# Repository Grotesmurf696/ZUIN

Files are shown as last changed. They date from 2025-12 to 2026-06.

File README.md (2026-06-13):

# ZUIN
*ZUIN helpt kinderen en ouders meer te weten te komen en bevorderd communicatie over energieverbruik in huis* 

🛠️ Built by ``Sam Verkimpe``  & ``Maxim Depever`` & ``Jitse Van Laer ``  
🔥 Supervised by ``prof. dr. Bas Baccarne``, ``Yannick Christiaens`` & ``Wouter Devriese``    
🌱 Grown at ``Ghent University`` 🏛️ ``Industrial Design Engineering`` ([project overview](https://github.com/basbaccarne/human-centered-design))       

*Latest update: 13/06/2026*   

## General overview
ZUÏN is een systeem van interactieve producten voor kinderen, interfaces voor de ouders en meetapperatuur voor jouw huis. 

Het bevordert de kennis over energieverbruik bij kinderen, terwijl ze op een speelse en interactieve manier zuinig leren vebruiken. Ook initieert het de interactie tussen ouder en kind om zo ook hun een steentje te laten bijdragen.

Kinderen weten vaak niet hoe energieverbruik echt in elkaar zit en welk apparaat nu het meeste verbruikt. Niet alleen de kinderen maar ook de ouders weten niet dat hun dagelijkse routines soms roet in het energieverbruik gooien. 

Aan het midden van ZUIN ligt het horloge. Dit horloge is gemaakt voor kinderen. Het horloge wordt gebruikt als normaal uurwerk doorheen de dag, maar wanneer de kinderen thuis komen krijgt dit horloge een extra functie. Een virtuele en speelse interface waardat op een overzichtelijke manier een beeld wordt geschept van het ogenblikkelijk energieverbruik in huis.
<p align="center">
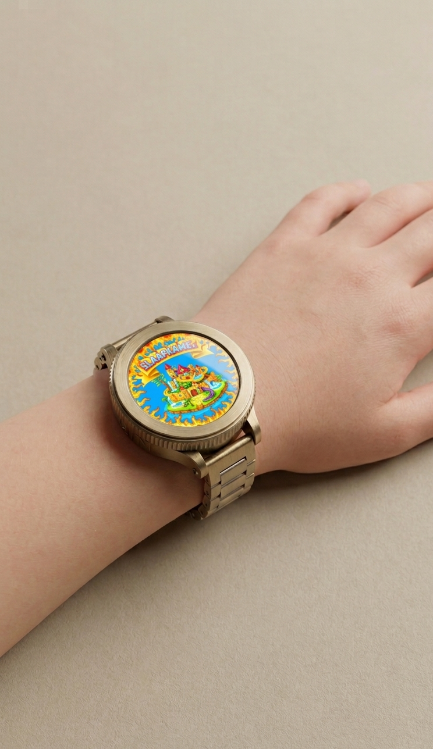
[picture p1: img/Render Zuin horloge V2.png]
  
  <br>
  <em>Figuur 1: Representatie van het ZUIN horloge.</em>
</p>

## Introductie
Energieverbruik in huishoudens vormt een belangrijk maatschappelijk en ecologisch vraagstuk. Hoewel technologische oplossingen zoals digitale meters en monitoring-applicaties steeds vaker worden ingezet, blijft het energieverbruik voor veel gebruikers abstract en moeilijk te interpreteren. In gezinscontexten wordt dit probleem nog complexer, omdat energieverbruik het resultaat is van gedeelde routines en gedragingen, waarbij ook kinderen een belangrijke maar vaak onbewuste rol spelen.

Kinderen groeien op in een wereld waarin energie vanzelfsprekend beschikbaar is, zonder een duidelijk begrip van herkomst, kost of impact. Op school wordt wel een basis van milieubewustzijn aangeleerd, maar vooral het voorbeeld en de druk van de ouders maakt effectief verschil (Aguirre-Bielschowsky et al., 2018) [^1] . Klassieke energiefeedback zoals apps, grafieken en cijfers sluiten nauwelijks aan bij de leefwereld van kinderen. Bovendien ervaren ook de ouders het energieverbruik vaak als een “black box”: ze krijgen wel cijfers te zien, maar missen concrete, begrijpbare aanknopingspunten om hun dagelijks gedrag bij te sturen. Energie wordt ervaren als iets onzichtbaars: het is er altijd, komt uit het stopcontact, en verdwijnt weer zonder duidelijke koppeling tussen gedrag en gevolg. Dit maakt het moeilijk om duurzame gewoontes aan te leren, zeker bij jonge gebruikers.

Vanuit deze problematiek werd **ZUIN** ontwikkeld: een **interactief** systeem dat energieverbruik op een **speelse** en **begrijpbare** manier zichtbaar maakt voor kinderen, en tegelijk de **dialoog tussen ouder en kind** stimuleert. Het project focust niet op het technisch optimaliseren van installaties, maar op **bewustmaking, educatie en langdurige gedragsverandering** via dagelijkse **interactie en betekenisvolle** feedback.

## Inhoudstafel

1. [Methodologie](./docs/methodologie.md)
2. [Discovery](./docs/discovery.md)
3. [Definition](./docs/definition.md)
4. [Develop I](./docs/Develop_I.md)
5. [Develop II](./docs/Develop_II.md)
6. [Develop III](./docs/Develop_III.md) 
7. [Design Requirements](./docs/design_requirements.md)
8. [Bill of materials](./docs/bom.md)
9. [Conclusie](./docs/Conclusie.md)

## Kritische reflectie
Tijdens dit project werd onderzocht hoe kinderen een rol kunnen spelen in het stimuleren van energiebewust gedrag binnen gezinnen. Door kinderen centraal te plaatsen, werd een vernieuwende invalshoek gekozen. Gedurende het project werden verschillende onderzoeksmethoden toegepast, zoals interviews, benchmarking, prototyping, usability testing en systeemanalyse. Deze combinatie van methodes leverde waardevolle inzichten op in zowel het probleem als mogelijke oplossingsrichtingen.

Een sterke kant van het project was het iteratieve ontwerpproces en het gebruik van snelle prototypes. In een vroege fase werden eenvoudige kartonnen modellen gebruikt om ideeën snel tastbaar te maken en reacties van gebruikers te observeren. In latere fases werden prototypes verder verfijnd met 3D-geprinte onderdelen en een fysieke knuffel voor één van de concepten. Hierdoor konden interacties realistischer getest worden en konden gebruikers concreter feedback geven op de verschillende interfaces.

Elke wave werden participanten voor gebruikerstesten op een andere manier gerekruteerd. Op die manier is er een insteek van een brede waaier aan verschillende meningen in ons project, en zijn we niet beperkt tot maar enkele mensen uit hetzelfde milieu.

In de definition-fase konden we een stand opzetten op dag van de Wetenschap in de UGent Campus Kortrijk. Hier kregen we inzichten van enkele gemotiveerde en geïnteresseerde kinderen, maar ook hun ouders hielpen ons proces verder. 

Daarna maakten we in wave 1 en 2 van de develop-fase gebruik van de faciliteiten van bibliotheek de Krook. We konden ons daar in de inkomhal zetten en zo konden mensen met interesse vrijwillig deelnemen. Dit waren compleet vreemden voor ons. Ze hadden dus ook geen vooroordeel. 

In wave 3 van deze fase, testten we de UX in een klas uit de lagere school. Ook deze kinderen hadden nog niet eerder over ZUÏN gehoord en leverde een nieuwe inkijk. Vanuit een andere hoek kregen we feedback over de CMF. Dit werd namelijk getest op de Scouts. 

Toch kent het project ook enkele beperkingen. Op bepaalde momenten tijdens de definition fase werd enigszins omgekeerd te werk gegaan in het ontwerpproces. Het product requirements document (PRD) werd namelijk deels beïnvloed door het reeds ontwikkelde concept, terwijl idealiter eerst de gebruikersvereisten duidelijk gedefinieerd worden voordat het product wordt vormgegeven. Hierdoor bestaat het risico dat sommige ontwerpkeuzes eerder voortkwamen uit het bestaande concept dan uit een grondige analyse van de behoeften.

Daarnaast had er tijdens de defenition fase meer aandacht besteed kunnen worden aan het marktpotentieel en de reële wenselijkheid van het product. Hier is later wel op teruggekeerd in de develop fase.

Een andere grote beperking in het ontwerp is de invloed op lange termijn. Deze wilden we testen met een ‘hub’ die de energiemeter nabootst en een ‘handheld’ die gelijkend is aan het horloge. De ‘hub’ zou op willekeurige momenten een signaal naar de ‘handheld’ sturen. Dit bootst een piekmoment van energie na. Het kind zou dan naar de ‘hub’ gaan en op de drukknop duwen. Op die manier zou het kind “de energie” uitzetten. Daarbij zou de ouder een korte vragenlijst krijgen om het gedrag van het kind op het moment van de trigger te analyseren. Deze test zou een meerdaagse test zijn, om te testen of het enthousiasme blijft. Echter zijn we daar niet geraakt. Door problemen bij het programmeren is de verbinding tussen de ‘hub’ en de ‘handheld’ pas veel later tot stand gekomen dan gewenst. Hierdoor was er niet meer voldoende tijd om de test nog effectief uit te voeren over meerdere dagen. Dit is zeker nog iets wat zou moeten gebeuren om de value promise van ZUÏN volledig te begrijpen. 

Deze test zou ook inkaart brengen welke triggers en beloningen motiveren. Het moeilijke bij triggers is dat deze moeten opvallen maar niet irriteren. Deze mogen het leven van het kind niet overnemen, maar wel duidelijk genoeg zijn dat het kind er niet overkijkt. Ook dit is iets wat pas zichtbaar is op lange termijn. Een trigger die eerst aantrekkelijk lijkt kan al snel gewoonte worden waardoor het kind er geen aandacht meer aan besteed. Andersom kan een leuke trigger ook snel irriteren. 

Beloningen is een groot onderdeel van ZUÏN. Dit is namelijk de drijfveer van de kinderen. Zeker bij kinderen is dit eveneens iets dat op langere termijn hard kan veranderen. Een kind van 8 tot 12 is veel aan het ontdekken en komt veel nieuwe dingen tegen. Hierdoor wisselen ze snel van interesses. Het is dus belangrijk om een beloningsysteem te gebruiken dat niet uit de mode gaat. We wilden dus eveneens testen bij de lange termijn test van de ‘hub’ en ‘wereable’ hoe motiverend en belangrijk het beloningsysteem daadwerkelijk is.  

## Noot inzake het gebruik van AI
AI werd in de verschillende fases ingezet om het ontwerpproces efficiënt te laten verlopen en te ondersteunen. 
Zo werd in elke fase gebruik gemaakt van een AI die spraak naar tekst convergeert. Zo konden we de opnamebestanden die we tijdens de interviews en testen maakten, om te zetten in een uitgeschreven tekst en dit samen te vatten. Dit gebruikten we ter ondersteuning van de notities die ook werden gemaakt, om zo geen enkele info te missen en al onze aandacht te besteden aan de gebruikers. Daarnaast werd AI gebruikt om de teksten waar nodig te corrigeren en presentabeler te maken.

* **Definition**
  
  Hier werd AI vooral ingeschakeld om efficiënt via Figma Make enkele interfaces te ontwerpen. Op deze manier konden we veel sneller starten met de gebruikerstesten en op     een efficiënte manier leren begrijpen wat de gebruiker nu echt wilt en wat absoluut niet.

* **Develop 1**

  Via ChatGPT werd een simpele brochure gemaakt die ZUÏN als extra aanbiedt bij een energieleverancier. Aangezien deze enkel werd gebruikt om de interviews iets realistischer te laten voelen, en de interviewee makkelijker te betrekken in het verhaal, moest deze niet van hoogste kwaliteit zijn maar eerder snel en praktisch. ChatGPT was hier dus een makkelijke tool om dit te realiseren. 

* **Develop 3**

  ChatGPT werd ingeschakeld om snel veel verschillende mascottes te ontwerpen die uniek zijn maar toch gebasseerd waren op bestaande figuren uit het leven van kinderen. Denk aan dieren die menselijk worden gemaakt, bekende figuren uit series waar hun eigen stijl verwerkt werd in een nieuw karakter of monstertjes waarvan hun persoonlijkheid weergegeven is. Op deze manier hadden we snel een grote hoeveelheid testmascottes om te testen welke visuele eigenschappen kinderen aanspreekt.
  Via Viscom werden de tekeningen van de kinderen omgezet in een werkelijke icoontje voor op de interface. Zo werd ZUÏN gemaakt door en voor kinderen.
  
## Bijlagen
### Discovery
* Literatuuronderzoek (N=6)
  * [Protocol](https://ugentbe-my.sharepoint.com/:w:/g/personal/sam_verkimpe_ugent_be/IQBxlSKGF6GJS7yjuUpZMrW6AZptKT-39_dlODdeOWtALXE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)
  * [Rapport](https://ugentbe-my.sharepoint.com/:w:/g/personal/sam_verkimpe_ugent_be/IQDwQceRXQxvRYp1WkRQ5hU9ATqJ7NlsP_gz0dTkeEDdwDY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)
* Interviews (N=3)
  * [Protocol](https://ugentbe-my.sharepoint.com/:w:/g/personal/sam_verkimpe_ugent_be/IQD2VJUlo9LuQ4IuZMF2TL-ZAamdP4Nqb100fHMXdAKGHLI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)
  * [Rapport](https://ugentbe-my.sharepoint.com/:w:/g/personal/sam_verkimpe_ugent_be/IQBQ63Hyc62xRqArzp_ORJG6AZmYlhGAdV6d9LZe_1P6jKk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)
* Benchmarkanalyse (N=10)
  * [Protocol](https://ugentbe-my.sharepoint.com/:w:/g/personal/sam_verkimpe_ugent_be/IQAMuHsYY4-KSaFa1XN27SYHATxGseCYW43dwTT9iTFHoIk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)
  * [Rapport](https://ugentbe-my.sharepoint.com/:w:/g/personal/sam_verkimpe_ugent_be/IQD2sjlyIDcPSKbX_eMs5qYrAX9bR0QHjSUwxY6TmReKtXE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)

### Definition
* User testing wave 1 (N=5)
  * [Protocol](https://ugentbe-my.sharepoint.com/:b:/g/personal/sam_verkimpe_ugent_be/IQDWMKsc2QKeSKaAeMUzAG5MAZcDLzCf8KAvd7KS3yiZGkY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)
  * [Rapport](https://ugentbe-my.sharepoint.com/:b:/g/personal/sam_verkimpe_ugent_be/IQBzZMysacB-S6drTZJ2RzhIAVSfR45oQEZheUL2pKdH228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)
* User testing wave 2 (N=5)
  * [Protocol](https://ugentbe-my.sharepoint.com/:b:/g/personal/sam_verkimpe_ugent_be/IQAnpSB6ntXoSrYw-srLekfjAZP3fpYSlYS78TLyiaTcl7U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)
  * [Rapport](https://ugentbe-my.sharepoint.com/:b:/g/personal/sam_verkimpe_ugent_be/IQADF7ljjY2cQKnFW2vlJumVAUnOLvhR5XoyOQKa8V-7RHU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)

### Develop I
* User testing (N=5)
  * [Protocol](https://ugentbe-my.sharepoint.com/:w:/g/personal/sam_verkimpe_ugent_be/IQB2XM7peNSuRbQRF3uczHEGATVunaRYGWqFntXtGxvA77w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)
  * [Rapport](https://ugentbe-my.sharepoint.com/:w:/g/personal/sam_verkimpe_ugent_be/IQDQ9hDgR9cTTZiRgUtarAb1AdrubkvxJy0Hyxt71XbfLM4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)
* Benchmarkanalyse (N=11)
  * [Protocol](https://ugentbe-my.sharepoint.com/:w:/g/personal/sam_verkimpe_ugent_be/IQBDr_LCedKySrZPzo6kyY3KATNcAo-kq3Sv-OK4WtQKtB8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)
  * [Rapport](https://ugentbe-my.sharepoint.com/:w:/g/personal/sam_verkimpe_ugent_be/IQA4UmP9nbFVTJZZt05vX_MHAeSgGLJWmo1RzYrxio9w0Pg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)

### Develop II
* User testing (N=5)
  * [Protocol](https://ugentbe-my.sharepoint.com/:b:/g/personal/sam_verkimpe_ugent_be/IQC0zx9CVL78SpjKY5UA-5loAbN_aFb7bocTbdqrQVW5oRU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)
  * [Rapport](https://ugentbe-my.sharepoint.com/:b:/g/personal/sam_verkimpe_ugent_be/IQBnZ75xSDf8TJpBHPW8dPKHAVxY7kzlbvRFUu8L-s8I4_s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)

### Develop III
* UX (N=5)
  * [Protocol](https://ugentbe-my.sharepoint.com/:w:/g/personal/sam_verkimpe_ugent_be/IQCE87OYLkPoSLeUEBKA8ZOGAW0-ACC2SsWIZ68aur9VZFU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)
  * [Rapport](https://ugentbe-my.sharepoint.com/:b:/g/personal/sam_verkimpe_ugent_be/IQD8igRDtaaSSI1ChPYGJ_cuAarO6yZDC9078CCVQc64zas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)
* CMF (N=3)
  * [Protocol](https://ugentbe-my.sharepoint.com/:w:/g/personal/sam_verkimpe_ugent_be/IQA1UCCAJ_TgQaXbTxmlKouZAayj0iKGaSXlccNmrM6srS8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)
  * [Rapport](https://ugentbe-my.sharepoint.com/:b:/g/personal/sam_verkimpe_ugent_be/IQCc59gRmQsRSLWiW1mBbghMAdhwbeE4el2uZ555LbgcBAo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)
## Licentie 

This repository contains both software and design materials created as part of an industrial design energineering project at Ghent University.

- **Software and code:** [MIT License](./LICENSE-MIT)  
- **Design, documentation, CAD, and media:** [CC BY 4.0 License](./LICENSE)
  
You are free to reuse and build upon this work, both commercially and non-commercially, as long as proper attribution is given to the original authors.

## Bronnen
 [^1]: Aguirre-Bielschowsky, I., Lawson, R., Stephenson, J., & Todd. S. (2018). _Kids and Kilowatts: Socialisation, energy efficiency, and electricity consumption in New Zealand_. Energy Research & Social Science, 44, 178-186. https://www.sciencedirect.com/science/article/pii/S2214629618303803

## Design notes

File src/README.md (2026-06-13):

# ZUIN — Software
  
## Introductie
 
ZUIN is een systeem van interactieve producten dat kinderen en ouders helpt bewuster om te gaan met energieverbruik thuis. Het systeem bestaat uit twee hardware-onderdelen: een **hub** en een **handheld**. De hub staat centraal in de woning en communiceert draadloos via Bluetooth Low Energy (BLE) met de handheld, die het kind draagt als een horloge.
 
Wanneer de hub detecteert dat een apparaat in huis energie verbruikt, stuurt hij een signaal naar de handheld. Het kind wordt hiervan op de hoogte gebracht via trillingen, een LED en een schermmelding. Door naar de hub te gaan en op de knop te drukken, leert het kind actief om apparaten uit te zetten.
  
De software van dit project is opgesplitst in twee delen:
 
- **Hub** — een Arduino-gebaseerd systeem dat BLE-signalen uitzendt en de interactie met de knop verwerkt.
- **Handheld** — in twee versies ontwikkeld. Versie 1 is een minimalistisch prototype met een LCD-scherm en haptic feedback. Versie 2 is een verbeterde versie met een rond kleurentouchscreen, een grafische LVGL-interface en een echte RTC-klok.

---

## Opstarten van de code
 
De code is opgesplitst in drie mappen: één voor de hub, één voor handheld v1 en één voor handheld v2.
 
### Hub
 
Om de hub op te starten, open je [`code_hub`](./codes/HUB/code_hub) in de Arduino IDE. Zorg dat de volgende libraries geïnstalleerd zijn:
 
- `ArduinoBLE`
- `rgb_lcd` (Grove LCD library)
- `Wire`
Upload de code naar het Arduino-bordje. Bij het opstarten toont het LCD-scherm "ZUIN HUB" en begint het bordje te adverteren als `ZuinHub` via BLE.
 
### Handheld v1
 
Open [`code_handheld_V1`](./codes/HANDHELD_V1/code_handheld_V1) in de Arduino IDE. Zorg dat de volgende libraries geïnstalleerd zijn:
 
- `ArduinoBLE`
- `rgb_lcd` (Grove LCD library)
- `Wire`
Upload de code naar het Arduino-bordje. De handheld scant automatisch naar de hub en verbindt zodra `ZuinHub` gevonden wordt.
 
### Handheld v2
 
Open [`code_handheld_v2`](./codes/HANDHELD_V2/code_handheld_v2) in de Arduino IDE. Dit project maakt gebruik van meerdere gegenereerde bestanden vanuit SquareLine Studio die zich bevinden in de map [`extra_bestanden_interface/`](./codes/HANDHELD_V2/extra_bestanden_interface). Zorg dat deze map samen met het hoofdbestand gebruikt wordt. De volgende libraries zijn vereist:
 
- `TFT_eSPI`
- `lvgl`
- `I2C_BM8563` (RTC)
- `BLEDevice`, `BLEUtils`, `BLEScan`, `BLEClient` (ESP32 BLE stack)
- `lv_xiao_round_screen`
- `Wire`
Upload de code naar de Seeed XIAO ESP32S3. Het scherm toont bij het opstarten de huidige tijd en de handheld begint automatisch te scannen naar `ZuinHub`.
 
---
 
## Functioneel schema
 
Onderstaand schema toont de volledige logica van het systeem: links de hub, rechts de handheld. De groene stippellijnen geven de BLE-communicatie weer tussen beide apparaten.
 
<p align="center">
  

---

## Validatie inputs

### Knop (Hub)

De hub bevat een drukknop die de gebruiker (het kind) in staat stelt om aan te geven dat een apparaat uitgeschakeld is. De knop is verbonden op pin 2 van het Arduino-bordje. Wanneer de knop ingedrukt wordt terwijl een signaal actief is, roept de hub de functie `turnOffDevice()` aan. Het LCD-scherm toont vervolgens welk apparaat uitgeschakeld werd.

<p align ="center">
  

De code maakt gebruik van de `digitalRead()` functie van de standaard Arduino library.

### Touchscreen (Handheld v2)

De handheld v2 maakt gebruik van een capacitief touchscreen dat geïntegreerd is op de Seeed XIAO round display. Aanrakingen worden uitgelezen via de `chsc6x_get_xy()` functie uit de `lv_xiao_round_screen` driver. De touchcoördinaten worden doorgegeven aan LVGL via een input device driver (`lv_indev_drv_t`).

Wanneer een kind op de knop van de hub duwt, wordt dit via een LVGL event callback (`LV_EVENT_CLICKED`) verwerkt en verdwijnt het vlammetje.

<p align = "center">
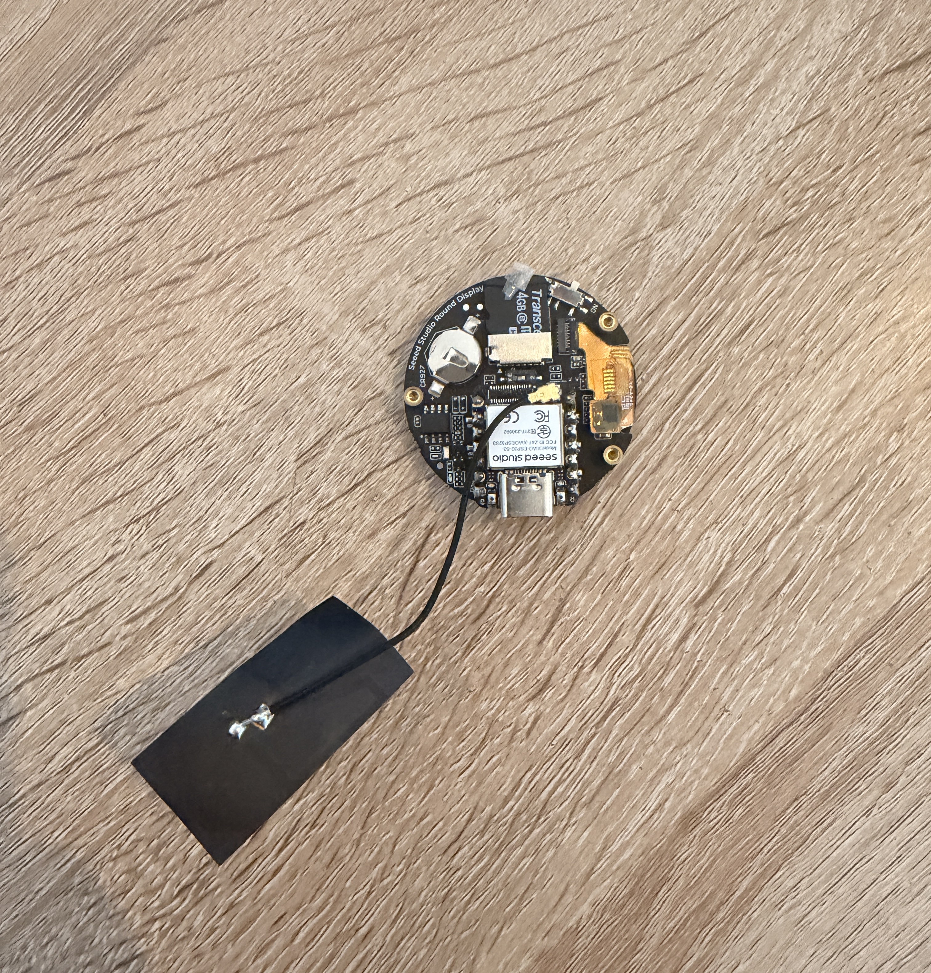
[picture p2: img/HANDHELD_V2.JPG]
  

---

## Validatie outputs

### LCD-scherm 16x2 (Hub & Handheld v1)

Zowel de hub als handheld v1 maken gebruik van een Grove RGB LCD-scherm met 16 kolommen en 2 rijen. Dit scherm toont de huidige toestand van het systeem in leesbare tekst.

**Hub:** toont bij opstart "ZUIN HUB", daarna "Wachten..." tijdens idle, "Apparaat aan! / Druk om uit" bij een actief signaal, en "Uitgezet: [apparaat]" na bevestiging.

**Handheld v1:** toont "ZUIN HANDHELD" tijdens idle, en "Apparaat aan! / Ga naar hub!" wanneer een signaal ontvangen wordt.

<p align = "center">
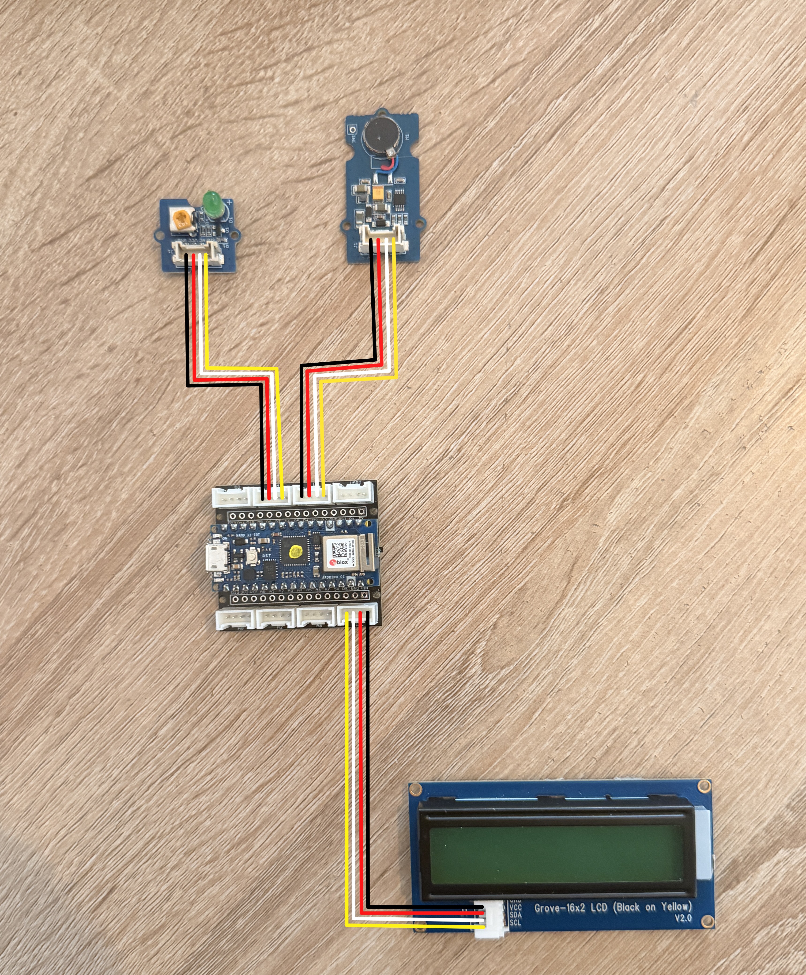
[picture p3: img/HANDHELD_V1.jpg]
  

De code maakt gebruik van de `rgb_lcd` library voor aansturing van het scherm via I2C.

### Rond TFT-kleurentouchscreen (Handheld v2)

De handheld v2 gebruikt een rond TFT-display van 240x240 pixels, aangestuurd via de `TFT_eSPI` library in combinatie met LVGL. De UI-schermen zijn ontworpen in SquareLine Studio en gegenereerd als C-bronbestanden (`ui_Screen1.c` t.e.m. `ui_Screen4.c`).

- **Screen 1** — hoofdscherm met lopende klok (via RTC)
- **Screen 2, 3, 4** — elk een ander vlammetje dat verschijnt bij een energiesignaal

<p align = "center">
  
  

De drie vlammetjes zijn opgeslagen als gecompileerde C-afbeeldingsbestanden (`ui_img_761137763.c`, `ui_img_1057345124.c`, `ui_img_1448235480.c`) en een achtergrond van een eiland (`ui_img_palm_trees_and_island_png_clipart_imag...c`).

### LED (Hub & Handheld v1)

**Hub:** twee LEDs geven de toestand van het systeem aan. De idle-LED (pin 6) brandt wanneer het systeem wacht. De action-LED (pin 4) brandt wanneer een signaal actief is.

**Handheld v1:** één LED op pin 4 licht op wanneer een signaal ontvangen wordt van de hub.

<p align = "center">
   
  

De LEDs worden aangestuurd via `digitalWrite()`.

### Haptic motor (Handheld v1)

De handheld v1 bevat een haptic motor op pin 6. Wanneer een signaal ontvangen wordt, trilt de motor drie keer kort (`300ms aan, 200ms uit`). Dit geeft het kind een tastbare melding zonder dat het naar het scherm hoeft te kijken.

<p align = "center">
  

### RTC-klok (Handheld v2)

De handheld v2 bevat een I2C BM8563 RTC-module die de huidige tijd bijhoudt. De tijd wordt elke seconde uitgelezen en weergegeven op het hoofdscherm via een LVGL label (`ui_ClockLabel`). De RTC is verbonden via SDA (pin 5) en SCL (pin 6).

<p align = "center">
  

De code maakt gebruik van de `I2C_BM8563` library.

---

## BLE communicatie

De hub en handheld communiceren draadloos via **Bluetooth Low Energy (BLE)**. Beide apparaten gebruiken dezelfde service- en characteristic-UUID's:

- **Service UUID:** `95ff7bf8-aa6f-4671-82d9-22a8931c5387`
- **Characteristic UUID:** `95ff7bf8-aa6f-4671-82d9-22a8931c5388`

De hub fungeert als **peripheral**: hij adverteert zich als `ZuinHub` en schrijft `"SIGNAL"` of `"IDLE"` naar de characteristic.

De handheld fungeert als **central**: hij scant naar `ZuinHub`, verbindt, en subscribet op de characteristic via notify. Bij disconnect herverbindt de handheld automatisch (elke 5 seconden opnieuw scannen).

| Waarde | Betekenis |
|---|---|
| `"SIGNAL"` | Een apparaat verbruikt energie — kind moet actie ondernemen |
| `"IDLE"` | Apparaat uitgeschakeld — systeem terug in rust |

---

## Handheld v1 vs v2

| Eigenschap | Handheld v1 | Handheld v2 |
|---|---|---|
| Microcontroller | Arduino (ArduinoBLE) | Seeed XIAO ESP32S3 |
| Scherm | 16x2 LCD tekst | Rond 240x240 TFT kleurentouchscreen |
| UI | Tekstueel | LVGL grafische interface (SquareLine Studio) |
| Klok | ❌ | ✅ RTC (BM8563) |
| Feedback | LED + haptic motor (3x trillen) | Visuele vlammetjes op scherm |
| Touch | ❌ | ✅ Capacitief touchscreen |
| BLE library | `ArduinoBLE` | `BLEDevice` (ESP32 stack) |

---

## Gebruikte libraries

### Hub & Handheld v1

| Library | Functie |
|---|---|
| `ArduinoBLE` | Bluetooth Low Energy communicatie |
| `rgb_lcd` | Aansturing Grove RGB LCD-scherm via I2C |
| `Wire` | I2C communicatie |

### Handheld v2

| Library | Functie |
|---|---|
| `TFT_eSPI` | Aansturing TFT-display via SPI |
| `lvgl` | Grafische UI-library voor embedded systemen |
| `lv_xiao_round_screen` | Display- en touchdriver voor Seeed XIAO round display |
| `I2C_BM8563` | RTC-module voor tijdsbeheer |
| `BLEDevice` / `BLEClient` | Bluetooth Low Energy (ESP32 stack) |
| `Wire` | I2C communicatie |

---

## Licentie

- **Software en code:** [MIT License](LICENSE)

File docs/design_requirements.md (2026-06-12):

### PRD-ZUIN

|**ID** | **Design requirement** | **Bron** | **Datum** | **Al geïntegreerd**|
| :--- | :--- | :--- | :--- | :--- |
| **Groep 1: Educatie en bewustwording** | | | | |
|1.1 | Het product moet kinderen inzicht geven in energieverbruik op een speelse manier | Userinterview Wave 1 | 23/11/2025 | Ja|
|1.2 | Het systeem moet ouders stimuleren om samen met kinderen energie te besparen | Userinterview Wave 1 | 23/11/2025 | Ja|
|1.3 | Het product moet educatieve waarde hebben en bijdragen aan gedragsverandering | Userinterview Wave 1 | 23/11/2025 | Ja|
|1.4 | Educatieve content, zoals quizzen of verhaaltjes, moet direct geïntegreerd worden in het spel| Interview Develop I |08/03/2026 | Ja|
|**Groep 2: Onboarding en Instructie**| | | | |
|2.1 | Er moet een duidelijke onboarding/uitleg zijn voor de iconen en functies | Usability Test Wave 2 | 06/12/2025 | Ja|
|2.2 | De interface moet intuïtieve navigatie (zoals swipes) ondersteunen die na herhaling duidelijk is | Usability Test Wave 2 | 06/12/2025 | Ja|
|2.3 | Onduidelijke dropdown-menu's moeten worden vermeden in de navigatiestructuur | Usability Test Wave 2 | 06/12/2025 | Ja|
|**Groep 3: Feedback en Interface** | | | | |
|3.1 | Feedback moet aantonen in welke kamer er veel verbruikt wordt | Userinterview Wave 1 | 23/11/2025 | Ja|
|3.2 | Het product moet duidelijke visuele feedback geven | Userinterview Wave 1 | 23/11/2025 | Ja|
|3.3 | Het product moet extra fysieke feedback/triggers geven | Userinterview Wave 1 | 23/11/2025 | Ja|
|3.4 | Feedback moet duidelijk maar niet opdringerig zijn | Userinterview Wave 1 | 23/11/2025 | Ja|
|3.5 | Tekstgrootte en iconen moeten geoptimaliseerd zijn voor leesbaarheid door kinderen | Usability Test Wave 2 | 06/12/2025 | Ja|
|3.6 | Notificaties moeten subtiel en rustig blijven, zonder constant trillen of overmatige visuele/auditieve prikkels te geven. |Interview Develop I |08/03/2026 | Ja|
|3.7 | Componenten in de gebruikersinterface op het aanraakscherm moeten minimaal 17,5 mm dik zijn om correcte invoer te verzekeren. | Antropometrie Develop II | 11/04/2026 | Ja |
|3.8 | Tekstgroottes moeten passend zijn voor de doelgroep, gebaseerd op afmetingen die gebruikelijk zijn in kinderboeken (8 tot 12 jaar). | Ergonomie Develop II | 11/04/2026 | Ja |
|**Groep 4: Gamification en motivatie** | | | | ||
|4.1 | Het product moet visuele spel-elementen en beloningen bevatten | Userinterview Wave 1 | 23/11/2025 | Ja|
|4.2 | Er moet positieve feedback worden gegeven bij goed gedrag | Userinterview Wave 1 | 23/11/2025 | Ja|
|4.3 | Het product moet kinderen motiveren door emotionele elementen | Userinterview Wave 1 | 23/11/2025 | Ja|
|4.4 | De interface moet een motiverende metafoor (zoals de "brand") bevatten | Usability Test Wave 2 | 06/12/2025 | Ja|
|4.5 | Personalisatie-opties moeten worden uitgebreid om engagement te verhogen | Usability Test Wave 2 | 06/12/2025 | Neen|
|4.6 | Het product moet een virtueel huisdier bevatten als speelse motivatie.|Interview Develop I |08/03/2026 | Ja|
|4.7 | Competitie-elementen moeten focussen op de gezinscontext (gezinscompetitie) in plaats van externe competitie. |Interview Develop I|08/03/2026 | Ja|
|4.8 | Het product moet regelmatig nieuwe challenges en duidelijke, meetbare doelen aanbieden, zoals een douche-timer. |Interview Develop I|08/03/2026 | Neen|
|4.9 |De gamification mag tegelijkertijd niet verslavend of overweldigend zijn. |Interview Develop I|08/03/2026 | Ja|
|4.10 | Het virtuele karakter moet ronde vormen, grote ogen en schattige proporties (zoals een grote kop en klein lichaam) bevatten om vertrouwen te wekken. | Rapport UX Develop III | 10/05/2026 | Ja |
|4.11 | Het visuele ontwerp van het karakter moet eenvoudig en puur blijven; scherpe hoeken en drukke, chaotische details moeten vermeden worden. | Rapport UX Develop III | 10/05/2026 | Ja |
|**Groep 5: Hardware en Duurzaamheid**| | | | |
|5.1 | Het product moet draagbaar, compact en eenvoudig zijn | Userinterview Wave 1 | 23/11/2025 | Ja|
|5.2 | Geen overbodige smart-technologie (focus op essentie) | Userinterview Wave 1 | 23/11/2025 | Ja|
|5.3 | Het product moet betaalbaar zijn voor de doelgroep | Userinterview Wave 1 | 23/11/2025 | /|
|5.4 | Het ontwerp moet simpel en intuïtief zijn en mag geen complexe of overdreven "flashy" features bevatten.|Interview Develop I|08/03/2026 | Ja|
|5.5 | Een roterende fysieke draaiknop mag maximaal een draaikracht van 2,7 kg vereisen voor vlotte bediening met duim en wijsvinger. | Antropometrie Develop II | 11/04/2026 | Ja |
|5.6 | De polsband moet ontworpen zijn voor fijne polsen met vergaande instelbaarheid (marges vanaf minimaal 2,70 cm tot 4,01 cm dikte). | Antropometrie Develop II | 11/04/2026 | Ja |
|5.7 | Het horloge moet een smalle "fitbit"-achtige form factor krijgen en mag niet log of te breed ontworpen zijn. | Usertest Develop II | 11/04/2026 | Neen |
|5.8 | Het product moet paradoxaal genoeg zwaarder aanvoelen (ca. 59 gram) om een "steviger" en functioneel "premium" gevoel te waarborgen. | Usertest Develop II | 11/04/2026 | Ja |
|5.9 | Het toestel moet primair te navigeren zijn met behulp van een fysieke draairing. | Usertest Develop II | 11/04/2026 | Ja |
|5.10 | Ter aanvulling op de navigatie moet er een visueel duidelijke fysieke linkerknop aanwezig zijn. | Usertest Develop II | 11/04/2026 | Neen |
|5.11 | Het horlogebandje moet bij voorkeur een stalen of metaal-look uitstralen om een 'premium' perceptie te creëren. | CMF Rapport Develop II | 10/05/2026 | Ja |
|5.12 | De behuizing moet een speelse, herkenbare afwerking krijgen (bijv. knoppen-detaillering) die aansluit bij de doelgroep. | CMF Rapport Develop II | 10/05/2026 | Ja |
|5.13 | De tactiele ring (draairing) moet een uitgesproken rib-profiel hebben met een gebalanceerde weerstand voor een aangename en intuïtieve haptische 'snap'. | CMF Rapport Develop II | 10/05/2026 | Ja |
|**Groep 6: Connectiviteit en App-integratie** | | | | ||
|6.1 | Het systeem moet een gekoppelde app-omgeving hebben (ook voor ouders) | Userinterview Wave 1 | 23/11/2025 | Neen|
|6.2 | De app moet inzicht geven in verbruik en educatieve tips aanbieden | Userinterview Wave 1 | 23/11/2025 | Ja|
|6.3 | De informatie-architectuur moet herzien worden; verhaaltjes moeten eenvoudig vindbaar zijn | Usability Test Wave 2 | 06/12/2025 | Ja|
|6.4 | Er moeten duidelijke rapporten en overzichten van het gedrag (zichtbare progressie) gegenereerd worden. | Interview Develop I|08/03/2026 | Neen|
|**Groep 7: Doelgroep, positionering en privacy** | | | | ||
|7.1 |Het product richt zich primair op de doelgroep van kinderen tussen 8 en 12 jaar oud. | Interview Develop I|08/03/2026 | Ja|
|7.2 | Het product moet dusdanig laagdrempelig zijn dat het geen extra tijdsdruk of mentale belasting vormt voor ouders.| Interview Develop I|08/03/2026 | Ja|
|7.3 | Het product moet transparant zijn over datagebruik en de privacy strikt respecteren. | Interview Develop I|08/03/2026 | Ja|
|7.4 | Bij eventuele distributie via een energieleverancier mag het product niet aanvoelen als een marketinginstrument.| Interview Develop I|08/03/2026 | Ja|

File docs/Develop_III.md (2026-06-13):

# Develop III

## Doelstellingen

In deze fase wordt het ontwerp verder verfijnd langs twee grote assen: de **UX & Service Design** en de **CMF (Colour, Material & Finish)**. Het doel is om het product emotioneel betekenisvol te maken voor de doelgroep en de materiaalkeuzes te onderbouwen vanuit gebruikersonderzoek.

Concreet wordt onderzocht:
- Welke emoties het product moet oproepen bij kinderen en ouders
- Hoe de mascotte, de interface-eilanden en de micro-interacties het beste worden vormgegeven
- Welke materialen, afwerkingen en tactiele eigenschappen kinderen verkiezen voor het horloge

## Materiaal & methoden

### UX & Service Design (N=5)

Om de UX te onderbouwen werd een combinatie van methodes ingezet:

- **Emotioneel ontwerp**: opstellen van een emotionele doelstellingenkaart voor ouders en kinderen als ontwerpkader
- **Deskresearch** (literatuur rond antropomorfisme, parasociale relaties bij kinderen, UI-design voor 8–12-jarigen)
- **Interview (N=5)**: kinderen uit het 4e leerjaar (Basisschool Klim-Op Grobbendonk, 30/04/2026) — personage-sorting, vriendenboek en quote-koppeling
- **Droomeiland-oefening**: twee klassen (4e en 5e leerjaar) ontwerpen hun droomeiland als input voor de eiland-thema's
- **Benchmarkanalyse** van kindvriendelijke apps, sites en tv-programma's (Ketnet, Subway Surfer, Animal Crossing, Roblox, Disney)
- **Customer journey** en **service blueprint** als service design instrumenten

### CMF (N=3)

Om de materiaalkeuzes te onderbouwen werden usability tests afgenomen met kinderen uit de Woudlopertak van de scouts (9–12 jaar) op zondag 10 mei 2026. De test was opgedeeld in 3 boards, elk met een ander CMF-aspect. De kinderen beoordeelden elk artefact op een 7-punts Likertschaal (1 = zeer slecht → 7 = zeer goed), stelden een persoonlijke voorkeursvolgorde op en gaven een korte motivering.

- **Board 1**: vier bandjes (stalen horloge, smartwatch, groot horloge, roze synthetisch leer) — aanvoelen rond de pols
- **Board 2**: vier horlogebehuizingen (2A–2D) — visuele en tactiele beoordeling van afwerking en knoppen
- **Board 3**: vier 3D-geprinte prototypes (3A–3D) met verschillende ribprofielen op de draaibare ring — haptische kwaliteit

## Resultaten

### UX & Service Design (N=5)

#### Emotioneel ontwerp

Het emotioneel ontwerp vertrekt vanuit de vraag: *"Welke emoties moet het product oproepen?"* Dit vormt het kader voor alle verdere ontwerpbeslissingen.

| Gebruiker | Gewenste emotie | Ontwerpimplicatie |
| --- | --- | --- |
| Ouders | Trots | Kind leert zelfstandig over verbruik |
| Ouders | Opluchting | Minder discussie ("doe het licht uit!") |
| Ouders | Samenwerking | Ouder en kind samen, niet tegenover elkaar |
| Kinderen | Autonomie | Kind beslist zelf om minder te verbruiken |
| Kinderen | Uitdaging | Beter doen dan gisteren |
| Kinderen | Verbondenheid | Met ouders én met de virtuele vriend |
| Kinderen | Trots | Iets goed doen zonder dat ouders erachter zitten |
| Kinderen | Begrip | Meer leren over verbruik |

> ⚠️ **Valkuil**: schuldgevoel ("Ik verbruik te veel") moet ten allen tijde vermeden worden. Dit stuurt de keuze voor positieve, motiverende feedback in de interface en bij de mascotte.

#### Deskresearch

Uit literatuur rond antropomorfisme en parasociale relaties bij kinderen (o.a. ACM CHI 2024) blijkt:
- Kinderen leren beter wanneer ze een band opbouwen met een personage
- Een combinatie van universele personages (monsters) én herkenbare figuren werkt het best
- Neutrale personages alleen zijn onvoldoende: kinderen moeten ook personages zien die op henzelf lijken

Voor de interface werd een benchmarkanalyse uitgevoerd van Ketnet, Subway Surfer, Cut the Rope, Animal Crossing, Roblox en Disney, aangevuld met de 12 Disney animatieprincipes voor UI-design.

Op basis van de deskresearch werden via AI (ChatGPT) verschillende reeksen personages gegenereerd die als testmateriaal dienden tijdens de interviews. De reeksen varieerden in stijl: van schattige dieren en objecten tot monsters en meer volwassen Gumball-geïnspireerde figuren.

<p align="center">
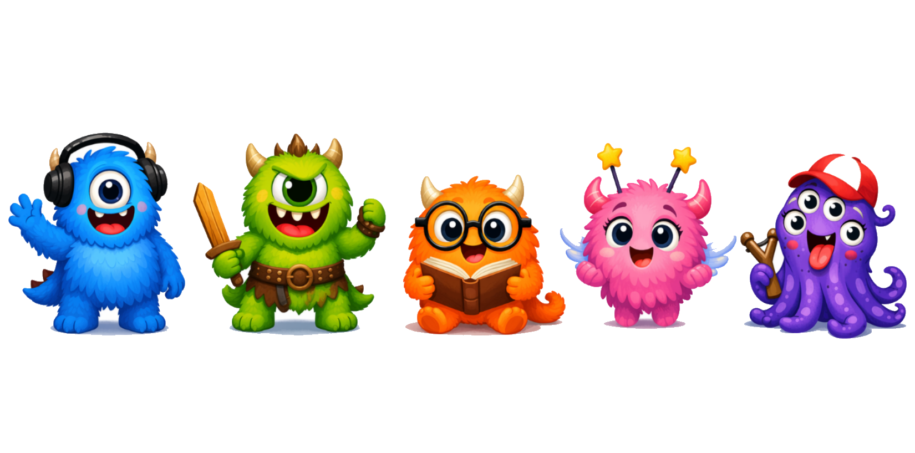
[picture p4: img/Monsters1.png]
  
  <br>
  <em>Figuur 5.1: Mascotte-ontwerp reeks 1: schattige dieren met ronde vormen.</em>
</p>

<p align="center">
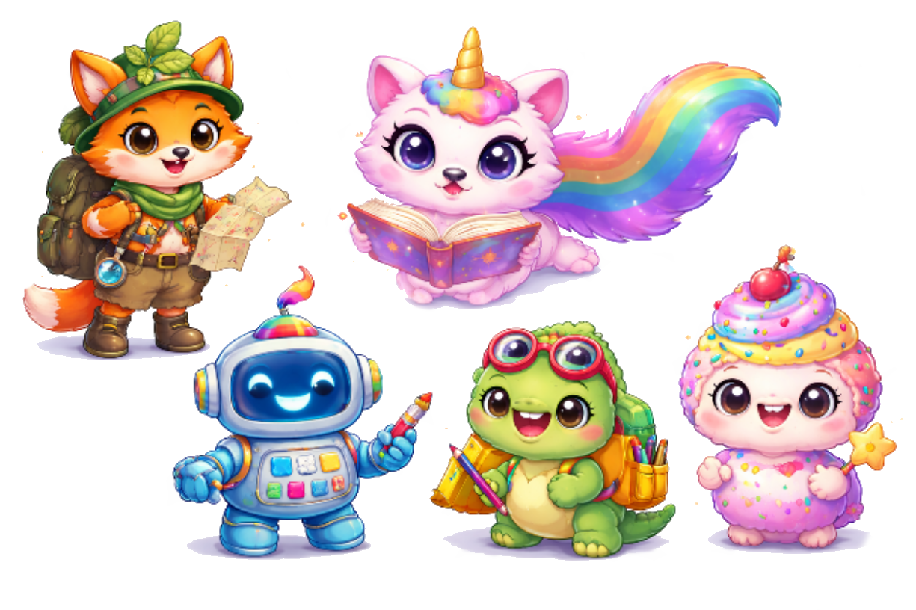
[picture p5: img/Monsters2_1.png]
  
  <br>
  <em>Figuur 5.2: Mascotte-ontwerp reeks 2: kleurrijke en expressieve monsters.</em>
</p>

<p align="center">
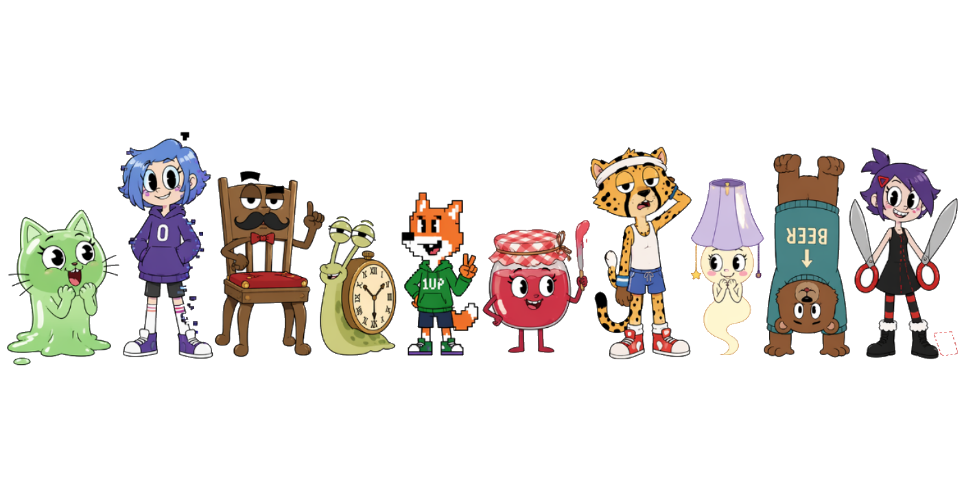
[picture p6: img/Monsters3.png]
  
  <br>
  <em>Figuur 5.3: Mascotte-ontwerp reeks 3: speelse, chaotische fantasiewezens.</em>
</p>

<p align="center">
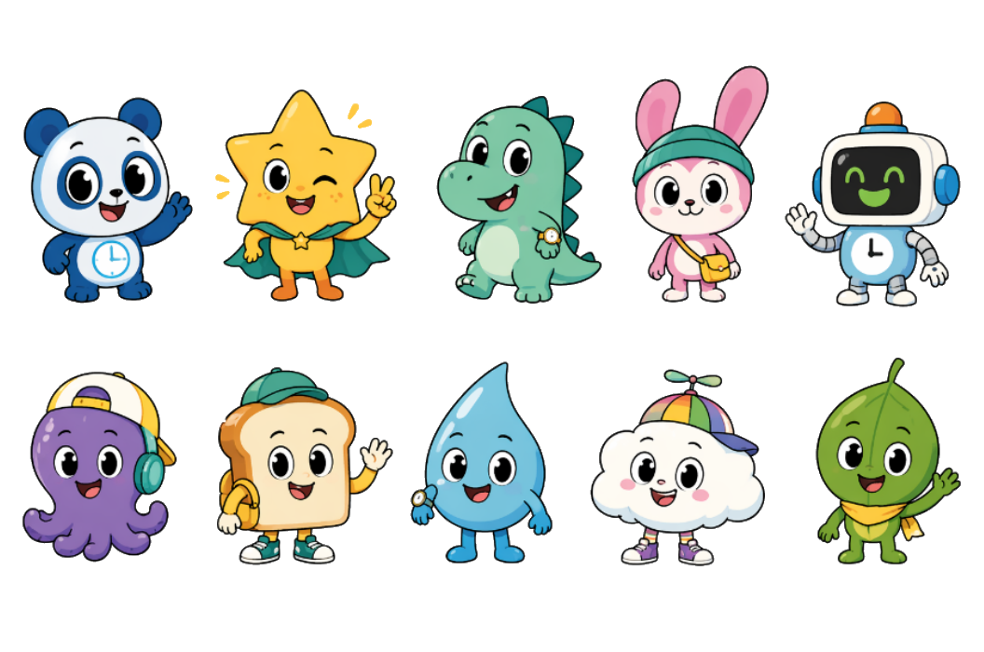
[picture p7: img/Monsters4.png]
  
  <br>
  <em>Figuur 5.4: Mascotte-ontwerp reeks 4: gestileerde, technologische robotfiguren.</em>
</p>

Uit deskresearch en benchmarkanalyse vloeiden volgende design requirements voort:

| # | Design requirement | Bron |
| --- | --- | --- |
| 01 | De mascotte combineert universele herkenbaarheid met voldoende variatie | Literatuur |
| 02 | Alles wat lijkt op een knop moet ook een functie uitvoeren | Benchmark |
| 03 | Knoppen minimaal 2×2 cm, voldoende ruimte ertussen | Deskresearch |
| 04 | Zo weinig mogelijk tekst; iconen en symbolen vanzelfsprekend | Benchmark |
| 05 | Directe feedback (visueel, auditief of haptisch) bij elke interactie | Benchmark |
| 06 | Maximaal 3–5 keuzes per scherm | Deskresearch |
| 07 | Lettergrootte > 14pt, eenvoudige taal, actieve zinnen | Deskresearch |
| 08 | Grote iconen (60×60 tot 80×80 pixels) | Deskresearch |
| 09 | Interface mag geen schuldgevoel opwekken, enkel motiveren | Emotioneel ontwerp |

#### Interview (N=5)

| Kind | Leerjaar | Datum | Plaats |
| --- | --- | --- | --- |
| Mila | 4 | 30/04/2026 | Basisschool Klim-Op Grobbendonk |
| Jana | 4 | 30/04/2026 | Basisschool Klim-Op Grobbendonk |
| Sterre | 4 | 30/04/2026 | Basisschool Klim-Op Grobbendonk |
| Jarne | 4 | 30/04/2026 | Basisschool Klim-Op Grobbendonk |
| Simon | 4 | 30/04/2026 | Basisschool Klim-Op Grobbendonk |

Uit het vriendenboek en de sorting-oefening kwamen 5 personagetypes naar voren:

| Type | Kenmerken | Voorbeeldpersonages |
| --- | --- | --- |
| Betrouwbaar / zacht | Vriendelijk, sociaal veilig, niet bedreigend | Blaadje, Grote Ster, Panda |
| Sociaal / speels | Actief, nieuwsgierig, extravert | Vosje, Konijntje, Avonturier |
| Chaotisch / impulsief | Grappig, speels chaotisch, comic relief | Monsters (Blauw monster, Octo) |
| Stoer / assertief | Zelfzeker, territoriaal | Draco, Draakje, Drilly |
| Neutraal / slim | Betrouwbaar maar minder emotioneel warm | Robotje, AI-kleurrobot |

Quotes die kinderen koppelden aan de meest vertrouwde personages illustreren welk type het beste past bij de rol van begeleider/coach in het horloge:

> *"Gaan we samen spelen?"* → Blaadje, Robotje, Draco

> *"Goed bezig!"* → Henk, Louise, Fristi

> *"Ik heb een geheim, maar je mag dit aan niemand vertellen."* → Blaadje, Grote Ster, Louise

Personages werden verworpen als vriend wanneer ze een object bij hadden: *"Die kan mijn geheim opschrijven in zijn boek"*, *"Die heeft een zwaard bij"*. Dit toont aan dat de context rond een personage even zwaar weegt als het uiterlijk zelf.

De visuele kenmerken die vertrouwen opwekken:

| Kenmerk | Vertrouwen | Wantrouwen |
| --- | --- | --- |
| Vorm | Rond, afgerond | Scherp, hoekig |
| Ogen | Groot, open | Klein, half dicht |
| Proporties | Groot hoofd, klein lichaam | Menselijke proporties |
| Details | Eenvoudig | Druk, veel details |
| Kleur | Blauw/groentinten | — |

**Design requirement (10):** de mascotte heeft ronde vormen, grote ogen, een groot hoofd ten opzichte van het lichaam en een eenvoudig kleurenpallet in blauw/groentinten.
<p align="center">
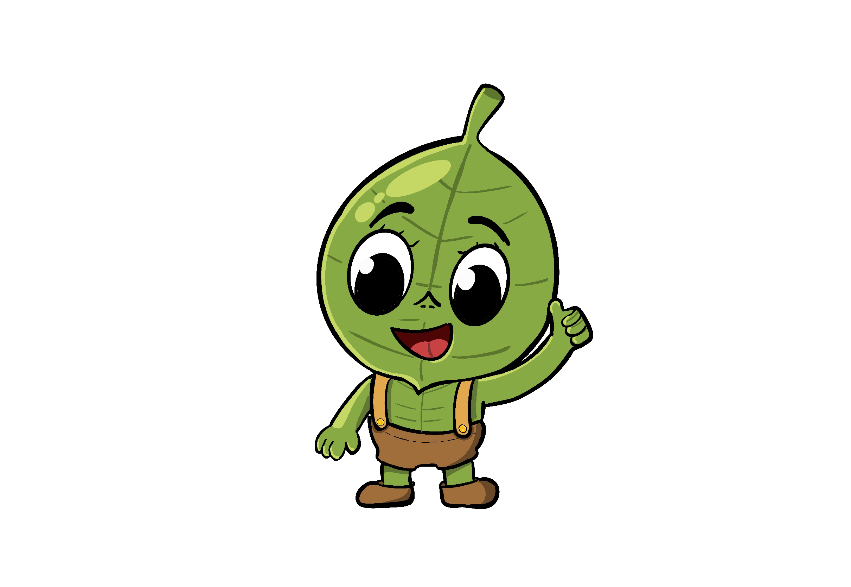
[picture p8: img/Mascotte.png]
  
  <br>
  <em>Figuur 5.5: Leaf de mascotte.</em>
</p>

Voor de eiland-thema's leverden twee klassen (4e en 5e leerjaar) input via een droomeiland-oefening. De kinderen kregen een leeg eiland-template en mochten dit naar eigen fantasie invullen. De meest voorkomende elementen waren glijbanen, hoge gebouwen en dieren. Deze worden verwerkt in de eilandthema's en via Vizcom visueel uitgewerkt.

<p align="center">
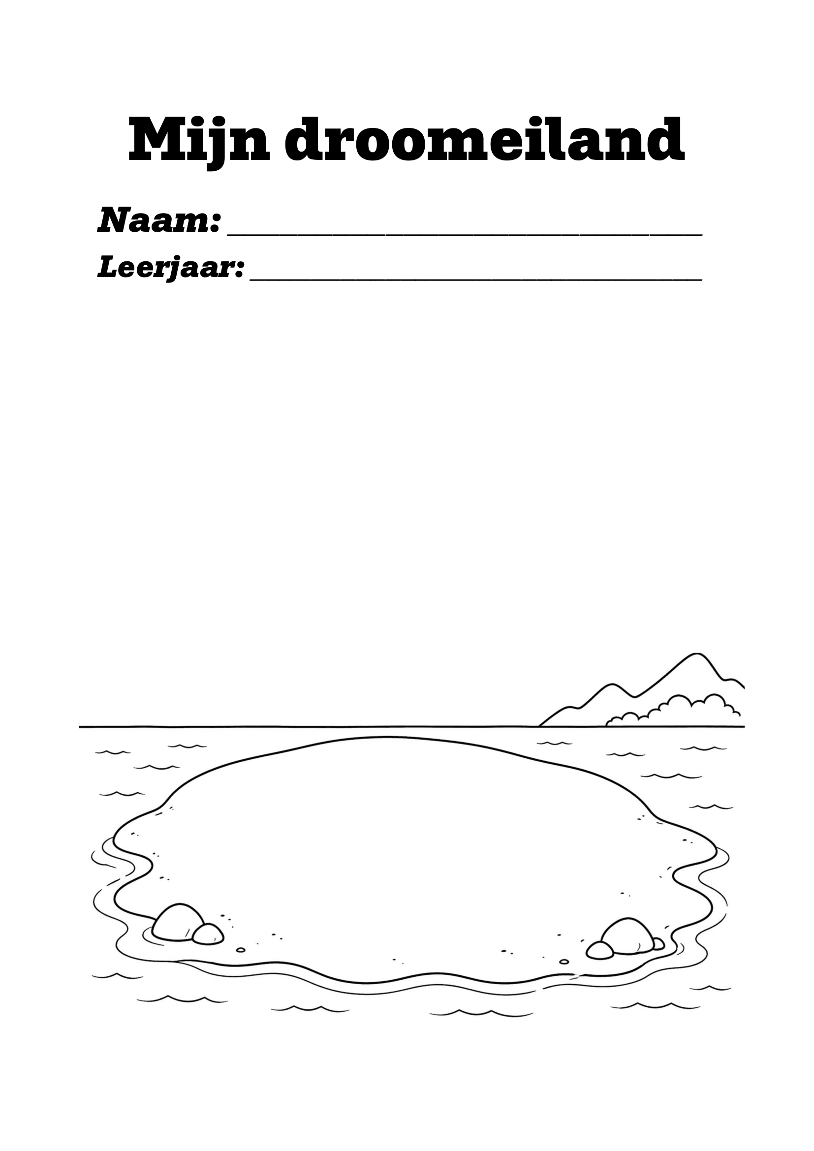
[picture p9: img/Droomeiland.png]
  
  <br>
  <em>Figuur 5.6: Droomeiland-oefening: input basisschoolkinderen voor interface-thema's.</em>
</p>

<p align="center">
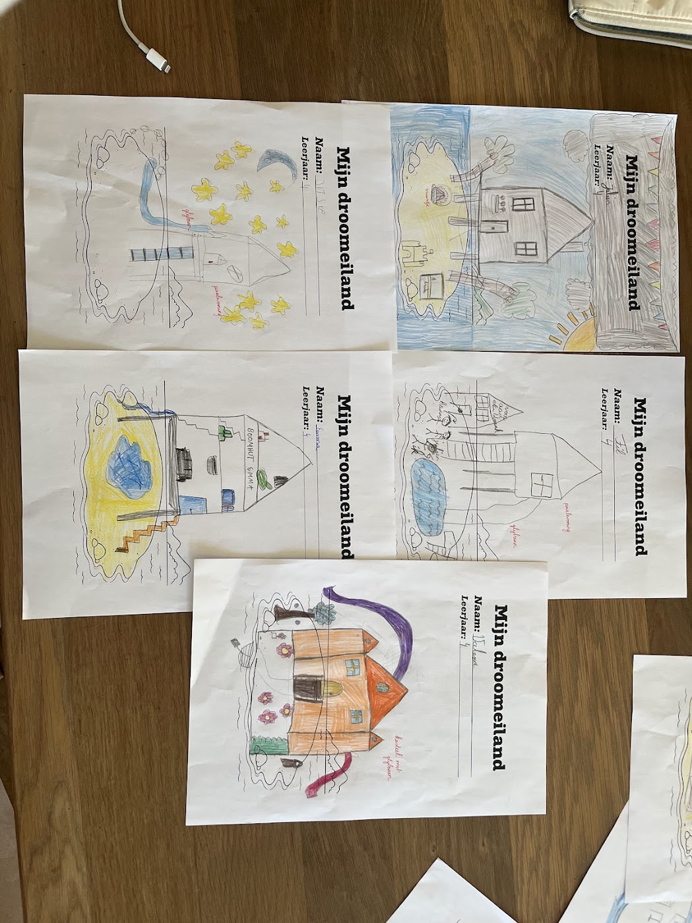
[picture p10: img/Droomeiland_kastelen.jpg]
  
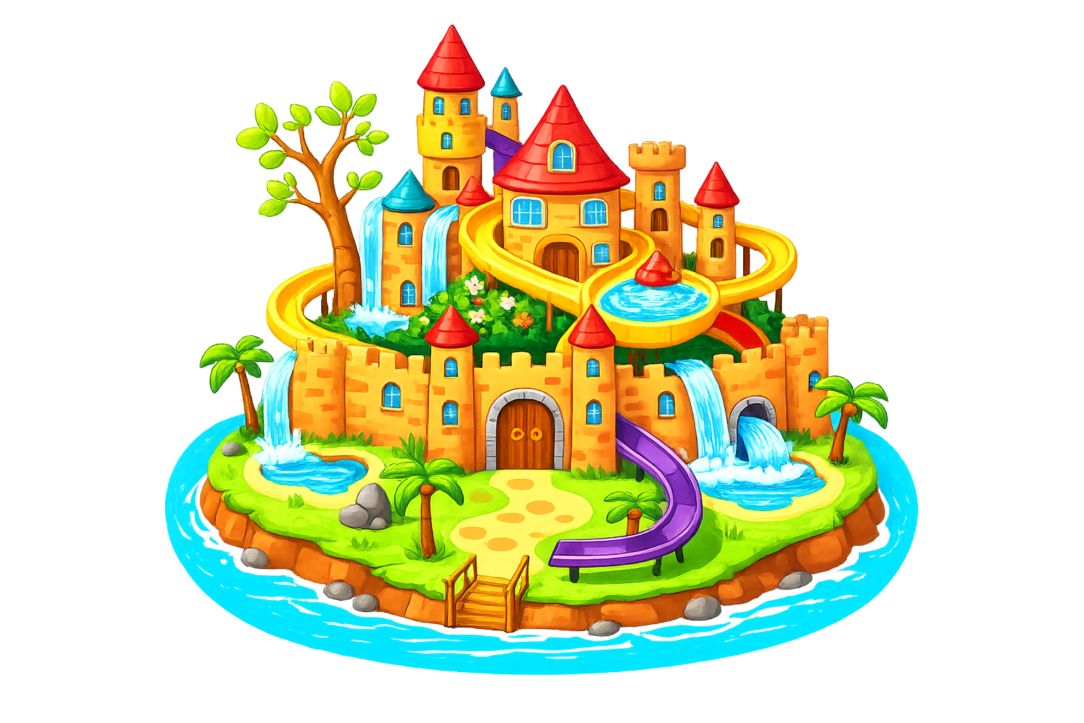
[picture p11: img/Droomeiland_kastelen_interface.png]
  
  <br>
  <em>Figuur 5.7: Droomeiland Kasteel.</em>
</p>

<p align="center">
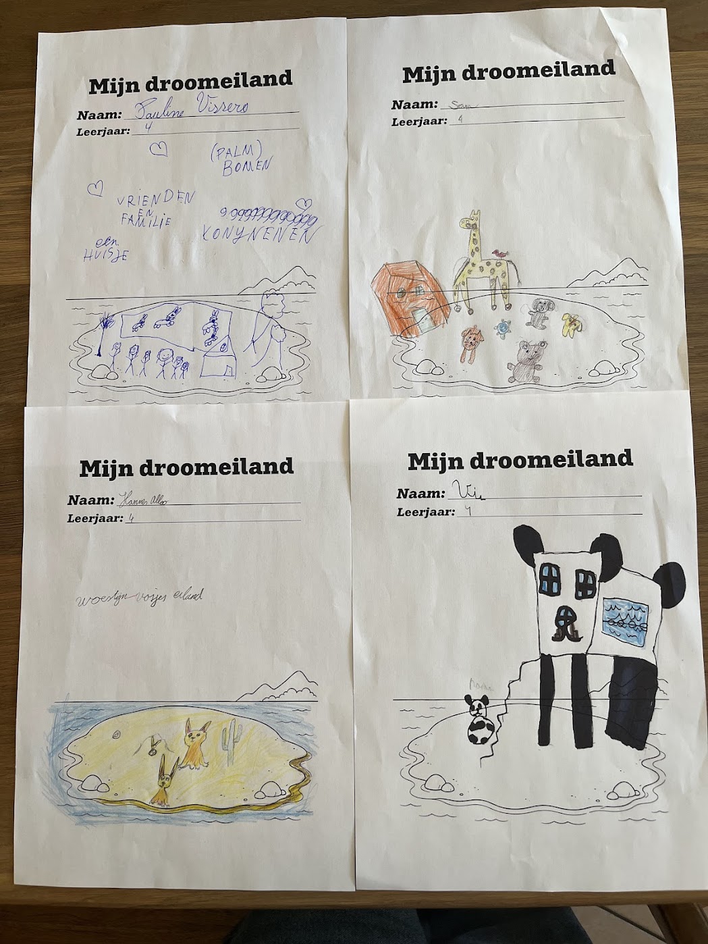
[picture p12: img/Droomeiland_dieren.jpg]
  
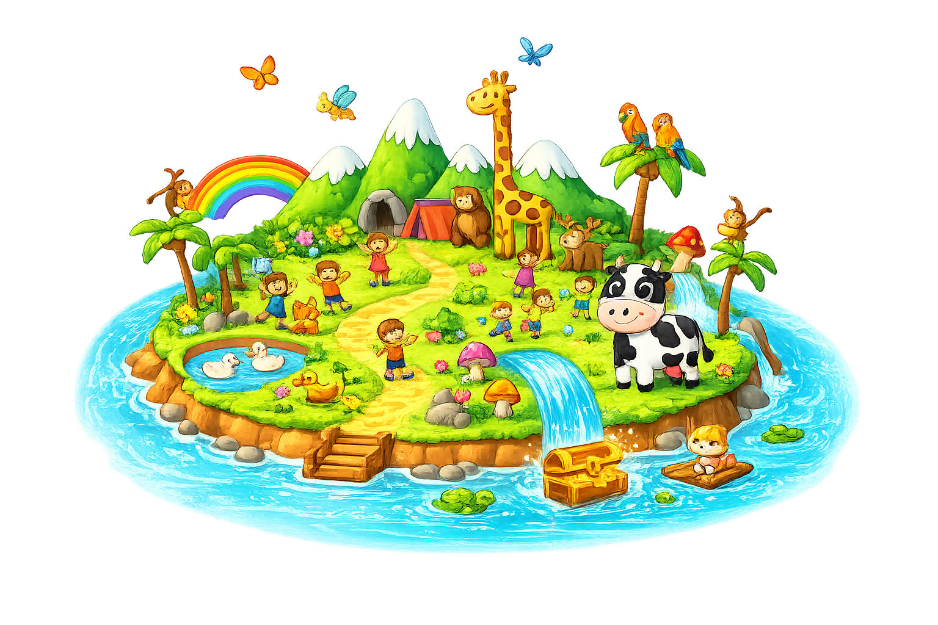
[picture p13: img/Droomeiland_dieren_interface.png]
  
  <br>
  <em>Figuur 5.8: Droomeiland Dieren.</em>
</p>

<p align="center">
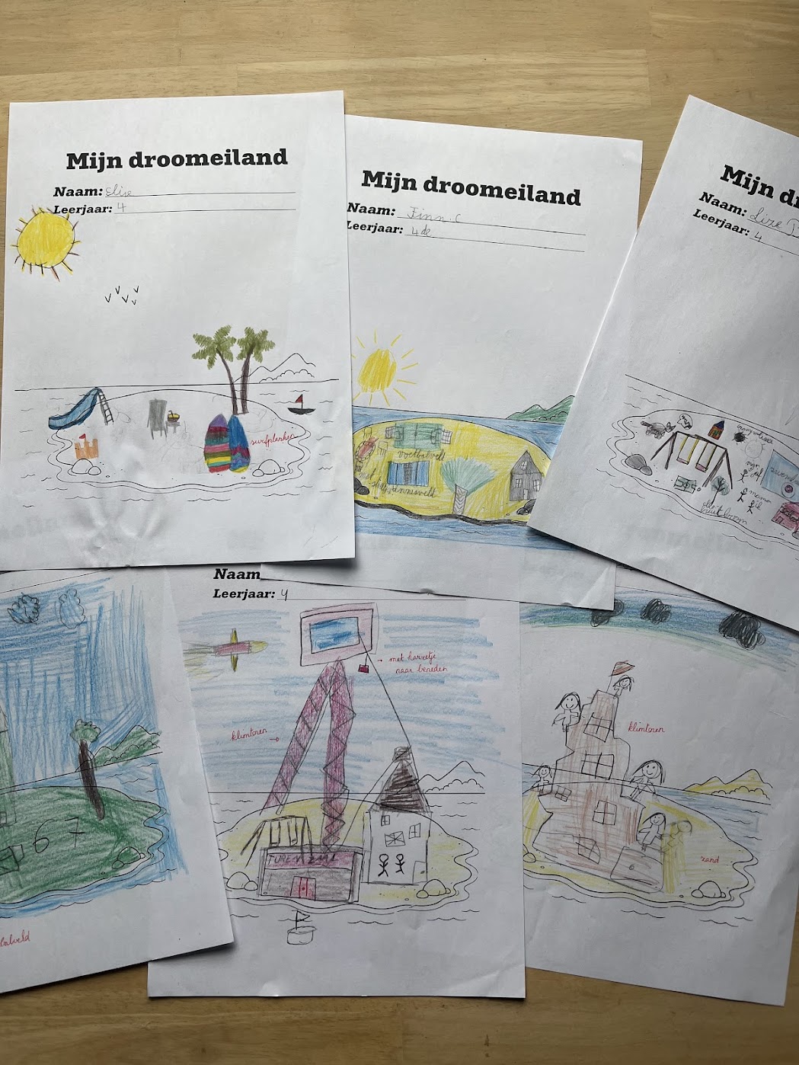
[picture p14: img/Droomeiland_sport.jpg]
  
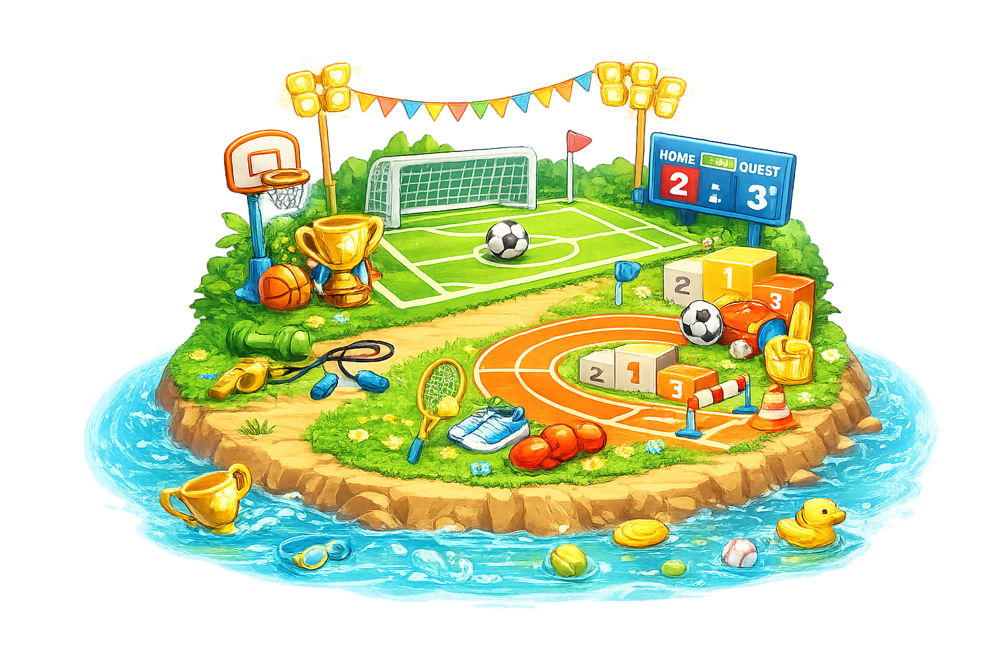
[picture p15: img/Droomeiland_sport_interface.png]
  
  <br>
  <em>Figuur 5.9: Droomeiland Sport.</em>
</p>

#### Service design

De customer journey uit Develop I werd aangevuld met duidelijkere grenzen voor wat er vóór, tijdens en na het gebruik plaatsvindt. De journey loopt van de eerste confrontatie met een hoge energiefactuur, over de aanschaf en introductie van het horloge, tot de dagelijkse interactie en langetermijngedragsverandering binnen het gezin.

Aan de hand van het storyboard werd een service blueprint opgesteld. Per frame worden de fysieke acties van de gebruiker en de achterliggende systemen in kaart gebracht, met aandacht voor de betrokkenheid van het kind, de ouder, het horloge, de stroomtrackers en de data-infrastructuur.

### CMF (N=3)

Om de kinderen te rekruteren werd een flyer uitgedeeld aan de Woudlopers na afloop van hun activiteit op 2 mei. De test zelf vond plaats op zondag 10 mei om 13u30 op de scouts.

<p align="center">
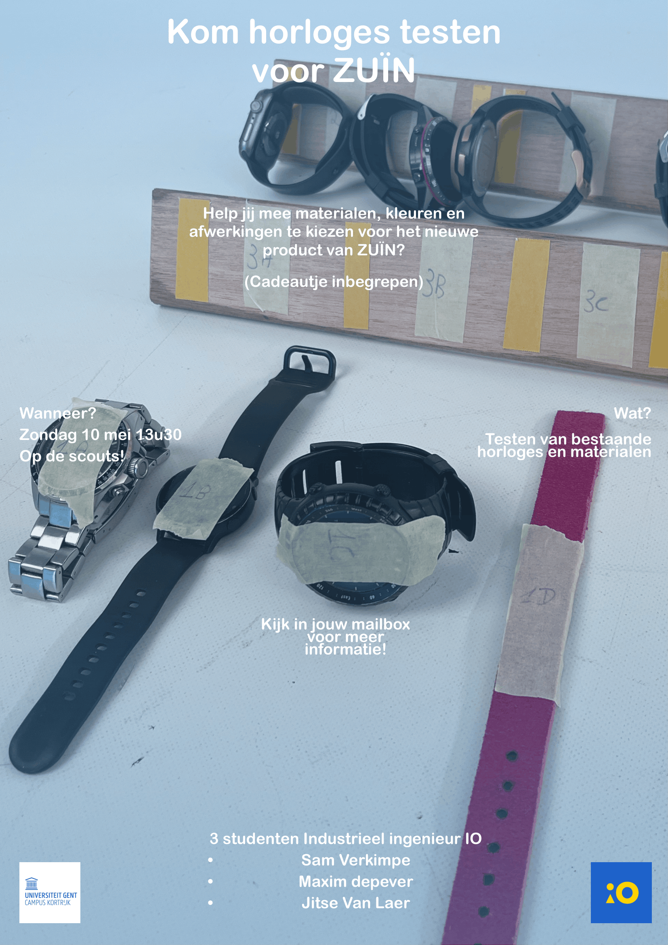
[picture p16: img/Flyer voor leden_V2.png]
  
  <br>
  <em>Figuur 5.10: Rekruteringsflyer: CMF-usability tests bij de Scouts Woudlopers.</em>
</p>

De testopstelling bestond uit drie boards naast elkaar op één tafel, elk met de bijhorende vragenlijst en de te evalueren artefacten.

<p align="center">
  
  <br>
  <em>Figuur 5.11: CMF-testopstelling: boards voor bandjes, behuizingen en tactiele ringen.</em>
</p>

| Deelnemer | Leeftijd | Datum | Locatie |
| --- | --- | --- | --- |
| Melvin | 9–12 | 10/05/2026 | Scouts – Woudlopers |
| Lisa | 9–12 | 10/05/2026 | Scouts – Woudlopers |
| Soni | 9–12 | 10/05/2026 | Scouts – Woudlopers |

<p align="center">
  
  <br>
  <em>Figuur 5.12: CMF-usability testing: tactiele beoordeling door Scouts-deelnemers.</em>
</p>

#### Board 1 – Bandmateriaal (N=3)

De vier bandartefacten zijn een klassiek stalen horloge-bandje, een zachte siliconenband van een smartwatch, het bandje van een groot digitaal horloge en een synthetisch lederen bandje (roze). De kinderen droegen elk bandje om de pols en beoordeelden het op aanvoelen.

| Deelnemer | Stalen horloge | Smartwatch | Groot horloge | Roze bandje | Voorkeur |
| --- | --- | --- | --- | --- | --- |
| Melvin | 7/7 | 1/7 | 2/7 | 1/7 | 1. Stalen horloge |
| Lisa | 6/7 | 6/7 | 7/7 | 5/7 | 1. Groot horloge |
| Soni | 6/7 | 6/7 | 2/7 | 7/7 | 1. Roze bandje |
| **Gemiddeld** | **6.3/7** | **4.3/7** | **3.7/7** | **4.3/7** | |

Het stalen horloge-bandje scoort het meest consistent (gemiddeld 6,3/7) en wordt door geen enkele deelnemer laag beoordeeld. Melvin omschrijft het als *"koud en zwaar"*, wat aansluit bij eerder onderzoek waarin een zeker gewicht als 'premium' wordt ervaren. Het roze synthetisch leren bandje toont de grootste spreiding (1–7/7) en is daarmee het meest polariserend.

**Conclusie board 1:** het stalen of metaal-look bandje verdient de voorkeur als standaardoptie; synthetisch leer kan als aanpasbare variant worden aangeboden.

#### Board 2 – Afwerking & finish behuizing (N=3)

Vier horloges met verschillende afwerkingen (glans, mat, geborsteld, knoppen-detail) werden naast elkaar geplaatst. De kinderen mochten de horloges vasthouden en bekijken maar niet omdoen. De focus lag op het visuele en tactiele oordeel over de behuizing en de knoppendetaillering.

| Deelnemer | Horloge 2A | Horloge 2B | Horloge 2C | Horloge 2D | Voorkeur |
| --- | --- | --- | --- | --- | --- |
| Melvin | 6/7 | 7/7 | 4/7 | 2/7 | 1. Horloge 2B |
| Lisa | 5/7 | 4/7 | 6/7 | 6/7 | 1. Horloge 2B |
| Soni | 5/7 | 2/7 | 7/7 | 5/7 | 1. Horloge 2C |
| **Gemiddeld** | **5.3/7** | **4.3/7** | **5.7/7** | **4.3/7** | |

Horloge 2C heeft het hoogste Likert-gemiddelde (5,7/7), maar horloge 2B wordt door 2 van de 3 deelnemers als eerste gekozen. Melvin en Lisa benadrukken het speelse knoppen-detail: *"Omdat er leuke puntjes in de knoppen zitten"*, *"leuke knoopjes, veel knopjes"*. Horloge 2D scoort zowel in Likert als ranking consequent het laagst.

**Conclusie board 2:** horloge 2B-stijl (knoppen-detaillering) is de aanbevolen primaire finish-richting; horloge 2C-stijl (cleane afwerking) is een geschikt alternatief. Horloge 2D wordt afgeraden.

#### Board 3 – Tactiele ring (N=3)

Vier 3D-geprinte prototypes (3A–3D) met elk een ander ribprofiel en een andere weerstand op de draaibare ring werden beoordeeld op haptische kwaliteit. De kinderen draaiden aan alle vier de ringen.

| Deelnemer | Ring 3A | Ring 3B | Ring 3C | Ring 3D | Voorkeur |
| --- | --- | --- | --- | --- | --- |
| Melvin | 1/7 | 3/7 | 7/7 | 4/7 | 1. Ring 3C |
| Lisa | 7/7 | 5/7 | 4/7 | 6/7 | 1. Ring 3A |
| Soni | 3/7 | 5/7 | 7/7 | 4/7 | 1. Ring 3C |
| **Gemiddeld** | **3.7/7** | **4.3/7** | **6.0/7** | **4.7/7** | |

Ring 3C springt er sterk uit: het hoogste gemiddelde (6,0/7) en de voorkeur van 2 van de 3 deelnemers. Melvin motiveert: *"Omdat je er goed aan moet draaien en het niet zo rap draait"* — een gedoseerde weerstand die bewuste bediening vereist. Lisa vormt een uitzondering en verkiest ring 3A: *"Het is niet te hard, maar anders vind ik het ook goed."*

**Conclusie board 3:** ring 3C wordt aanbevolen als uitgangspunt voor het definitieve ringprofiel. Ring 3A kan als lichtere variant worden overwogen.

#### Algemene aanbevelingen

| Onderdeel | Aanbeveling | Alternatief |
| --- | --- | --- |
| Bandje | Stalen / metaal-look | Synthetisch leer (aanpasbaar) |
| Behuizing-finish | Knoppen-detaillering (2B-stijl) | Cleane afwerking (2C-stijl) |
| Tactiele ring | Ringprofiel 3C (gedoseerde weerstand) | Ring 3A (lichtere weerstand) |

> **Beperking**: de steekproefgrootte (N=3) laat geen statistisch significante uitspraken toe. De resultaten zijn kwalitatief indicatief en dienen als input voor de volgende ontwerpiteratie. Een aanvullende kleurenronde is voorzien om de CMF-ervaring volledig te valideren.

## Software

Na de Develop III-fase werd er verder gewerkt aan het **coderen** en het **finaliseren van het horloge-ontwerp**. Het uiteindelijke ontwerp kan niet volledig voldoen aan alle eerder opgestelde design requirements: gezien de robuuste componenten waarmee gewerkt wordt, is dat in de praktijk vrijwel onmogelijk.

Alle informatie omtrent de code en software is terug te vinden in de map [`src`](../src).

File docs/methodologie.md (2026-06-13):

## Methodologie
In dit onterwerpproces werd het **Tripel Diamond model gevolgd**. Hierin stelt de eerste diamond de **discovery-fase** voor, de tweede diamond staat voor de **definition-fase** en de derde diamond wordt in het tweede semester uitgewerkt als een **develop- en deliver-fase**.

<p align="center">
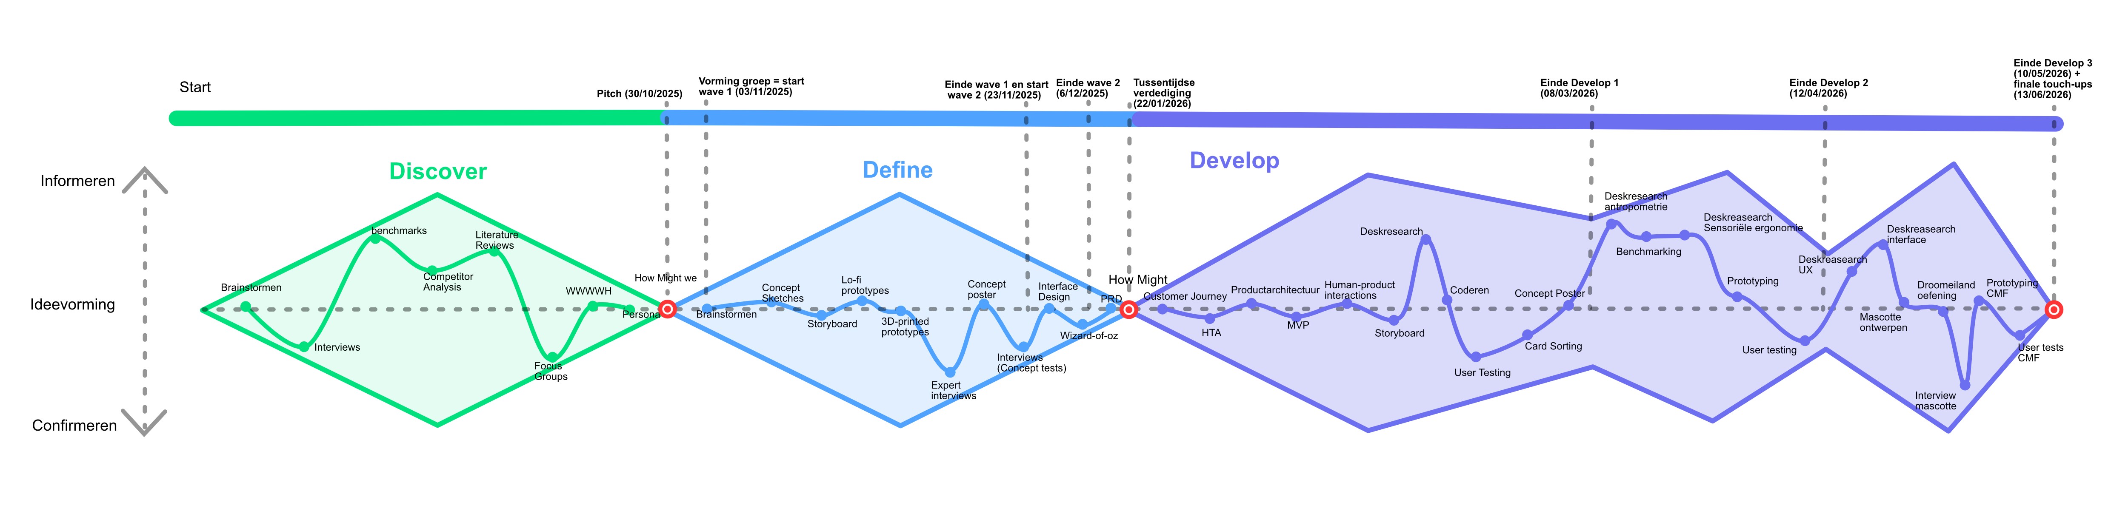
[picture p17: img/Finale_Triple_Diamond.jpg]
  
  <br>
  <em>Figuur 1: Triple Diamond-ontwerpproces: Discover, Definition en Develop & Deliver.</em>
</p>

<ins>**Discover**</ins>  
De discoveryfase richtte zich op het begrijpen van hoe mensen binnen het huishouden omgaan met energieverbruik en welke impact dit heeft op hun dagelijks leven. De focus lag op bewustzijn, gedrag en de rol van kinderen als onbewuste energieverbruikers.

Via **interviews (N=3)** werd nagegaan hoe bewust gezinnen omgaan met hun energieverbruik en welke triggers hen motiveren om te besparen. Dit werd aangevuld met een **benchmarkanalyse (N=10)** van bestaande slimme energieoplossingen en **deskresearch (N=6)** naar de grootste energieverbruikers in het huishouden. Hieruit bleek dat energieverbruik voor de meeste mensen onzichtbaar en verwarrend is, bestaande oplossingen te complex en te datagericht zijn, en dat kinderen onvoldoende betrokken worden bij energiebesparing. Er werd geconcludeerd dat er nood is aan een eenvoudige, visuele en kindvriendelijke manier om energieverbruik zichtbaar te maken en duurzaam gedrag te stimuleren.

<ins>**Definition**</ins>  
De definitionfase werd opgesplitst in twee waves.

**Wave 1** onderzocht welk productconcept kinderen het meest aanspreekt. Na het opstellen van een storyboard werden drie quick-and-dirty prototypes (knuffelbeer, horloge en tamagotchi-console) getest via **user feedback sessions (N=5)** en **dot-voting** op de Dag van de Wetenschap. Voorafgaand werd afgetoetst met een expert van Comon, die bevestigde dat kinderen vanaf 5 jaar al gehoord hebben van energieverbruik en dat gamification slechts 2–4 weken werkt zonder betekenisvolle interactie. Het horloge kwam als duidelijke favoriet naar voren: draagbaar, altijd bij het kind, en geschikt voor directe visuele feedback. Ouders stonden positief tegenover het educatieve doel, maar uitten bezorgdheden rond afval, prijs en onnodige hardware.

**Wave 2** richtte zich op de interface en informatie-architectuur. Drie interface-varianten werden getest via **Wizard-of-Oz-testing (N=5)** met het **Think Aloud Protocol** in De Krook. Kinderen voerden per interface drie taken uit: een kamer met hoog verbruik identificeren, het fantasie-eiland vinden en een verhaaltje opzoeken. Herhaling had een sterke positieve invloed op begrip en zelfstandigheid, maar de informatie-architectuur bleek structureel onduidelijk en de tekstgrootte te klein. Visuele eenvoud, grotere tekst en een duidelijkere navigatie werden daarom belangrijke ontwerpprincipes.

<ins>**Develop**</ins>  
De developfase werd opgesplitst in drie waves.

**Wave 1** richtte zich op het aanscherpen van de kernfunctionaliteit en het opbouwen van een systeemanalyse. Via een **customer journey**, **HTA**, **productarchitectuur** en **MVP-analyse** werd het ZUIN-concept technisch en functioneel uitgewerkt. Een **benchmarkanalyse** van smartwatches voor volwassenen (N=4), kinderen (N=3) en habit apps (N=4) leverde ontwerprichtlijnen op voor kindvriendelijke interactie: fysieke knoppen en een draairing, ondiepe informatiehiërarchie, gamification en visuele progressie. Via **semi-gestructureerde interviews met ouders (N=5)**, aangevuld met **card sorting**, werd de koopbereidheid en gewenste functionaliteit onderzocht. Ouders bleken energiebesparing belangrijk te vinden maar er zelden actief mee bezig te zijn; kinderen worden weinig betrokken, maar ouders zien daar wel potentieel in.

**Wave 2** verschoof de focus naar de ergonomische en antropometrische onderbouwing van het horloge. De drie touchpoints — draaiknop, aanraakscherm en polsband — werden onderbouwd via **literatuurstudie** naar laterale knijpkracht, wijsvingerbreedte en polsdikte bij kinderen van 8–12 jaar. Een **deskresearch (N=6)** vergeleek het gewicht van bestaande kinder- en volwassen smartwatches. Tijdens een **usertest (N=5)** in bibliotheek De Krook testten kinderen drie 3D-geprinte prototypes en een referentiehorloge (Samsung Gear S3). De meest opvallende bevinding was de paradox tussen theorie en praktijk: bij losse gewichtjes kozen kinderen het lichtste, maar bij een werkend horloge verkozen ze het zwaardere model (~59 g) omdat het als premium en steviger werd ervaren. Een slanke vormfactor met een klein scherm, een kleine band en een relatief zwaarder gewicht werd als optimaal ervaren.

**Wave 3** verfijnde het ontwerp langs twee assen: **UX & Service Design** en **CMF (Colour, Material & Finish)**. Voor de UX werd een emotioneel ontwerpkader opgesteld, aangevuld met **deskresearch** rond antropomorfisme en parasociale relaties bij kinderen. Via **interviews met kinderen (N=5)** in Basisschool Klim-Op Grobbendonk werd de mascotte gevalideerd door middel van personage-sorting, een vriendenboek en een quote-koppelingsoefening. Twee klassen leverden input via een **droomeiland-oefening** voor de interface-eilanden. Een **customer journey** en **service blueprint** brachten het volledige gebruikstraject in kaart. Voor de CMF werden **usability tests (N=3)** afgenomen bij Scouts-Woudlopers (9–12 jaar), waarbij drie boards — bandmateriaal, behuizingsafwerking en tactiele ring — werden beoordeeld via Likertschalen en voorkeurrangschikking. Hieruit bleek een voorkeur voor een metaal-look bandje, knoppen-detaillering op de behuizing en een ringprofiel met gedoseerde weerstand.

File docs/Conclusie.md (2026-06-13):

## Conclusie

Met **ZUÏN** werd onderzocht hoe kinderen tussen 8 en 12 jaar een actieve rol kunnen spelen in het energiebewust maken van een heel gezin. Het uitgangspunt was een herkenbaar probleem: energieverbruik is voor de meeste mensen een 'black box'. Het komt uit het stopcontact, verdwijnt weer, en de koppeling tussen gedrag en gevolg blijft onzichtbaar. Voor kinderen is die afstand nog groter, terwijl net zij via hun dagelijkse routines mee bepalen hoeveel een huishouden verbruikt.

Het antwoord werd niet gezocht in een app met grafieken en cijfers, maar in een systeem dat verbruik speels, zichtbaar en betekenisvol maakt. Centraal staat een kinderhorloge dat overdag gewoon de tijd toont, maar thuis verandert in een interactieve interface die het energieverbruik in huis vertaalt naar een wereld die kinderen begrijpen. 

Doorheen de **Tripel Diamond** (Discovery, Definition en drie Develop-waves) groeide ZUÏN van een ruw idee naar een onderbouwd concept. Een aantal kernkeuzes kwam daarbij telkens uit het gebruikersonderzoek zelf voort:

- **Een betrouwbare vriend in plaats van een corrigerende app.** Uit de UX-tests bleek dat een betrouwbare vriend enorm stimuleert voor kinderen om hun gedrag aan te passen. Dat inzicht leidde rechtstreeks tot **Leaf**, de mascotte die als coach en vriend door de interface gidst.
- **Motiveren, nooit beschuldigen.** ZUÏN geeft de piekmomenten weer met een **vuur-ring**. Door deze speelse weergave krijgen kinderen eerder het gevoel dat ze iets 'redden' dan dat ze iets fout doen. 
- **Vrijwillig in plaats van bevel.** Door kinderen autonomie te geven over het gebruik van het horloge, weerspiegelt hun gedrag zich rechtstreeks op henzelf. Ze ervaren de resultaten van hun keuzes en krijgen zo het gevoel dat ze écht iets goeds doen, een gevoel van eigenaarschap dat van binnenuit motiveert in plaats van opgelegd te worden.
- **Ouder en kind naast elkaar, niet tegenover elkaar.** Het horloge stimuleert het gesprek tussen ouder en kind. Vanuit de aanvankelijke onwetendheid van het kind ontstaat nieuwsgierigheid en uitleg, en groeit er een gedeelde betrokkenheid. Zo verschuift de dynamiek van "doe het licht uit!" naar samen iets bereiken.
- **Een tastbaar, kindgericht product.** De CMF- en antropometrie-tests vertaalden vage voorkeuren naar concrete keuzes: een draairing met een aangename haptische "snap", een instelbaar bandje voor fijne polsen, en een afwerking die premium oogt maar speels blijft.

<p align="center">
  
  <br>
  <em>Figuur 1: Interface ZUÏN.</em>
</p>

ZUÏN bestaat uit een eenvoudige interface die tot leven komt zodra het kind thuiskomt. Buitenshuis gedraagt ZUÏN zich gewoon als een normaal horloge.

De interface is opgebouwd uit verschillende eilanden, die elk een deel van het huis voorstellen.

Wanneer het verbruik in een bepaalde kamer piekt, verschijnt er een vuurring. Die geeft aan waar hulp nodig is: het kind moet het eiland redden door het piekmoment terug te dringen.

Doorheen de dag komt Leaf af en toe langs om het kind aan te moedigen en samen te onderzoeken hoe ze minder energie kunnen verbruiken. Zo wordt Leaf een echte vriend.

#### Beperkingen en wat nog ontbreekt

Een eerlijke conclusie erkent ook wat het project (nog) niet heeft kunnen aantonen. De belangrijkste open vraag betreft het **langetermijneffect**. De geplande meerdaagse test met de 'hub' en 'handheld', die piekmomenten van verbruik nabootst, kon door technische problemen met de verbinding niet meer tijdig worden uitgevoerd. Net die test moest twee cruciale dingen meten:
- of de triggers blijven opvallen zonder te gaan irriteren of tot gewoonte te verworden.
- of het beloningssysteem motiverend blijft voor een doelgroep die op deze leeftijd snel van interesse wisselt.

Zolang die meting ontbreekt, blijft de value promise van ZUÏN: duurzame gedragsverandering in plaats van een kortstondige nieuwigheid, deels een hypothese. Daarnaast verdienen het marktpotentieel en de reële wenselijkheid, net als enkele nog niet geïntegreerde requirements (zoals de gekoppelde ouder-app en uitgebreidere personalisatie), verdere uitwerking.

_________

**ZUÏN** laat zien dat energiebewustzijn niet hoeft te starten bij cijfers, maar kan beginnen bij een verhaal, een personage en een gedeelde routine tussen ouder en kind. Door kinderen niet als toeschouwer maar als hoofdrolspeler te behandelen, opent het project een vernieuwende invalshoek op een hardnekkig maatschappelijk probleem. Het concept staat stevig op gebruikersonderzoek; de volgende stap is om het over een langere periode in een echte gezinscontext te valideren. Pas dan wordt duidelijk of ZUÏN doet wat het belooft: kinderen én ouders blijvend en met plezier zuiniger laten leven.

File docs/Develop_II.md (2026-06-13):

# Develop II

## Doelstellingen

In deze fase verschuift de focus van technische functionaliteit naar de **ergonomische en antropometrische onderbouwing** van het horloge. De fysieke vormfactor en de drie belangrijkste touchpoints (draaiknop, scherm en polsband) worden geëvalueerd op basis van bestaande antropometrische data en aangevuld met een usertest waarin kinderen verschillende prototypes vergelijken.

Concreet wordt onderzocht:
- Welke afmetingen en krachten relevant zijn voor de doelgroep (8–12 jaar)
- Hoe de **range of motion** en het ervaren comfort zich verhouden tot vormfactor en gewicht
- Welke ergonomische principes (zien, horen, voelen) toegepast moeten worden in het ontwerp

## Materiaal & methoden

### Antropometrische analyse

De drie touchpoints van het horloge (ronde draaiknop, aanraakscherm en polsband) worden onderbouwd via een literatuurstudie. Voor elke touchpoint wordt een ontwerpprincipe gekozen (*design for the small*, *design for the tall* of *design for adjustability*) op basis van de specifieke gebruikssituatie.

### Deskresearch gewicht horloges (N=6)

Om een referentiekader te krijgen voor het gewicht van smartwatches werden zes bestaande modellen vergeleken: drie kinderhorloges (VTech Kidizoom, Garmin Vivofit Jr. 3 Marvel, Xplora X6 Play) en drie volwassen smartwatches (Samsung Galaxy Watch 6, Apple Watch Series 9, Garmin Fenix 8). Deze selectie sluit aan bij de benchmarkanalyse uit Develop I.

### Usertest antropometrie (N=5)

De test vond plaats in bibliotheek **De Krook**. Voorbijgaande gezinnen werden aangesproken en uitgenodigd om deel te nemen. De kinderen kregen drie 3D-geprinte prototypes (S, M en L) en één referentiehorloge (Samsung Gear S3, 59 g) om uit te testen. Voor de gewichtsperceptie werden bovendien losse gewichtjes gebruikt.

**Procedure:**
- Bij aanvang: vragen over leeftijd, links/rechtshandigheid en eerdere horloge-ervaring
- Vier proeven om realistisch gebruik na te bootsen: springtouwen, scherm aflezen, interageren met het horloge en wandelen
- Na afloop: korte vragen over voorkeur, ervaren gewicht en optimale maat

<p align="center">
  
  <br>
  <em>Figuur 4.1: Ergonomische prototypes: smartwatch-ontwerpen getest in De Krook.</em>
</p>

### Sensoriële ergonomie

Voor de tekstgrootte op het scherm werd inspiratie gehaald uit kinderboeken voor 8–12-jarigen (o.a. *Geronimo Stilton – Alice in Wonderland* en *Roald Dahl – De Heksen*).

## Resultaten

### Antropometrie

#### Touchpoint 1 — Ronde draaiknop

Voor de draaibare ring werd de **laterale knijpkracht** (lateral pinch strength) gebruikt als bepalende maat. Dit is de kracht waarmee een object tussen wijsvinger en duim wordt geklemd.

| Leeftijd | Jongens – L (lbs) | Jongens – R (lbs) | Meisjes – L (lbs) | Meisjes – R (lbs) |
| --- | --- | --- | --- | --- |
| 8.0–8.4 | 7.9 ± 1.9 | 7.9 ± 1.9 | 7.4 ± 1.4 | 7.4 ± 2.2 |
| 8.5–8.9 | 8.0 ± 1.8 | 8.6 ± 1.9 | 7.8 ± 2.2 | 7.8 ± 1.9 |
| 9.0–9.4 | 9.1 ± 1.4 | 9.5 ± 2.1 | 7.8 ± 1.7 | 8.1 ± 1.7 |
| 9.5–9.9 | 8.8 ± 1.6 | 9.9 ± 2.1 | 8.0 ± 1.6 | 8.8 ± 2.3 |
| 10.0–10.4 | 9.2 ± 1.8 | 9.8 ± 2.1 | 8.4 ± 2.1 | 8.6 ± 2.2 |
| 10.5–10.9 | 9.7 ± 2.2 | 10.3 ± 1.9 | 8.9 ± 2.3 | 9.4 ± 2.1 |
| 11.0–11.4 | 10.2 ± 2.7 | 10.4 ± 2.1 | 10.3 ± 2.1 | 10.6 ± 2.2 |
| 11.5–11.9 | 11.3 ± 2.0 | 12.3 ± 3.0 | 11.1 ± 2.3 | 10.8 ± 2.5 |

*Bron: Wen J, Wang J, Xu Q, et al. (2020). Hand anthropometry and its relation to grip/pinch strength in children aged 5 to 13 years. Journal of International Medical Research, 48(12).*

<p align="center">
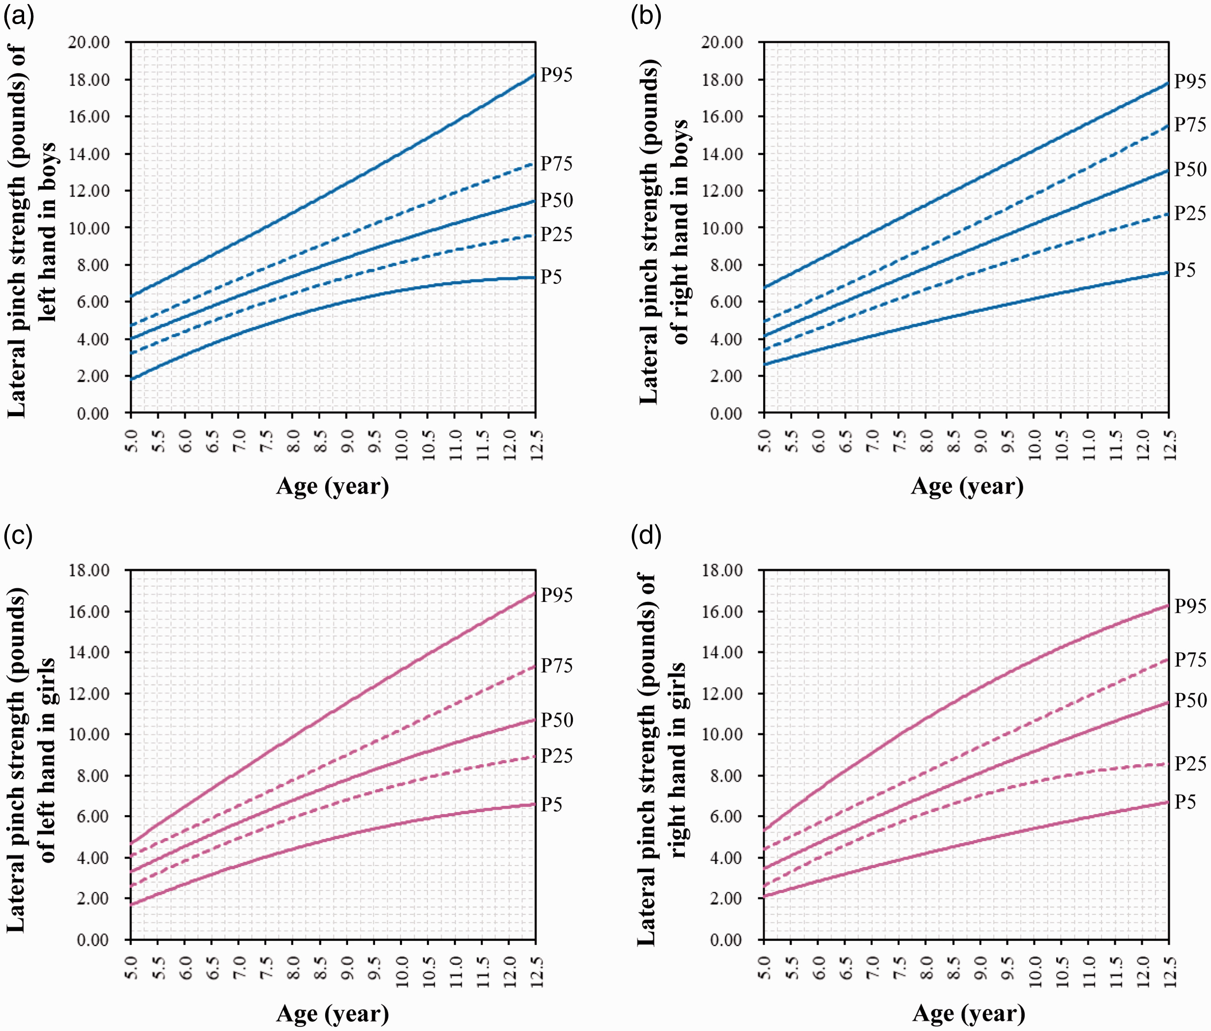
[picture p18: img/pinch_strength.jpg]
  
  <br>
  <em>Figuur 4.2: Lateral pinch strength.</em>
</p>

Aangezien **elk** kind binnen de doelgroep de ring vlot moet kunnen bedienen, wordt **design for the small** toegepast: het minst krachtige kind (meisje 8.0–8.4 jaar, linkerhand) bepaalt de maximumkracht.

**Berekening:** 7.4 – 1.4 lbs = 6.0 lbs ≈ **2.7 kg**

- **Ontwerpprincipe:** design for the small
- **Maximale knijpkracht:** 2,7 kg

#### Touchpoint 2 — Aanraakscherm

Voor het aanraakscherm werd de **wijsvingerbreedte** (index finger breadth, distal) gebruikt. Bij touch-interfaces wordt **design for the tall** toegepast: de touchpoints moeten groot genoeg zijn zodat ook kinderen met de breedste vingers comfortabel kunnen tikken.

| Leeftijd | Jongens (mm) | Meisjes (mm) |
| --- | --- | --- |
| 7–10 jaar (P95) | 16.3 | 15.7 |
| 11–12 jaar (P95) | 17.5 | 17.0 |

*Bron: Ran, L., Zhang, X., Chao, C., Liu, T., Dong, T. (2009). Anthropometric Measurement of the Hands of Chinese Children. ICDHM 2009.*

> ⚠️ **Beperking van de bron:** de dataset is gebaseerd op Chinese kinderen. Westerse kinderen kunnen iets bredere vingers hebben, dus voor de zekerheid wordt een ruimere marge aangehouden.

- **Ontwerpprincipe:** design for the tall
- **Minimale touchpoint-grootte:** 17,5 mm (+ marge)

#### Touchpoint 3 — Polsband

Voor de polsband werd de **polsdikte** (wrist thickness) opgemeten. Aangezien de band moet meegroeien met het kind én vlot aan en uit moet kunnen, wordt **design for adjustability** toegepast.

| Leeftijd | Jongens (cm) | Meisjes (cm) |
| --- | --- | --- |
| 8.0–8.4 | 3.25 ± 0.42 | 3.01 ± 0.31 |
| 8.5–8.9 | 3.33 ± 0.54 | 3.13 ± 0.35 |
| 9.0–9.4 | 3.34 ± 0.38 | 3.05 ± 0.32 |
| 9.5–9.9 | 3.24 ± 0.33 | 3.18 ± 0.42 |
| 10.0–10.4 | 3.30 ± 0.38 | 3.11 ± 0.39 |
| 10.5–10.9 | 3.36 ± 0.35 | 3.20 ± 0.31 |
| 11.0–11.4 | 3.54 ± 0.47 | 3.34 ± 0.31 |
| 11.5–11.9 | 3.58 ± 0.43 | 3.48 ± 0.41 |

*Bron: Wen J, Wang J, Xu Q, et al. (2020). Hand anthropometry and its relation to grip/pinch strength in children aged 5 to 13 years.*

<p align="center">
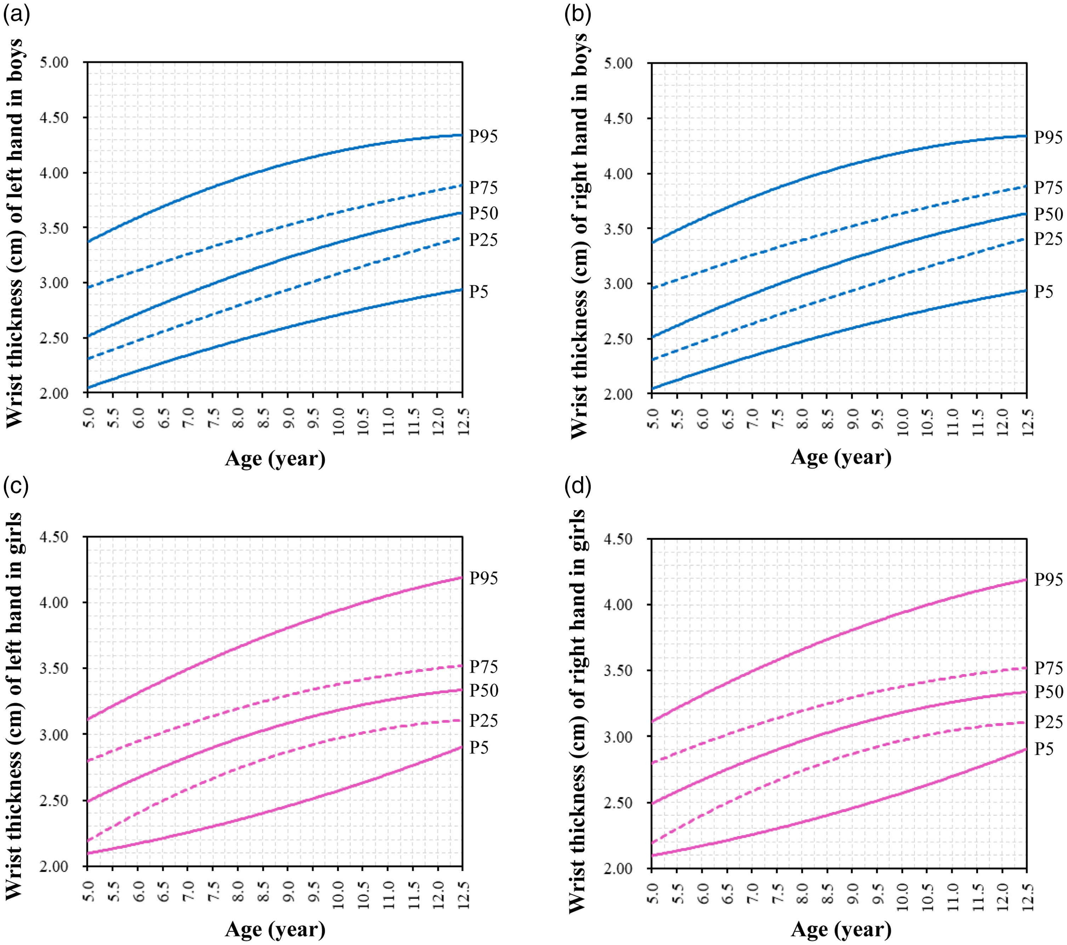
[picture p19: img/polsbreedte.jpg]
  
  <br>
  <em>Figuur 4.3: Polsdiktes.</em>
</p>

Met inbegrip van standaardafwijkingen loopt de polsdikte van ~2,70 cm (kleinste meisje) tot ~4,01 cm (grootste jongen). De band moet dus minstens dit volledige bereik dekken, met extra marge.

- **Ontwerpprincipe:** design for adjustability
- **Bereik:** minimaal 2,70 cm – maximaal 4,01 cm

### Range of motion

#### Deskresearch gewicht (N=6)

| Horloge | Kinderproduct | Gewicht |
| --- | --- | --- |
| Samsung Galaxy Watch 6 | Nee | 59 g |
| Apple Watch Series 9 | Nee | 31,9 g |
| Garmin Fenix 8 | Nee | 80 g |
| VTech Kidizoom | Ja | 50 g |
| Garmin Vivofit Jr. 3 Marvel | Ja | 25 g |
| Xplora X6 Play | Ja | 58 g |

<p align="center">
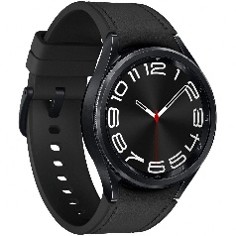
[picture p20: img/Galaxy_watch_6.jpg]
  
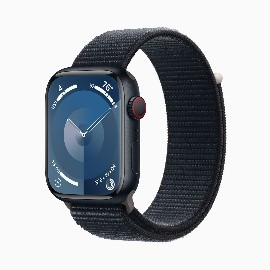
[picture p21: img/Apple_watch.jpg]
  
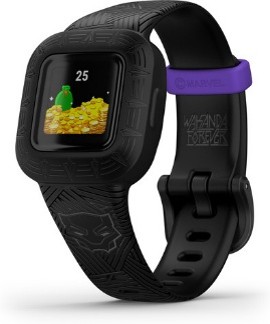
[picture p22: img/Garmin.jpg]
  
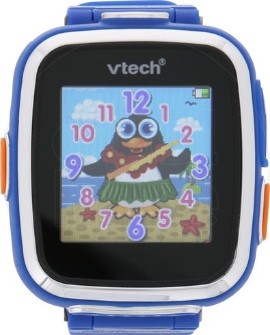
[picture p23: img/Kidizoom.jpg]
  
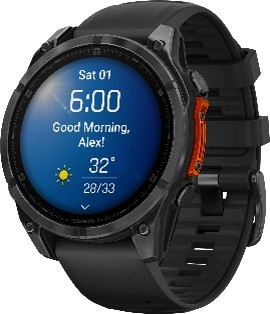
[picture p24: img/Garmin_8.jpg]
  
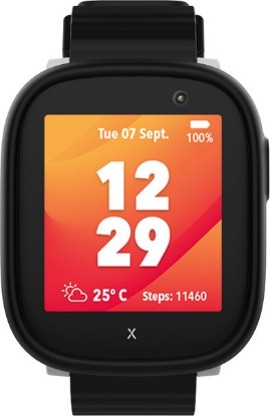
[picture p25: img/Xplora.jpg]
  
  <br>
  <em>Figuur 4.4: Horloges Deskresearch.</em>
</p>

Het gewicht van smartwatches varieert sterk: van 25 g tot 80 g. Specifiek voor kinderhorloges ligt het bereik tussen **25 g en 60 g**.

#### Usertest (N=5)

De test werd uitgevoerd in bibliotheek De Krook met kinderen tussen 9 en 10 jaar. Uit de praktijktest kwamen vier consistente patronen naar voren.

**1. Interactie en bediening**

De **draairing** (rotating bezel) van de Samsung Gear S3 kreeg een unanieme voorkeur boven een standaard touchscreen. Daarnaast werd er specifiek gevraagd naar fysieke knoppen, met voorkeur voor een grotere knop aan de linkerkant.

**2. Schermgrootte en vormfactor**

Een **slanke, Fitbit-achtige vormfactor** wordt door meerdere kinderen als aantrekkelijk en comfortabel ervaren. Grote prototypes worden snel als *"lomp en oncomfortabel"* ervaren rond een dunne kinderpols. Eén deelnemer week af en gaf de voorkeur aan een groter scherm; voor één andere maakte het niet uit.

**3. Polsbandjes**

De polsomtrek van de doelgroep vereist **zeer kleine bandjes**: alle respondenten moesten de Gear S3 dragen op de kleinste, op één na kleinste of op twee na kleinste stand. Het comfort van het bandje blijkt cruciaal voor de acceptatie van het totale gewicht.

**4. Gewicht — de paradox tussen theorie en praktijk**

Dit is de meest opvallende bevinding uit de test:

| Setting | Voorkeur | Reden |
| --- | --- | --- |
| Losse gewichtjes (theoretisch) | Lichtste gewicht | Bewegingsvrijheid, *"voelt alsof je niets aanhebt"* |
| Werkend horloge (praktijk) | Zwaarder (Gear S3, 59 g) | *"Beter"*, *"premium"*, *"steviger"* |

De extra respondent (Lars) bevestigde: *"een iets zwaarder horloge voelt meer premium en steviger aan."* Emma vormde de uitzondering, voor haar was de Gear S3 te zwaar voor continu gebruik.

> **Conclusie:** een klein scherm en een kleine band, maar met een relatief zwaarder gewicht (richting ~59 g) wordt als optimaal ervaren.

### Sensoriële ergonomie — zien

De referentielettergrootte voor leesbare tekst bij kinderen van 8–12 jaar werd afgeleid uit kinderboeken voor deze leeftijdscategorie. Geanalyseerde boeken: *Geronimo Stilton — Alice in Wonderland* en *Roald Dahl — De Heksen*.

<p align="center">
  
  
  
  
  <br>
  <em>Figuur 4.5: refererentieboeken</em>
</p>

- **Lettergrootte:** 14–16 pt voor 8–12 jaar
- *Bron: [boekenmakers.nl](https://www.boekenmakers.nl/artikel/hoe-kies-je-de-juiste-lettergrootte-voor-boeken/)*

## Kritische reflectie

Het originele opzet van deze Develop II was om een eerste prototype van het **volledige ZUÏN-systeem** te testen. Vijf gezinnen zouden gedurende twee dagen met een hub en wearable interageren, om zowel het herhaaldelijk gebruik als een eventuele eerste gedragsverandering te observeren.

Dit idee werd verworpen omwille van twee redenen:
- Er waren problemen met de conectiveit tussen de twee toestellen. Achteraf bleek dat er iets mis was met de microcontrollers. Dit werd zeer laat in het project ontdekt waardoor de tests zijn weggevallen.
- Er zou geen tijd meer zijn om genoeg data te verzamelen (vijf gezinnen twee dagen lang laten testen) om tot een reële conclusie te komen. Kinderen gaan in de week naar school en ouders werken, waardoor alleen in de weekenden of vakanties getest zou kunnen worden. Enerzijds om genoeg data te kunnen verkrijgen, anderzijds omdat het voor ouders ook doorgaans beter past in de weekenden. 

Een beperking van de huidige fase is dat de usertest met N=5 kwalitatief van aard blijft en dat de antropometrische bronnen deels gebaseerd zijn op een niet-Westerse populatie (Chinese kinderen voor de vingerbreedte). Voor het verdere ontwerp werd hier marge op toegelaten.

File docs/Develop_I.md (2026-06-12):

# Develop I

## Doelstellingen

In deze fase wordt de ontvangen tussentijdse feedback verwerkt en toegepast. Daarnaast wordt de kernfunctionaliteit en gebruikersinteracties aangescherpt. Hierdoor wordt er gehoopt de onderzoeksdoelstelling te verduidelijken, zodat er helderheid ontstaat omtrent wat er precies onderzocht moeten worden in verband met gedrags - of energiegerelateerde problemen.

## Materiaal & methoden

### Systeemanalyse

Om het project te verfijnen is er gestart met een functionele systeemanalyse. Hierbij wordt het product vanuit verschillende perspectieven bekeken. Hiervoor zijn 4 methodes toegepast. Deze methoden waren:

  * Customer journey: analyse van het volledig proces van de eerste confrontatie met het probleem tot    de interactie van het horloge met het kind.
  * HTA (Hierachial Task Analysis): het opsplitsen van het gebruik in taken en subtaken.
  * Productarchitectuur: Identificeren van verschillende componenten en datastromen en welke functie dit component heeft.
  * MVP (Minimum Viable Product): Bepaling van de minimale set functies die het toestel moet kunnen toepassen.
    
### Human-Product Interactions

De Human-Product Interactions werden gebruikt om inzichten te creëren omtrent de interacties tussen de gebruiker, het apparaat, het intern systeem van de horloge en de connectiviteit met uitwendige stroomtrackers. Hiervoor werd een funtioneel interactieschema opgesteld. Dit schema visualiseerd verschillende componenten, signalen en datastromen. De verschillende categorieën werden gegroepeerd:

  * Componenten
  * Feedback
  * User input
  * Data en verwerking

Deze interacties tonen de belangrijkste input-, verwerkings- en feedbackmechanismen. Wat later van belang is voor de productarchitectuur en interactielogica.

### Storyboard

Voor het visualiseren van een mogelijks gebruiksscenario is er een nieuwe storyboard gemaakt. Hierin worden de interacties tussen het product en de user gevisualiseerd. Dit is ondertussen al het tweede storyboard. Bij het eerste storyboard werd er nog in duister getast. Er was nog geen concreet concept of plan. In deze verdere fase is er al een concreet idee van het concept en dit is dan verwerkt in de storyboard.

### Deskresearch

Voor de ontwikkeling van het horloge werd een benchmarkanalyse uitgevoerd om de interacties zo gebruiksvriendelijk te maken. In een eerdere fase werd er ook een benchmarkanalyse uitgevoerd met als doel kennis te verwerven omtrent energiebesparende toestellen op de markt. In deze fase verschuift de focus naar slimme horloges, applicaties en digitale interfaces. Het doel is de meest intuïtieve en gebruiksvriendelijkeinteractie voor een slimme horloge voor kinderen te identificeren.

De analyse werd in 2 categoriên verdeeld:

 * Smartwatches voor volwassenen (N=4)
 * Smartwatches voor kinderen (N=3)
 * Habit apps (N=4)
   
Op basis van deze inzichten kan achteraf een kindvriendelijke horloge gemaakt worden.

### User testing 

Om inzichten te krijgen omtrent koopbereidheid, gewenste functionaliteit en gebruikersverwachtingen werden interviews uitgevoerd met de ouders van kinderen in de lagere school (N=5). Aangezien ouders de uiteindelijke beslissing nemen om het product aan te schaffen, werd er gekozen om hen centraal te zetten in deze fase en hen te interviewen.

<p align="center">
  
  <br>
  <em>Figuur 3.1: Concept poster: ondersteunend materiaal ouderinterviews (Develop I).</em>
</p>
Thema's die aan bod kwamen waren:

 * Koopbereidheid
 * Functionaliteiten
 * Ervaringen met habit-changing producten

De gewenste functionaliteiten werden bevraagd aan de hand van **Card Sorting**.
De interviews werden zowel online als fysiek uitgevoerd.

## Resultaten

### Systeemanalyse

#### Customer Journey

<p align="center">
  
  <br>
  <em>Figuur 3.2: Customer Journey: route van ouderlijke trigger tot kindgedragsverandering.</em>
</p> 
  
 * De analyse toont aan dat ouders de initiële trigger vormen. Dit is in de vorm van een hoge energiefactuur.
 * Na de trigger verschuift de interactie naar het kind. Het is aan hem/haar om bewuster te worden omtrent verbruik met behulp van het ZUIN horloge.
 * De feedback zorgt ervoor dat het kind verbruik leert te herkennen en zo zijn/haar gedrag aan te passen.
 * De eilandjes en het monstertje motiveren het kind om apparaten die niet in gebruik zijn uit te schakelen.

#### HTA

Bij de HTA is de hoofdtaak van het systeem: bijleren over energieverbruik om zo dan gedragsverandering te vertonen. Deze hoofdtaak wordt later opgesplitst in subtaken die dan wederom worden opgsplitst.

<p align="center">
  
  <br>
  <em>Figuur 3.3: Hierarchical Task Analysis (HTA): opsplitsing in taken en subtaken.</em>
</p>

* Informatie over energieverbruik ophalen
  * Dat wordt verkregen via digitale stroommeters
    * Deze data wordt doorgestuurd naar het horloge
  
* Horloge activeren
  * De gebruiker zet het horloge aan doormidden van een aan-uitknop
   
* Gewenste kamer bereiken
  *  Er kan tussen de eilandjes (kamers) genavigeerd worden doormiddel van swipen
   
* Verbruik waarnemen
  *  Het kind interpreteert de informatie die wordt weergegeven op het display
  
* Gedrag aanpassen
  * Concrete actie wordt ondernomen
    * Lichten of apparaten die niet in gebruik zijn worden uitgeschakeld

#### Productarchitectuur

De productarchitectuur beschrijft welke functies bij welke componenten horen. Het toont ook hoe de energiegegevens uiteindelijk worden vertaald naar informatie voor de kinderen.

<p align="center">
  
  <br>
  <em>Figuur 3.4: Productarchitectuur: componenten, datastromen en feedbacksysteem smartwatch.</em>
</p> 
De volgende systemen worden geïdentificeerd:

 * Behuizing
 * Input
 * proccesing
 * feedbacksysteem
 * connectiviteit
 * energievoorziening
 * scherm

#### MVP

<table>
<tr>
<td width="60%">

De MVP-analyse identificeert de Minimum Viable product. Zo identificeert het de noodzakelijke functies voor het ZUIN project waar het zeker aan moet voldoen. Uit de analyse kwamen 4 MVP's naar boven:

- **Draagbaar product**  
  - Het systeem moet in de vorm van een horloge zodat kinderen het altijd bij zich hebben.

- **Bewustwording van verbruik**  
  - Het toestel moet informatie omtrent energieverbruik begrijpelijk maken voor kinderen.

- **Stimuleren tot actie**  
  - Het systeem moet kinderen aanzetten tot verandering in hun gedrag.

- **Interface met duidelijke interpretatie**  
  - Het moet zeer duidelijk in 1 oogopslag tonen wat er verbruikt wordt.

</td>

<td width="40%">


<br>
<small><em>Figuur 3.5: Minimum Viable Product (MVP): minimale set functies voor de ZUIN-wearable.</em></small>

</td>
</tr>
</table>

 ### Human-Product Interactions
 
De HPI-analyse toont hoe de gebruikersinput, de gegevens en de feedback samenhangen en een geheel vormen. De interacties werden opgesplitst per systeemonderdeel.

<p align="center">
  
  <br>
  <em>Figuur 3.6: Human-Product Interactions (HPI): samenhang input, verwerking en feedback.</em>
</p>

* Aan/Uit
  * Push input via knoppen
  * Presence sensor. De horloge krijgt de functie van het energie besparen enkel te huis. (constraints)

* Metingen verbruik
  * Stroomtrackers bij elk apparaaat
  * Data wordt via connectiviteit met horloge verzonden
  * Gegevens worden verwerkt en opgeslagen in database
  * Arduino verwerkt data
  * Energieverbruik wordt weergegeven als eilandjes (metafoor voor verschillende kamers)

 * Scherm en interface
   * Touchscreen voor eenvoudig navigeren
   * Swipen om te navigeren tussen verschillende kamers
   * Display toont aan de hand van LED-ring of er veel of weinig verbruikt wordt
     
 * Feedback
   * Visuele feedback: display, LED-ring, monstertje
   * Speelse feedback: eilandjes, monstertje, verhaaltje
   * Haptische feedback: vibrerende motor
     
 * Antropometrie
   * Horlogeband
     * Moet rond de pols gedragen worden
       * Moet een kinderpols passen
   * Horloge-omhulsel
     * beschermen van elektronica
 
### Storyboard

Het storyboard visualiseert het gebruiksscenario van het ZUIN horloge. Het toont het gebruik ervan in het dagelijks leven. De eerste versie van het storyboard was een snelle schets tijdens de eerste gezamelijke les dat een aan algemeen beeld toont van het idee van het project. Ondertussen is het project al verfijnd en staat de ZUIN-horloge centraal. Dit storyboard toont dan ook een concreter verhaal met het horloge in geïntegreerd.

<p align="center">
  
  <br>
  <em>Figuur 3.7: Storyboard 2: alledaags gebruiksscenario met geïntegreerd ZUIN-horloge.</em>
</p>
Belangrijke stappen in het scenario:

 * Probleemdetectie
   * Ouders worden geconfronteerd met hoge energierekeningen
 * Introductie van het product
   * Het ZUIN-horloge wordt aan de kinderen gepresenteerd en overhandigt
 * Interactief leren
   * Het horloge vertelt de kinderen wanneer er veel verbruikt wordt en wat er aan gedaan moet worden
 * Gedragsverandering
   * Kind schakelt niet gebruikte lichten en apparatuur uit
 * Resultaten
   * Na verloop van tijd ontvangen ouders lagere energiefacturen
   
### Deskresearch

#### Smartwatches voor volwassenen (N=4)

Uit de analyse blijkt dat er verschillende interactieparadigma’s gebruikt worden om om te gaan met het kleine scherm van een horloge. De gekozen interactie hangt samen met de primaire gebruikssituatie van het apparaat.

<p align="center">
  
  <br>
  <em>Figuur 3.8: Benchmark: interactie- en interface-analyse van volwassen smartwatches.</em>
</p>
 Belangrijke inzichten:
 
 * Fysieke interacties blijven belangrijk
   * Touchscreens en zijn klein en worden snel bedekt met vingerafdrukken
   * Fysieke knoppen en draairingen verbeteren interactie
    
 * Samsung Galaxy Watch 6
   * De draairing wordt sterk gewaardeerd
     
 * Apple Watch series 9
   * Vloeiende animaties
   * Responsive interface
   * Veel functies = complex
     
 * Garmin Fenix 8
   * Goed voor sporters
   * Voor gewone gebruikers complex
     
 * Casio G-Shock
   * Robuust
   * Beperkte interactie
   * Eenvoudig

#### Smartwatches voor kinderen (N=3)

Kinderhorloges houden meer rekening met motorische en cognitieve beperkingen van kinderen. Om die reden zijn interfaces vaak eenvoudiger en visueel duidelijker.

<p align="center">
  
  <br>
  <em>Figuur 3.9: Benchmark: kindersmartwatches, cognitieve drempels en gamification.</em>
</p>
Belangrijkste inzichten:

 * Robuuste ontwerpen en grotere knoppen voor eenvoudigere interacties
 * Ondiepe informatiehiërachie
 * Complexiteit schuilt niet in horloge zelf maar vaak in een ouder-app

Per product:

 * Garmin Vivofit Jr. 3
   * gamification met beloningen
   * lange baterijduur
   * klein en donker scherm
 * Xplora X6 Play
   * GPS en communicatie
     * Bieden geruststelling aan ouders
   * Batterijduur is beperkt
 * Vtech Kidizoom smartwatch DX2
   * Speelt in op entertainment
   * Visuele stimulatie
   * Populair bij kinderen

#### Habit Apps (N=4)

De analyse werd uitgevoerd om te begrijpen welke mechanimen leiden tot gedragsverandering.

| App | Aanpassing doelgroep | Interactiemogelijkheden | Gebruikerservaring | Visuele stijl | Informatie hiërarchie |
|---|---|---|---|---|---|
| **Habitica** | Voor gebruikers met motivatieproblemen; taken worden RPG-quests | Taken afvinken, items kopen, sociale interactie | Motiverend door gamification maar soms te streng | Retro pixel-art, felle kleuren | Lijsten met tabs en diepere menu's |
| **Streaks** | Minimalistische aanpak met max. 24 gewoontes | Long-press interactie met haptische feedback | Zeer gebruiksvriendelijk maar streng bij gemiste dagen | Minimalistisch met iconen | Platte gridstructuur |
| **Fabulous** | Coaching-app gebaseerd op gedragswetenschap | Swipen door journeys, audiocoaching, routines | Inspirerend maar soms te rigide | Illustraties en vloeiende animaties | Lineaire tijdlijnstructuur |
| **Habitify** | Gericht op datagedreven gebruikers | Swipen, tikken en interactie met grafieken | Betrouwbaar maar minder speels | Zakelijke dashboardstijl | Navigatiebalk met dashboardstructuur |

Belangrijkste inzichten:

 * Gamification verhoogt motivatie
 * Visuele feedback en progressie zijn cruciaal voor gedragsverandering
 * Eenvoudige interacties zoals tikken of swipen
   * Betere gebruiksgemak
 * Apps verschillen sterk: informatiehiërachie = plat => diep

### User testing (N=5)

Om de functies en koopbereidheid van het ZUIN-concept te evalueren werden semi-gestructureerde interviews met ouders (N = 5) uitgevoerd. De respondenten hadden kinderen in de lagere schoolleeftijd. Tijdens de interviews werd de houding tegenover energieverbruik, koopbereidheid en perceptie van functies onderzocht. Daarnaast werd een card sorting oefening uitgevoerd waarbij ouders verschillende functies moesten categoriseren. De resultaten hiervan zijn weergegeven in de bovenstaande figuren.

#### Houding tegenover energieverbruik

Uit de interviews blijkt dat energieverbruik weinig actief wordt opgevolgd, hoewel ouders het wel belangrijk vinden.

 * Energiebesparing gebeurt via basisgewoontes
 * Facturen en energieapps worden zelden geanalyseerd
 * Kinderen worden beperkt betrokken bij besparen
   * Ouders vinden dat kinderen hier wel bewuster om moeten worden

#### Koopbereidheid

De koopbereidheid voor het product hangt sterk af van context.

 * Belangrijke factoren: prijs, leeftijd van kind (8-12 jaar) en meerwaarde
 * De meningen om het product via een energieleverancier of ander abonnement te verkrijgen zijn verschillend
   * ouders zouden het product eerder zelfstandig kopen om zelf informatie te kunnen opzoeken
   * anderen geven aan dat een bundel via een energieleverancier de instapdrempel kan verlagen

#### Card sorting

Tijdens de interviews werden mogelijke functies gecategoriseerd via card sorting.

<p align="center">
  
  <br>
  <em>Figuur 3.10: Card sorting deel 1: fysieke interviews.</em>
</p>

<p align="center">
  
  <br>
  <em>Figuur 3.11: Card sorting deel 2: online interview 1.</em>
</p>

<p align="center">
  
  <br>
  <em>Figuur 3.12: Card sorting deel 3: online interview 2.</em>
</p>

##### Sterk gewaardeerde functies

 * Virtueel huisdier (speelse motivatie)
 * Challenges
 * Gezinscompetitie
 * Zichtbare progressie of resultaten
 * Beloningen of badges
 * Rapporten of overzichten van gedrag
 * Educatieve elementen zoals quizzen of verhaaltjes
 * Praktische functies zoals een douche-timer

##### Minder gewenste functies

 * Constant trillen of notificaties
 * Overmatige visuele of auditieve prikkels
 * Te complexe of flashy features
 * Te veel fysieke signalen

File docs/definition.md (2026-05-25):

## Definition

### Doelstellingen
In deze fase is het belangrijk om het juiste te ontwerpen (‘designing the right thing’). Het product moet kinderen motiveren om het te gebruiken en zo bewuster te worden over verbruik en duurzaamheid. 

  * Met welk speelgoed spelen kinderen graag?
  * Wat motiveert kinderen?

### Materiaal en methoden

De definition-fase werd gestart met een sprintday, waarop dieper werd ingegaan op de feedback van de discovery-fase. Er werd een storyboard opgesteld, om een duidelijker zicht te krijgen op het doel van het product. Het product maakt kinderen op een speelse manier bewust over het alledaagse verbruik in huis, en motiveert ze om een steentje bij te dragen aan het verminderen ervan. 

<p align="center">
  
  <br>
  <em>Figuur 2.1: Storyboard: beoogde gebruiksscenario ZUIN in het huishouden.</em>
</p>
Vervolgens werd dit idee fysiek uitgewerkt door drie quick and dirty prototypes. In wave 1 werden deze prototypes gevalideerd door een user feedback session.  
  * **Beer** : Deze knuffelbeer heeft een scherm geïntegreerd in de buik, waar de interface op kan verschijnen.
  * **Horloge** : Deze slimme horloge werkt buitenshuis als een normale horloge waar enkel de tijd op gezien kan worden. Vanaf de horloge thuis komt, zal er een ledje branden om aan te geven of er veel wordt verbruikt. Op                     het scherm zelf zal een interface komen.
  * **Tamagotchi** : Dit apparaatje is een compacte console waarop de interface te zien is.

<p align="center">
  
  
  <br>
  <em>Figuur 2.2: Prototypes Wave 1: Beer (knuffel met buikscherm) en console-concept.</em>
</p>
<p align="center">
  
  
  <br>
  <em>Figuur 2.3: Prototypes Wave 1: Standalone console en ouderdisplay.</em>
</p>
Om wave 1 vlot te kunnen starten, werd er gebeld met een expert vanuit Comon. Hier werd afgetoetst wat de goede leeftijdscategorie is voor onze doelgroep. Hij vertelde dat kinderen vanaf 5 jaar al gehoord hebben van het begrip energieverbruik. De doelgroep werd dus gedefineerd op kinderen van de lagere school (5 - 12 jaar). 
Verder vertelde hij dat gemification slechts werkt voor 2-4 weken. Hij raadde aan om een betekenisvolle interactie (zoals feedback) te creëren. 
Kinderen houden van dingen die veranderen, verrassen en verhalend zijn. 

> #### Wave 1 : user feedback sessions (N=5)
> In de eerste wave van de definition-fase werd onderzocht welk speelgoed kinderen aanspreekt. Op dag van de wetenschap werd een standje opgezet met de drie prototypes. Gezinnen konden hier vrijwillig deelnemen aan een kort interview. Er werden zowel jongens als meisjes geïnterviewd uit de lagere school.
> 
> <p align="center">
>   
>   <br>
>   <em>Figuur 2.4: User feedback Wave 1: Interviewstand Dag van de Wetenschap.</em>
> </p>

Vervolgens werd de interface van het product bepaald. Dit werd op verschillende manieren in Figma uitgewerkt. 

> #### Wave 2 : usability testing met wizard-of-oz-benadering (N=5)
> De 2e wave staat centraal rond intuïtief gebruik. Op 6/12/2025 werden enkele testen afgenomen met kinderen in de Krook in Gent. De testpersonen kregen de verschillende interfaces voor zich, en werden gevraagd om telkens 3 taken uit te voeren:
>  * Identificeer een kamer met “brand” (hoog energieverbruik) en 'blus' deze door fysiek een lamp uit te schakelen
>  * Ga opzoek naar het fantasie-eiland
>  * Zoek een verhaaltje in de interface
> Elke taak werd per interface opnieuw uitgevoerd om het effect van herhaling op begrip en navigatie te meten. 
>
> <p align="center">
>   
>   <br>
>   <em>Figuur 2.5: Usability testing Wave 2: Wizard-of-Oz-testen in De Krook.</em>
> </p>

### Resultaten 

#### Wave 1 : user feedback sessions (N=5)
Uit de interviews blijkt dat zowel kinderen als ouders duidelijk waarde zien in een speels en visueel systeem dat kinderen stimuleert om bewuster met energie om te gaan. Het prototype van het horloge komt hierbij het sterkst naar voren als favoriet. Kinderen verkiezen dit omdat het draagbaar is, altijd bij hen blijft en directe feedback geeft via kleuren, eilandjes en LED-effecten. Voor kinderen die meer spelgericht zijn, blijft een speelconsole/Tamagotchi-achtige oplossing aantrekkelijk, vooral door het spel- en verzorgelement. De beer is daarentegen het minst populair en wordt slechts overwogen wanneer het concept minder dierlijk en meer technisch (robotachtig) wordt vormgegeven.

De belangrijkste functie die kinderen motiveert, is visuele en speelse feedback: kleurveranderingen, brandende of gelukkige eilandjes, LED-lichtjes en kleine beloningen. De gamification zorgt ervoor dat kinderen actief willen helpen en zelfs hun ouders aanspreken op energiegebruik. Extra fun-elementen zoals personalisatie, spelletjes en geluid versterken deze motivatie.

Ouders staan positiever tegenover het educatieve doel van het concept dan tegenover het fysieke product zelf. Koopbereidheid is beperkt, vooral door bezorgdheden rond afval, prijs en onnodige hardware. Velen zien meer in een app- of hybride oplossing, waarbij hardware minimaal blijft. Ze vinden het essentieel dat het systeem eenvoudig, duurzaam en niet overladen met smart functies is. Feedback zoals kleur, trilling of subtiel geluid is gewenst, maar zonder overmatige notificaties of straling.

#### Wave 2 : usability testing met wizard-of-oz-benadering (N=5)
Uit de testen konden enkele algemene observaties gehaald worden. Zo heeft herhaling een sterke positieve invloed op begrip en zelfstandigheid. Bijvoorbeeld het brand-icoontje dat steeds terug kwam motiveerde de kinderen zelfstand de lichten te doven, maar vereiste eerst een duidelijke uitleg. Het verhaaltje vinden was bij de drie interfaces vaak moeilijk, hier is dus een structureel probleem in de informatie-architectuur. Verder is de tekstgrootte te klein voor kinderen om te lezen. Hierdoor is het moeilijker bepaalde info te vinden en het vehaaltje te lezen. Dit merkten ook de ouders op. 

Specifiek per interface was bij UI1 de eerste interactie verwarrend door de onduidelijkheid van het brand-icoontje. Ook de swipe-interactie werd pas spontaan toegepast bij tweede poging. De kinderen gaven aan dat ze graag een personalisatie-optie willen. 
De navigatie bij UI2 ging opmerkelijk vlotter door de bekendheid met het concept. Echter kwam de drop-down menu onduidelijk over waardoor de taak van het verhaaltje zoeken hulp nodig had bij het voltooien. 
UI3 was de interface waar het meeste enthousiasme over was. Toch was de menu eerder verwarrend en is de test vroegtijdig stop gezet door een bug waardoor de knop om het verhaaltje te openen het scherm blokkeerde. 

### Conclusies & implicaties
Een draagbaar, visueel en spel-georiënteerd ontwerp maakt het meest kans om kinderen te engageren, terwijl ouders vooral eenvoud, duurzaamheid en educatieve waarde verwachten. Een horloge met spelelementen, eventueel gekoppeld aan een app, lijkt de meest beloftevolle richting om beide groepen te overtuigen.
Herhaling is essentieel om gebruikers het energieconcept en de navigatie correct te laten begrijpen. Dit impliceert dat het nieuwe product moet inzetten op een duidelijkere informatie-architectuur, waarbij verhaaltjes en kernfunctionaliteiten sneller en intuïtiever vindbaar zijn. Daarnaast zijn visuele verbeteringen, zoals grotere tekst en heldere iconen, noodzakelijk om de toegankelijkheid te verhogen. Motiverende elementen zoals de brand-metafoor blijken effectief, maar vereisen een duidelijke introductie via onboarding.

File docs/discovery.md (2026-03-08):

## Discovery

### Doelstelling
Het doel van de discoveryfase is inzicht krijgen in hoe mensen binnen het huishouden omgaan met energieverbruik en welke impact dit heeft op hun dagelijks leven. Er wordt onderzocht in welke mate bewoners hun energieverbruik begrijpen, of zij deze kennis toepassen in hun gedrag en of dit daadwerkelijk leidt tot energiebesparing.

Daarnaast wordt extra aandacht besteed aan de rol van kinderen, aangezien zij vaak onbewuste energieverbruikers zijn. Het onderzoek bekijkt hoe hun gedrag bijdraagt aan het totale energieverbruik en op welke manier zij op een eenvoudige en positieve manier betrokken kunnen worden bij het besparen van energie.

Concreet wordt onderzocht:

  * Hoe wordt energieverbruik ervaren en begrepen?
  * Waar ontstaan frustraties en onduidelijkheden omtrent dit thema?
  * Leidt energie-inzicht tot gedragsverandering?
  * Welke vorm van feedback motiveert mensen om te besparen?
  * Hoe kunnen kinderen op een speelse manier betrokken raken?

Het project focust niet op het rechtstreeks reduceren van energieverbruik, maar op bewustmaking, met als doel langdurige gedragsverandering en uiteindelijke energiebesparing.

### Materiaal en methoden

#### Benchmarking (N=10)

Benchmarking werd toegepast om bestaande oplossingen rond energiebewustzijn te analyseren en te vergelijken. Hierbij werd onderzocht welke producten vandaag ingezet worden om energieverbruik inzichtelijk te maken en welke sterktes en zwaktes deze systemen vertonen.

#### Interviews (N=3)

Aan de hand van interviews werd nagegaan hoe bewust mensen omgaan met hun energieverbruik, welke impact dit op hen heeft en welke personen binnen het huishouden het meeste verbruiken. Daarnaast werd onderzocht welke triggers mensen motiveren om energie te besparen.

#### Desk research (N=6)

Via deskresearch werd onderzocht welke toestellen het meeste energie verbruiken en welke verbruikers vaak vergeten worden, wat leidt tot onbewust en inefficiënt energiegebruik.

### Resultaten

#### Benchmarking (N=10)

Uit de benchmarkanalyse blijkt dat bestaande oplossingen zich vooral richten op het meten en visualiseren van energieverbruik, vaak via complexe interfaces en applicaties. Hierdoor zijn deze systemen weinig toegankelijk voor een jong of niet-technisch publiek, terwijl ook zij een belangrijke rol spelen in het huishoudelijk energieverbruik.

De meeste producten focussen op data en grafieken, maar slagen er onvoldoende in om energieverbruik begrijpbaar en motiverend te maken. Vooral eenvoud, gebruiksgemak en betrokkenheid van kinderen ontbreken in het huidige aanbod. 

Volgende tabel toont een selectie van de meest interessante benchmarks:

| Nr. | Naam / Merk | Functie | Technologie | Doel | Prijs | Sterktes | Zwaktes |
|----|---|---|---|---|---|---|---|
| 1 | Niko startskit met Home Control | Informatie over elektriciteits- en gasverbruik | Solar modus, real-time info via app | Overzicht geven en helpen verbruik te verminderen | €390 | Automatische opwekking van stekkers bij zonne-energie | Info enkel via app |
| 2 | Pitt & Co Energiemeter | Meet verbruik en berekent kosten | Vermogen- en spanningsmeter | Energiekosten doen dalen | €26,95 | Kostenberekening | Werkt maar voor 1 stopcontact |
| 3 | Gologi slimme stekker | Apparaten slim maken | App, voice control, countdown | Apparaten op afstand bedienen | €15 | Stembediening, energiemonitoring | Slechts 1 toestel tegelijk |
| 4 | Smart Plug | Stekker add-on met schakelaar | App, voice control | Apparaten op afstand bedienen | €22 | Geen extra benodigdheden | Slechts 1 toestel tegelijk |
| 5 | Homewizard Energy Display | Visualisatie van verbruik | Inzicht stroom, teruglevering, gas | Bewustmaken van verbruik | €60 | Plaatsbaar scherm, customize | Veel grafieken → verwarrend |
| 6 | Homewizard P1 | Visualisatie van verbruik | P1-plug, real-time app | Bewustmaken van verbruik | €25 | Gebruiksvriendelijk, goedkoop | Veel grafieken → verwarrend |

#### Interviews (N=3)

Uit de interviews blijkt dat de meeste respondenten moeite hebben om een correct en concreet beeld te vormen van hun elektriciteitsverbruik. Hoewel ze willen besparen, gebeurt dit meestal reactief, op basis van gevoel of na een hoge eindfactuur, en niet structureel.

Respondenten die gebruikmaken van slimme meters ervaren meer controle, maar geven aan dat de feedback vaak te technisch is en op dagelijkse basis weinig houvast biedt. Daarnaast werd duidelijk dat energieverbruik binnen een huishouden door meerdere personen wordt beïnvloed. In gezinnen spelen kinderen hierbij een grote rol, terwijl zij zich vaak niet bewust zijn van de gevolgen van hun gedrag. Dit zorgt bij ouders voor frustratie, omdat hun inspanningen niet altijd effect hebben.

Terugkerende uitspraken zijn onder andere:

  * “Je krijgt een bedrag, maar weet niet waar het vandaan komt.”
  * “Ik besef pas wat ik betaal als de factuur er is.”
  * “Apps tonen veel grafieken, maar ik weet niet wat ik ermee moet doen.”

Financiële motivatie blijkt de sterkste drijfveer voor energiebesparing; ecologische overwegingen spelen meestal een secundaire rol. De meeste respondenten staan open voor een hulpmiddel, op voorwaarde dat het betaalbaar, niet-invasief, eenvoudig en begrijpbaar voor kinderen is.

#### Desk research (N=6)

Uit de deskresearch blijkt dat het grootste deel van het huishoudelijk energieverbruik veroorzaakt wordt door ruimteverwarming, warmwaterproductie en grote huishoudtoestellen. Hoewel deze verbruikers bekend zijn, wordt hun impact vaak onderschat omdat het verbruik verspreid is over meerdere toestellen en momenten.

Daarnaast vormt sluipverbruik een belangrijk maar vaak vergeten probleem. Apparaten zoals routers, laders, televisies en computers blijven continu energie verbruiken, zelfs wanneer ze niet actief gebruikt worden. Individueel lijkt dit verbruik beperkt, maar gezamenlijk vormt het een aanzienlijk aandeel van het totale energieverbruik.

Ook minder evidente systemen zoals ventilatie, circulatiepompen, aquariums en verwarmde ongebruikte ruimtes worden vaak over het hoofd gezien. Zonder metingen blijven deze verbruikers onzichtbaar.

Terugkerende patronen uit de deskresearch zijn:

  * Energieverbruik is grotendeels onzichtbaar.
  * Sluipverbruik wordt sterk onderschat.
  * Gebruikers zien geen duidelijke link tussen gedrag en impact.
  * Gedeelde verantwoordelijkheid leidt tot inefficiënt gebruik.

### Conclusies

#### Benchmarks (N=10)

Bestaande producten focussen voornamelijk op dataverzameling en grafische weergave, maar onvoldoende op eenvoud en motivatie. Veel systemen vereisen een app, zijn complex of richten zich slechts op één toestel. Geavanceerde systemen zijn vaak duur en moeilijk te installeren. Dit toont aan dat er ruimte is voor een visueel eenvoudige en toegankelijke oplossing, geschikt voor alle bewoners, inclusief kinderen.

#### Interviews (N=3)

Uit de interviews blijkt dat bewoners willen besparen, maar dat een gebrek aan inzicht, feedback en gedeelde verantwoordelijkheid dit belemmert. De energiefactuur wordt ervaren als een “black box” en leidt vooral tot tijdelijke, reactieve gedragsveranderingen. Er is nood aan realtime, begrijpbare feedback die ook kinderen aanspreekt, en aan een betaalbare, niet-invasieve oplossing.

#### Desk research (N=6)

De literatuur bevestigt dat energieverbruik vooral wordt gedreven door verwarming, warm water en grote toestellen, aangevuld met een aanzienlijk aandeel sluipverbruik. Zonder duidelijke en visuele feedback blijft energieverbruik abstract. Vooral in gezins- en cohousingcontexten is er nood aan eenvoudige, centrale en laagdrempelige hulpmiddelen die duurzame gedragsverandering ondersteunen.

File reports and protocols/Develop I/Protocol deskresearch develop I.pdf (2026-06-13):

# Protocol deskresearch develop I

# Project informatie

Projectnaam: Zuin
Zuin is een slim product voor kinderen dat hen bewust maakt van verbruik in huis en hen stimuleert om de interactie aan te gaan met hun ouders om energiezuiniger te leven.

Interviewer:
- Sam Verkimpe (Sam.Verkimpe@UGent.be), Student Industrieel Ingenieur Industrieel Ontwerpen
- Maxim Depever (Maxim.Depever@UGent.be), Student Industrieel Ingenieur Industrieel Ontwerpen
- Jitse Van Laer (Jitse.VanLaer@Ugent.be), Student Industrieel Ingenieur Industrieel Ontwerpen

# Doelstelling en kadering

De desk research van deze develop I periode focust op het vergelijken van horloges die zich op de markt bevinden en hoe de interacties tussen deze apparaten en de gebruikers verlopen (benchmarking). Ook wordt er gezocht naar horloges die speciaal voor kinderen gemaakt worden en hoe de interacties tussen deze apparaten en de kinderen als hoofdgebruikers verlopen. Als laatste wordt er ook onderzoek gedaan naar habit apps, hoe ze werken, performantie en belangrijke kenmerken die gebruikt worden om gewoontes aan te leren bij mensen.

# Benchmarking horloges voor volwassenen

## Onderzoekscriteria

- Welke interactiemogelijkheden zijn er tussen gebruiker en apparaat?
- Hoe worden de interacties met deze producten ervaren door de gebruikers (reviews)?
- Hoe zit de informatie hiërarchie van deze horloges in elkaar?

# Benchmarking horloges voor kinderen

## Onderzoekscriteria

- Hoe wordt het horloge in het algemeen aangepast zodat het door kinderen gebruikt kan worden?
- Welke interactiemogelijkheden zijn er tussen kind en apparaat?
- Hoe worden deze apparaten in het algemeen ervaren door kinderen (reviews van ouders)?
- Visuele veranderingen voor kinderen?
- Hoe zit de informatie hiërarchie van deze kinderhorloges in elkaar.?

# Research habit apps

## Onderzoeksvragen

- Hoe performant zijn deze apps, zorgen ze er voor dat er weldegelijk verandering van gewoonte gebeurt?
- Welke elementen zorgen ervoor dat deze apps werken of waarom ook niet?
- Welke interacties gebeuren er tussen deze apps en de gebruiker?
- Welk speelgoed voor kinderen bestaat er dat gewoontes teweeg brengt?

# Plan van aanpak

Bij aanvang van alle drie de researches wordt er aan Gemini AI gevraagd om apparaten en apps te geven, hier is het de bedoeling dat de tijd gespendeerd voor zelf te zoeken naar apparaten en apps zo veel mogelijk wordt beperkt. Het gebruik van AI wordt niet gebruikt om zelf informatie te verzamelen, dit wordt nog steeds manueel gedaan. Door het gebruik van AI kan er op een snelle manier gezocht worden naar een aantal apparaten en apps die op zo veel mogelijk vlakken verschillen, zo kan er op een snelle manier een wijde variatie van producten gevonden worden. Prompts per onderzoek
- Benchmarking horloges voor volwassenen:
Voor een onderzoek ben ik op zoek naar een aantal volwassen digitale horloges. IK wil een benchmarking studie doen waar dat ik ga zoeken naar de volgende eigenschappen:
a) Welke interactiemogelijkheden zijn er tussen gebruiker en apparaat?
b) Hoe worden de interacties met deze producten ervaren door de gebruikers (reviews)?
c) Hoe zit de informatie hiërarchie van deze horloges in elkaar?
Zoek mij een aantal horloges waar dat deze functies zo veel mogelijk van elkaar verschillen.
- Benchmarking horloges voor kinderen:
Voor een onderzoek ben ik zoek naar een aantal kinderhorloges. Ik wil een benchmarkingstudie doen waar dat ik ga zoeken naar de volgende eigenschappen:
a) Hoe wordt het horloge in het algemeen aangepast zodat het door kinderen gebruikt kan worden?
b) Welke interactiemogelijkheden zijn er tussen kind en apparaat?
c) Hoe worden deze apparaten in het algemeen ervaren door kinderen (reviews van ouders)?
d) Visuele veranderingen voor kinderen?
e) Hoe zit de informatie hiërarchie van deze kinderhorloges in elkaar.?
Zoek mij een aantal horloges waar dat deze functies zo veel mogelijk van elkaar verschillen.
- Research habit apps
Ik ben voor een onderzoek op zoek naar een aantal habit apps om hier wat informatie over te verzamelen. Kan je mij de bekendste habit apps bezorgen? Dan kan ik ze vergelijken.

# Rapport

Rapport deskresearch develop I.docx (https://ugentbe-my.sharepoint.com/:w:/r/personal/sam_verkimpe_ugent_be/Documents/Academiejaar%202025-26/Project%20gebruiksgericht%20ontwerpen/Jaarproject/Seme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)

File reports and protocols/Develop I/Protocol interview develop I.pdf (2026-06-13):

# Interview protocol – develop 1

## Project informatie

Projectnaam: Zuin
Zuin is een slim product voor kinderen dat hen bewust maakt van verbruik in huis en hen stimuleert om de interactie aan te gaan met hun ouders om energiezuiniger te leven.

Interviewer:
- Sam Verkimpe (Sam.Verkimpe@UGent.be), Student Industrieel Ingenieur Industrieel Ontwerpen
- Maxim Depever (Maxim.Depever@UGent.be), Student Industrieel Ingenieur Industrieel Ontwerpen
- Jitse Van Laer (Jitse.VanLaer@Ugent.be), Student Industrieel Ingenieur Industrieel Ontwerpen

## Doelstelling en kadering

In het 1ste deel van de develop-fase wordt ingezet om van concept naar een onderbouwde functionele architectuur te gaan. Er wordt dieper gezocht naar de koopbereidheid van het product. Verder wordt er ook ingegaan op de gewenste functionaliteiten waarvan enerzijds de ouders denken dat hun kind het leuk gaat vinden en anderzijds de functies die de ouders overtuigen om het product te kopen voor hun kind.

## Methode + reden

In het eerste deel van de Develop-fase is bewust gekozen om gebruikersinterviews af te nemen, maar deze keer gericht op de ouders. Dit zijn namelijk de personen die effectief de stap moeten zetten om het product te kopen. In de interviews werd de koopbaarheid afgetoetst. Verder werd er aan de hand van card sorting gekeken welke functies de ouders interessant vinden en een meerwaarde vinden aan het product. Uiteindelijk werd er nog gevraagd achter de ervaringen met habit changing products en de invloed hiervan. Er werd gekozen om interviews af te nemen om zo in gesprek te kunnen gaan met de ouder en door te vragen op bepaalde interessante antwoorden en keuzes.

## Respondenten

- Steekproefomschrijving (N = 5 )
De respondenten zijn ouders die kinderen hebben in de lagere school. Ze werden gecontacteerd via de lagere school van hun kind om vrijwillig deel te nemen aan dit interview.

## Onderzoeksvragen

- Onder welke omstandigheden zijn ouders bereidt het product aan te schaffen?
- Welke functies/elementen moet een product zeker bevatten?
- Wat zijn de ervaringen met andere habit changing products?

## Overzicht van de discussiegids en tijdsinschatting

- Deel 1 – Introductie product (5’)
- Deel 2 – Voorstelling Interviewee (5’)
- Deel 3 – Koopbereidheid (10’)
- Deel 4 – Functies (20’)
- Deel 5 – Ervaringen (10’)
- Deel 6 – Wrap-up (5’)

## Discussiegids

Introductie

Bedankt voor je deelname aan dit onderzoek.

Wij zullen starten met het project en onszelf kort voor te stellen.

Wij zijn Maxim, Sam en Jitse en we studeren aan de universiteit Gent campus Kortrijk met afstudeerrichting industrieel ingenieur industrieel ontwerpen.

Dit interview voeren we uit binnen het vak Project Gebruikgsgericht Ontwerp. Hier focussen we op het ontwerpen voor een gebruiker. Een interview afleggen is binenn dit vak dus zeer belangrijk om de noden en inzichten van de gebruiker te weten te komen.

Wij werken in dit vak rond duurzaamheid thuis. De vraag hierrond is dus hoe duurzaam leven gecombineerd kan worden met de alledaagse drukte van het gezinsleven met kinderen, alsook hoe kinderen zelf bewuster kunnen worden over duurzaam gebruik.

Ouder | Leeftijd Kind | Zonnepanelen? | Datum | Plaats
Sara | 12 & 8 | Nee | 28/2/2026 9u | Thuis
Marie | 8 | Ja | 28/2/2026 10u | Thuis
Lena | 5 & 8 | Ja | 28/2/2026 11u | Thuis
Bram | 5 & 6 | Nee | 2/3/2026 10u | Online
Jonas | 4 & 7 | Ja | 5/3/2026 20u | Online

In dit interview focussen we eerst op jullie blik op duurzaamheid, waarna de koopbereidheid van dit product wordt afgetoetst. Daarna wordt via een card sorting gekeken welke functies zeker aanwezig moeten zijn en welke functies overbodig zijn.

Wij zijn erg benieuwd naar jouw inzichten en ervaringen. Er zijn geen juiste of foute antwoorden. Ik ben gebaat bij jouw oprechte feedback rond de topics die we zullen behandelen.

We willen zeker nog onderstrepen dat alles wat straks in het gesprek aan bod komt in absolute confidentialiteit behandeld wordt. We zijn als studenten aan de Ugent namelijk gebonden aan de Europese privacyrichtlijnen. Voor de synthese met de inzichten en aanbevelingen worden individuele meningen sowieso ook geanonimiseerd. Je naam zal met andere woorden niet gekoppeld worden aan specifieke uitspraken. Een meer gedetailleerde beschrijving van onze intenties, verwerking van gegevens, en algemeen beleid kan je nalezen in de ‘Informed Concent’. Voor we van start kunnen met het interview, heb ik jouw expliciet akkoord nodig met dit document.

In deze studie worden geen persoonsgegevens verzameld. Uw privacy is van ons uiterste belang. We willen ook meedelen dat dit interview opgenomen wordt. Mocht u dit liever niet hebben zullen we daar rekening mee houden. Al de antwoorden die wij ontvangen zijn ook anoniem, wederom om uw privacy te beschermen. Mocht u hiermee akkoord gaan, stel ik voor dat we beginnen.

Ten slotte, hadden we je ook graag gevraagd of we straks dit gesprek mogen opnemen met een voice recorder, om ons gesprek te kunnen herbeluisteren wanneer de analyse wordt gemaakt. Uiteraard wordt deze opname niet gedeeld met derden, en verwijderd na afloop van het project. Als u hiermee akkoord gaat, stellen we voordat we het interview beginnen.

----------------------------[invullen informed consent & start recording] ----------------------------

Introductie Product

Voorstelling Interviewee
- Wat is je naam?
- Wat is je leeftijd?
- Hoeveel kinderen heb je en wat is hun leeftijd?
- Ben je zelf veel bezig met duurzaamheid?
- Vind je het belangrijk dat je kinderen een zicht hebben op verbruik?

Koopbereidheid
- Zou u het horloge kopen als deze te koop is in de winkel?
- Waarom wel/niet?


Zou het u aanspreken als de horloge geadverteerd wordt als een extra bij een abbonement van je energieleverancier? (Trust brokerage)
- Waarom wel/niet?

Functies (Card Sorting)

Functies
- Virtueel huisdier / mascotte
- Douche timer
- Wekelijks verhaaltje
- Challenges
- Fysieke knoppen
- Display dat langzaam ‘smog’ toont bij hoog verbruik
- Progressie zichtbaar maken (bv een groeiende boom)
- Mini quiz
- Gezinscompetitie
- Weekrapport voor de kinderen
- Horloge wordt licht warm bij hoog verbruik
- Verbrande geur bij te hoog verbruik
- Ledstrip dat van kleur verandert
- Trillen bij te veel verbruik
- Geluidje wanneer er te veel verbruik is
- Band die van kleur veranderd
- Herinneringen (bv doe het licht uit)

Categoriën
- Moet er zeker zijn
- Leuke toevoeging
- Overbodig

https://www.figma.com/board/p0Ifh4FJaBLmwDrdG8mfEW/Zu%C3%AFn?node-id=50-88&t=RKsYTqPNlwbYlD1S-1 (https://www.figma.com/board/p0Ifh4FJaBLmwDrdG8mfEW/Zu%C3%AFn?node-id=50-88&t=RKsYTqPNlwbYlD1S-1)

Ervaringen

- Heb je al eerdere ervaringen met smart devices speciaal voor kinderen?
- Heb je al eerdere ervaringen met smart devices op vlak van duurzaamheid?
- Heb je ervaringen met habit changing products? Denk aan een habit-app nee
- Werkte dit? Waarom wel/niet?
- Zo nee, zou dit werken voor jou? Waarom wel/niet?

Wrap-up
Wenst u zelf nog zaken toe te voegen?

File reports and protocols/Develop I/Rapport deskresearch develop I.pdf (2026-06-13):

# Rapport deskresearch develop I

# Project informatie

Projectnaam: Zuin
Zuin is een slim product voor kinderen dat hen bewust maakt van verbruik in huis en hen stimuleert om de interactie aan te gaan met hun ouders om energiezuiniger te leven.

Interviewer:
- Sam Verkimpe (Sam.Verkimpe@UGent.be), Student Industrieel Ingenieur Industrieel Ontwerpen
- Maxim Depever (Maxim.Depever@UGent.be), Student Industrieel Ingenieur Industrieel Ontwerpen
- Jitse Van Laer (Jitse.VanLaer@Ugent.be), Student Industrieel Ingenieur Industrieel Ontwerpen

# Doelstelling en kadering

De desk research van deze develop I periode focust op het vergelijken van horloges die zich op de markt bevinden en hoe de interacties tussen deze apparaten en de gebruikers verlopen (benchmarking). Ook wordt er gezocht naar horloges die speciaal voor kinderen gemaakt worden en hoe de interacties tussen deze apparaten en de kinderen als hoofdgebruikers verlopen. Als laatste wordt er ook onderzoek gedaan naar habit apps, hoe ze werken, performantie en belangrijke kenmerken die gebruikt worden om gewoontes aan te leren bij mensen.

# Benchmark horloges voor volwassenen

## Resultaten


Uit de analyse van de vier geselecteerde horloges blijkt dat fabrikanten fundamenteel verschillende interactieparadigma's en informatiestructuren hanteren om met de beperkte ruimte op een pols om te gaan. De gekozen interface-strategie hangt direct samen met de primaire gebruikssituatie (use-case) van het apparaat.

### Ervaringen

- G-Shock: Gebruikers waarderen de ongeëvenaarde robuustheid en betrouwbaarheid, maar ervaren de bediening als spartaans en soms lastig in te drukken of in te stellen zonder handleiding.
- Samsung Galaxy watch: De mechanische ring wordt massaal geprezen. Het geeft bevredigende tactiele feedback en lost het probleem op van vingers die het kleine scherm blokkeren tijdens het navigeren.
- Apple watch: Gebruikers roemen de vloeiende animaties en responsiviteit. Functies zoals de gebarenbesturing voelen intuïtief aan wanneer men de handen vol heeft. De keerzijde is dat de vele functies en menu's overweldigend kunnen overkomen voor nieuwe gebruikers.
- Garmin Fenix: Geprezen door sporters omdat de interface blindelings en met handschoenen te bedienen is. Reguliere consumenten vinden het systeem daarentegen vaak complex en intimiderend om te leren.

Een fysieke interactie met de horloges wint altijd, dit doordat de schermen meestal zeer klein zijn waardoor dat het geruiken van de touchscreens vaak niet goed lukt door het bedekken van het scherm bij interactie. Wanneer dat de fysieke interacties een weerspiegeling zijn van de UI of van de informatiearchtitectuur, worden ze nog beter ervaren.

# Benchmarking horloges voor kinderen

## Resultaten


### Ervaringen

- Vivofit: Ouders waarderen het beloningssysteem voor klusjes (gamification) en het feit dat de batterij een heel jaar meegaat. Het meest genoemde pijnpunt is het kleine, donkere scherm zonder achtergrondverlichting.
- X6 Play: Biedt ouders enorme gemoedsrust dankzij de GPS-tracking en de 'Schoolmodus' (die het apparaat onder schooltijd blokkeert voor afleiding). De actieve 4G- en GPSverbinding resulteert wel in een veel kortere batterijduur (dagelijks opladen).
- Kidizoom: Wordt geprezen als 100% privacy-veilig (want volledig offline) en ideaal vermaak voor onderweg. Hoewel volwassenen het horloge vaak erg lomp vinden en klagen over de lage resolutie van de camera, zijn kinderen dol op de interactieve games en felle animaties.

De interface van kinderhorloges is ontworpen om cognitieve en motorische beperkingen op te vangen door middel van robuuste ontwerpen, grote knoppen en zeer ondiepe menu's. De echte complexiteit en de instellingen bevinden zich bijna nooit op het horloge zelf, maar zijn bewust verplaatst naar de beheer-app op de smartphone van de ouder.

# Research habit apps

## Resultaten

### 1. Habitica (De Gamification App)

- Aanpassing voor de doelgroep: De app is ontworpen voor mensen die moeite hebben met intrinsieke motivatie. Door het leven als een 'Role Playing Game' in te richten, worden dagelijkse taken omgezet in queesten waarbij je extrinsieke beloningen krijgt (virtueel goud en ervaringspunten).
- Interactiemogelijkheden: Aantikken van vinkjes, items 'kopen' in een virtuele winkel om je avatar aan te kleden, en sociale interactie (chatten en samen virtuele monsters verslaan in een 'Party' door in het echte leven je taken te doen).
- Gebruikerservaringen (Reviews): Gebruikers met bijvoorbeeld ADHD prijzen de app enorm vanwege de dopamine-hit die het afvinken geeft. Het grootste pijnpunt in reviews is dat de app genadeloos kan zijn: vergeet je een taak, dan verliest je poppetje levenspunten. Ook wordt de interface soms als 'te druk' ervaren.
- Visuele stijl: Een drukke, nostalgische 8-bit / 16-bit retro pixel-art stijl. Veel felle kleuren en kleine icoontjes.
- Informatie hiërarchie: Kolom- en tabblad-gestuurd. Het hoofdscherm is verdeeld in vier verticale lijsten: Habits (+ en - knoppen), Dailies (dagelijks), To-Dos (eenmalig) en Rewards. Er zijn diepe, geneste menu's voor de RPG-elementen (zoals je inventaris met zwaarden en huisdieren).

### 2. Streaks (De Minimalistische App)

- Aanpassing voor de doelgroep: Gericht op minimalisten en aanhangers van de 'Don't break the chain' methode. De app dwingt focus af door je maximaal 24 gewoontes te laten instellen. Minder is meer.
- Interactiemogelijkheden: Extreem tactiel. Je moet een icoon lang indrukken (Long-press) om een taak te voltooien. De cirkel vult zich met een vloeiende animatie en eindigt met een zeer bevredigende haptische trilling (trilmotor van de telefoon).
- Gebruikerservaringen (Reviews): Winnaar van een Apple Design Award. Gebruikers zijn lovend over de strakke vormgeving en de naadloze integratie met Apple Health (waardoor een gewoonte als 'loop 10.000 stappen' automatisch wordt afgevinkt). Een nadeel is dat de app erg streng voelt; één dag missen betekent dat je reeks naar nul gaat, wat demotiverend kan werken.
- Visuele stijl: Ultra-minimalistisch. Geen tekst, alleen simpele witte vector-iconen op een effen, contrasterende achtergrondkleur.

- Informatie hiërarchie: Extreem plat (grid-systeem). Het hoofdscherm toont enkel 6 grote ronde iconen. Klik je op een icoon, dan 'draait' deze om en zie je een simpele kalender en statistieken. Geen menu's of tabbladen.

### 3. Fabulous (De Coaching App)

- Aanpassing voor de doelgroep: Gemaakt voor mensen die niet weten waar ze moeten beginnen. In plaats van een lege lijst, neemt de app je bij de hand op basis van gedragswetenschap (ontwikkeld met onderzoekers van Duke University).
- Interactiemogelijkheden: Veel swipen door 'Journeys' (verhalende reizen), luisteren naar audiocoaching, en het starten van een 'Routine' waarbij de app je scherm overneemt en een timer aanzet voor elke specifieke taak (bijv. 5 minuten mediteren).
- Gebruikerservaringen (Reviews): Veel lof voor de esthetiek en het feit dat de app je echt dwingt om klein te beginnen (stap 1 is vaak letterlijk: drink 1 glas water na het opstaan). Een veelgehoorde frustratie in reviews is echter dat de app erg rigide/inflexibel is en agressief pusht op het nemen van een (duur) premium abonnement.
- Visuele stijl: Schermvullende, dromerige en kleurrijke vectorillustraties. Veel gebruik van vloeiende, rustgevende animaties.
- Informatie hiërarchie: Lineair en gelaagd. De app dicteert de flow. Het hoofdscherm is een tijdlijn (Morning, Afternoon, Evening). Je hebt als gebruiker relatief weinig vrijheid om de interface zelf in te delen vergeleken met de andere apps.

### 4. Habitify (De Dashboard App)

- Aanpassing voor de doelgroep: Voor de productiviteits-nerd die alles wil meten. Het is platformonafhankelijk (werkt perfect synchroon op Mac, Windows, iOS, Android en horloges) en draait puur om dataverzameling en analyse.
- Interactiemogelijkheden: Snel en efficiënt: een simpele tik of swipe naar rechts om een gewoonte af te vinken. Swipen naar links om te bewerken. Interactie met interactieve grafieken om verschillende tijdsperiodes te bekijken.
- Gebruikerservaringen (Reviews): Gebruikers waarderen de 'no-nonsense' professionele uitstraling en de betrouwbare synchronisatie tussen apparaten. Het gebrek aan gamification wordt door sommigen als saai ervaren. Ook wordt vaak genoemd dat de gratis versie erg beperkt is qua hoeveelheid gewoontes die je kunt toevoegen.
- Visuele stijl: Zakelijk, strak en modern. Vergelijkbaar met een professionele to-do app of fitness-dashboard. Veel gebruik van staafgrafieken, cirkeldiagrammen en donkere modus (Dark Mode).
- Informatie hiërarchie: Navigatiebalk onderaan (Bottom Bar). Verdeeld in 'Vandaag' (een simpele chronologische takenlijst), 'Voortgang' (een diep dashboard met talloze grafieken en statistieken per gewoonte), en 'Instellingen'.
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

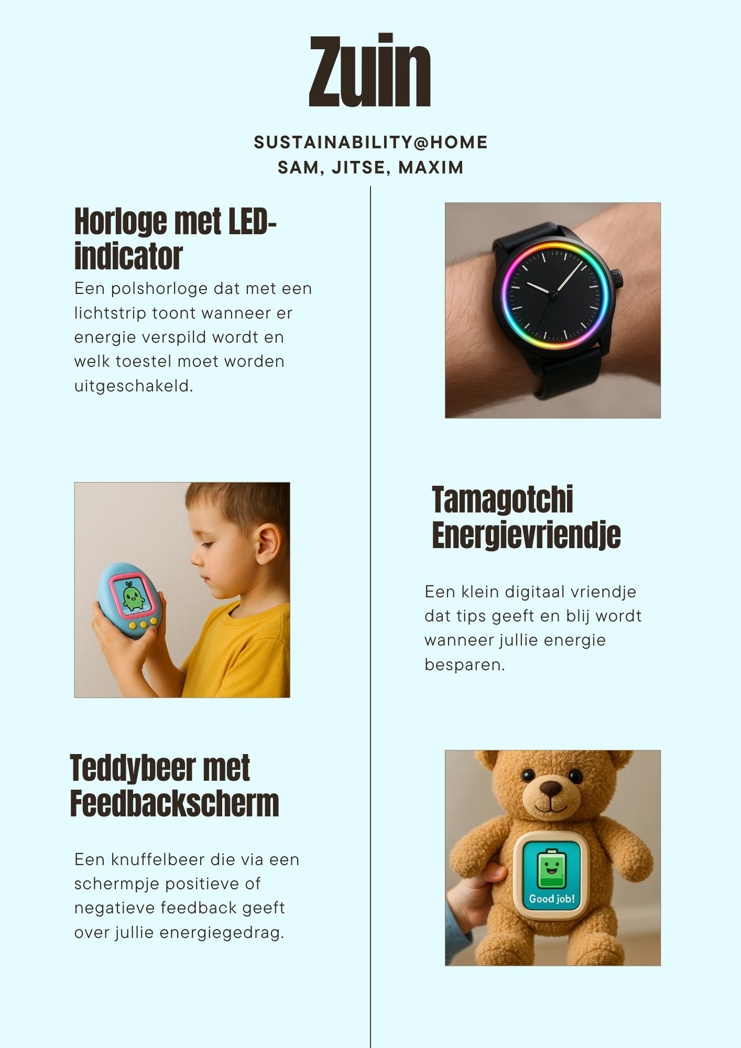
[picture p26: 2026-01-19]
img/Concept Poster.jpg

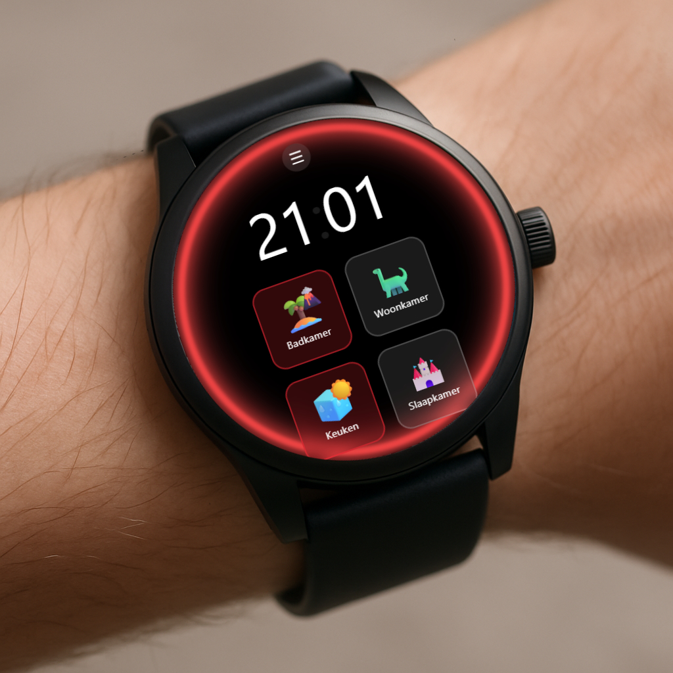
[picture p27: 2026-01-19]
img/Representatie_Concept.jpg

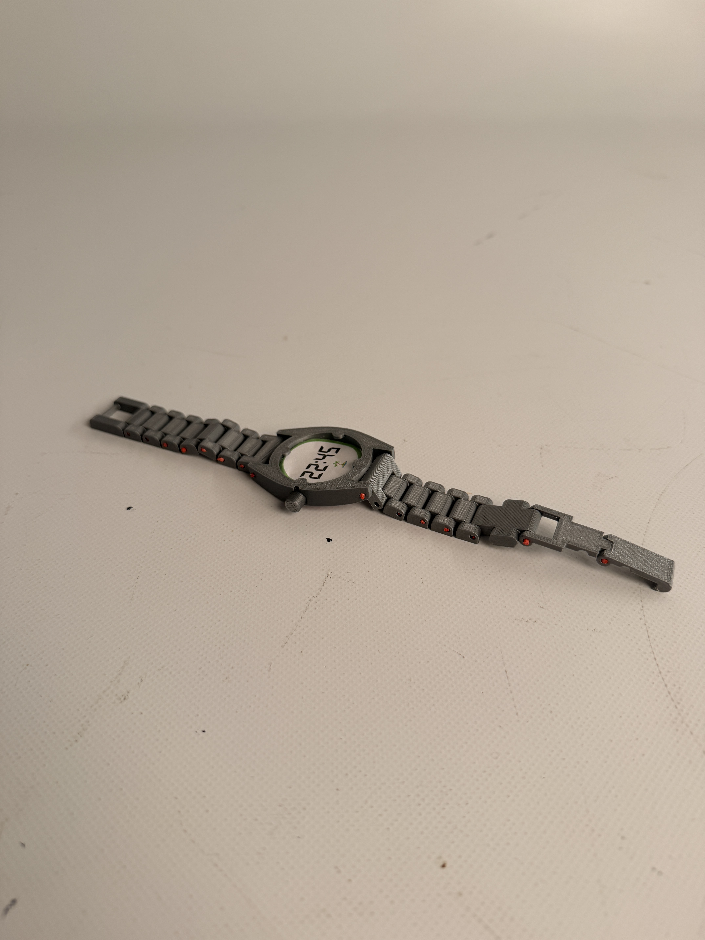
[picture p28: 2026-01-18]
img/Horloge.JPG

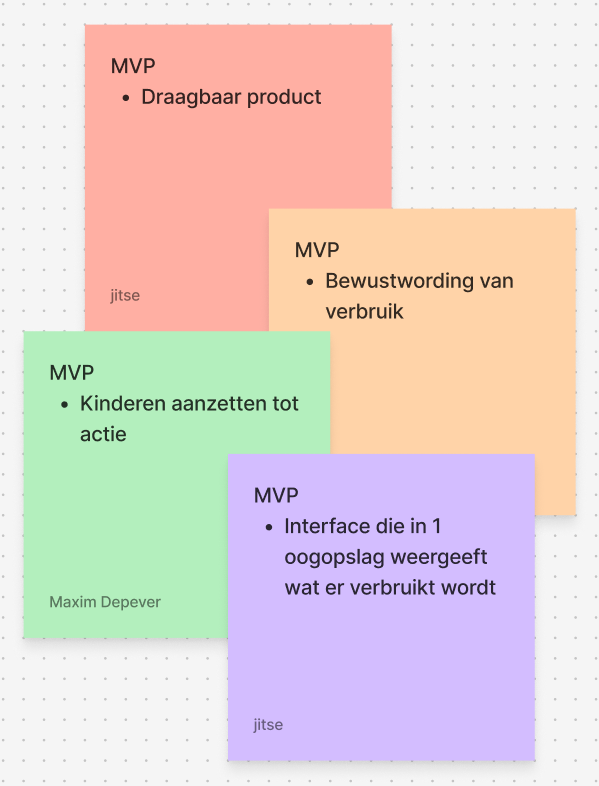
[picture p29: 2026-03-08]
img/MVP3.png

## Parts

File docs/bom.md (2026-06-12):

## Bill of materials

Welkom op de pagina over het fysiek prototyping van het ZUIN systeem.
Hieronder vinden jullie een overzicht van de materialen die we gebruiken en de bedoeling van het systeem.

### ZUIN systeem

Het ZUIN systeem bestaat uit 2 delen, de hub en de wearable. In theorie zou de hub alle data van de slimme teller binnen moeten krijgen, aan de hand van een ML model voorspellingen moeten maken en zo het verbruik van het huishouden moeten begrijpen. De hub zou dan via een BLE signaal alle belangrijke info naar de wearable sturen die fungeert als een soort slave in het systeem. De wearable is een soort van horloge dat op een speelse manier alle informatie meedeelt aan het kind zodat het kind hierop kan reageren. Het is de bedoeling dat we deze functionaliteit zo goed mogelijk nabootsen in ons prototype. 

Momenteel hebben we een hub die signalen via BLE doorstuurt naar het horloge. Het horloge beeld dan de belangrijke info op het ronde scherm af.

// foto toevoegen

### Bill of Materials

#### Deel 1: Hub
| Buy or make | Component | Hoeveelheid | Prijs (€) | Opmerkingen |
| :---: | :--- | :---: | :---: | :--- |
| Buy | Arduino Nano 33 IoT | 1 | 23.90 | Voor het sturen van signalen en interactie met schakelaars |
| Buy | Grove Arduino Nano shield | 1 | 4.25 | Voor het makkelijk connecteren van componenten tijdens prototyping |
| Buy | Grove button | 1 | 1.80 | Voor het uitschakelen van fictieve lampen |
| Buy | Grove Led | 2 | 2.50 | Voor het tonen van states |
| Buy | Grove 16X2 LCD screen | 1 | 7.00 | Voor het tonen van teksten over de status van het huis |
| Make | Onderkant van casing | 1 | - | PLA FDM 3D print [Stp](../cad/Develop%202/SV-Hub_Onderkant-001.stp) |
| Make | Bovenkant van casing | 1 | - | PLA FDM 3D print [Stp](../cad/Develop%202/SV-Hub_Bovenkant-001.stp) |

#### Deel 2: Wearable
| Buy or make | Component | Hoeveelheid | Prijs (€) | Opmerkingen |
| :---: | :--- | :---: | :---: | :--- |
| Buy | Rond LCD-scherm met ingebouwde esp32 | 1 | 25.00 | Voor het tonen van speelse en visuele feedback aan het kind |
| Make | Deksel | 1 | - | PLA FDM 3D print [Stp](../cad/Horloge/prt%20files/Deksel.prt) |
| Make | Draairing | 1 | - | PLA FDM 3D print [Stp](../cad/Horloge/prt%20files/ring.prt) |
| Make | Onderkant horloge | 1 | - | PLA FDM 3D print [Stp](../cad/Horloge/prt%20files/onderkant%20horloge.prt) |

### schema's van de hardware

 <p align="center">
  
  <br>
  <em>Figuur 1: Overzicht van de hardware van de hub.</em>
</p>

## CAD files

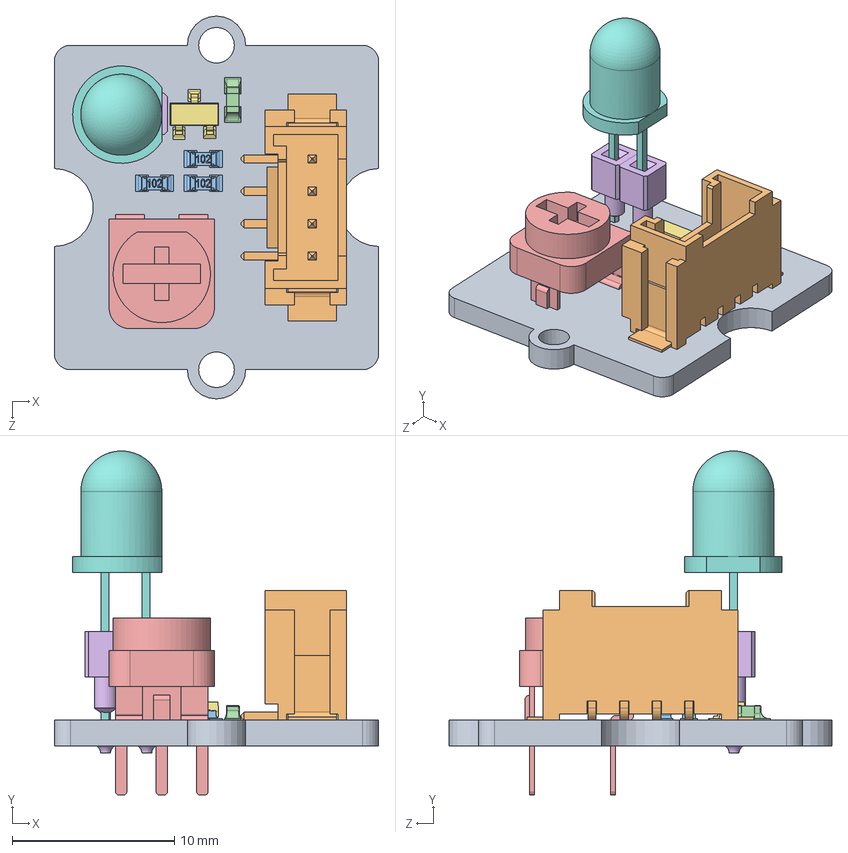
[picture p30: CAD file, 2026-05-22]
cad/Develop 2/Import/grove-led-arduino-1.snapshot.1/Grove LED.SLDASM
20.0 x 21.2 x 23.6 mm
PCB grove 20x20
Connecteur Grove (droit CMS)
603 resistor 102 x 3
603 cap on pad
Pot - RES_VAR1
Contact F
ssot3
LED 5mm

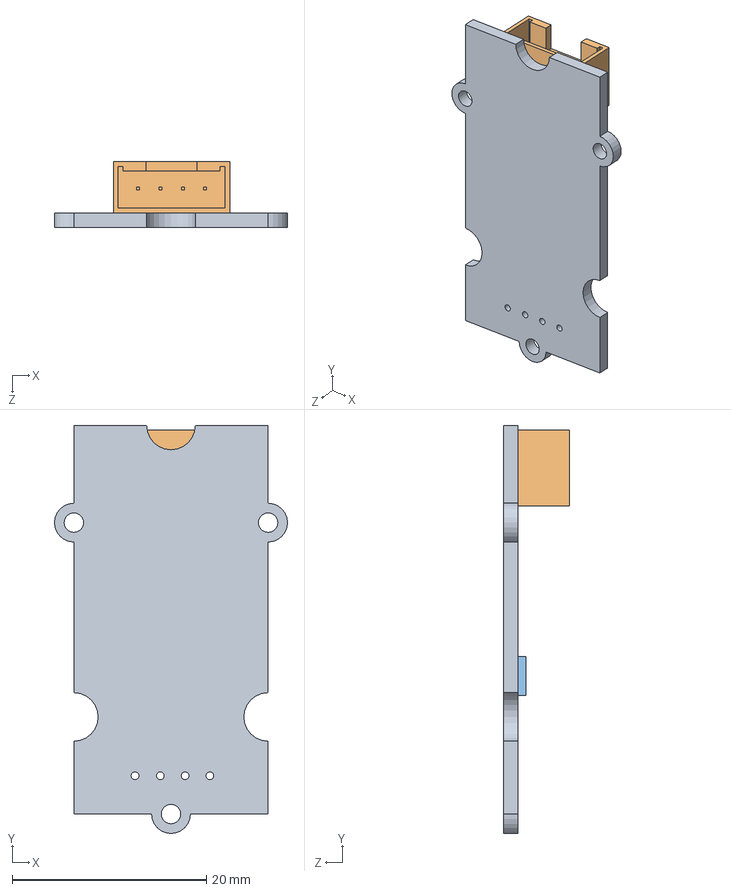
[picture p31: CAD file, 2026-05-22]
cad/Develop 2/Import/grove-imu-9-dof-v1-1.snapshot.1/Grove IMU.SLDASM
24.0 x 42.0 x 6.80 mm
Grove IMU Board
Grove Connecteur
MPU9150

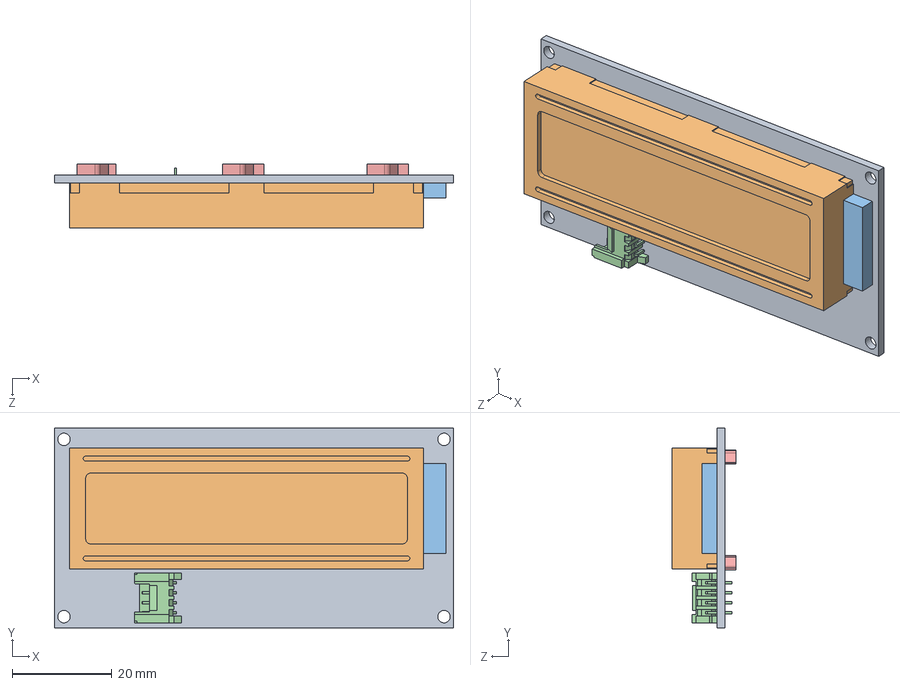
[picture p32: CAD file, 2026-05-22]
cad/Develop 2/Import/grove-16x2-lcd-black-on-yellow-1.snapshot.3/Grove-16x2 LCD (Black on Yellow).SLDASM
80.0 x 40.0 x 12.8 mm
PCB
Ecran
Bloc alim
Connecteur Grove LCD
Patte x 6

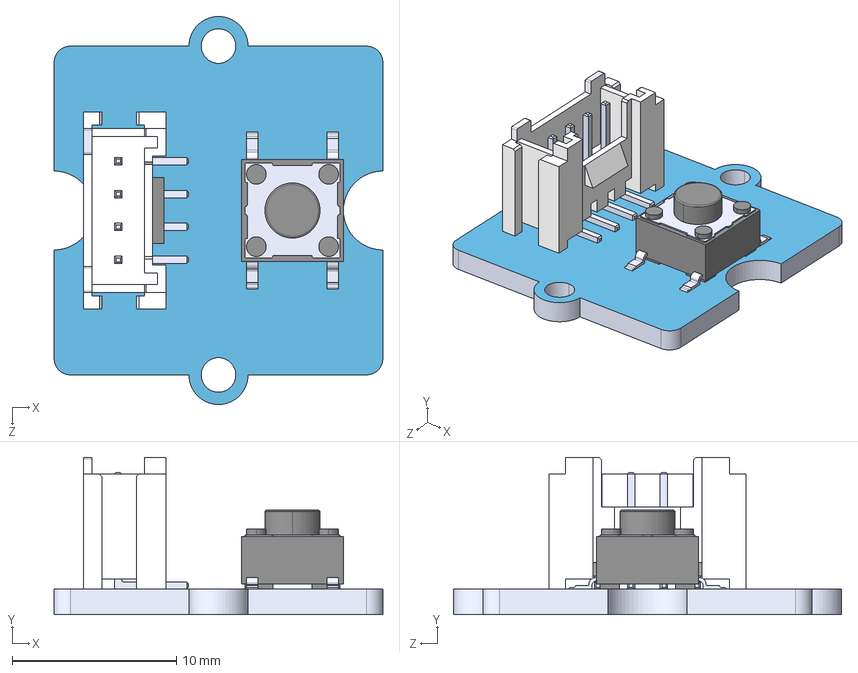
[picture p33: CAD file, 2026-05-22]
cad/Develop 2/Import/Grove Button.STEP
20.0 x 9.55 x 23.6 mm
PCB (small)
Grove Connector (sit)
button
foot (buton) x 4

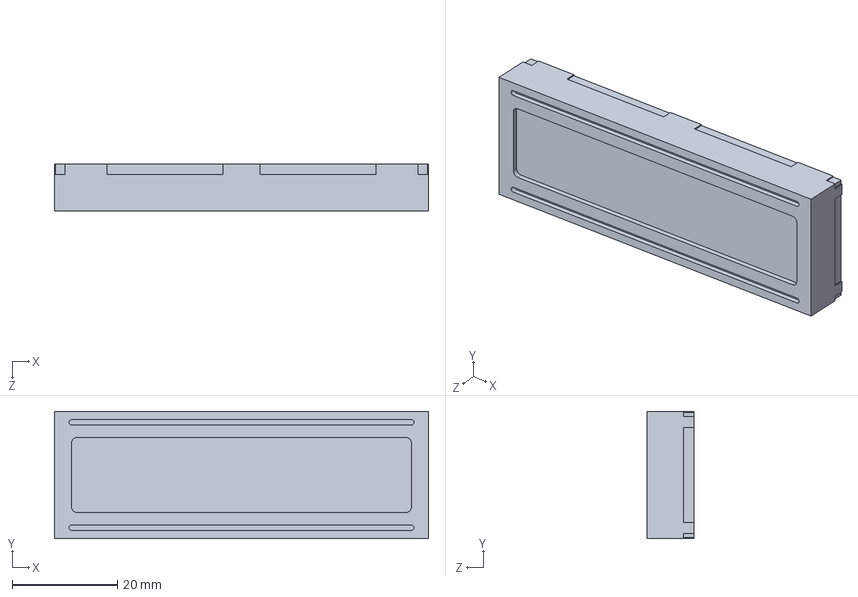
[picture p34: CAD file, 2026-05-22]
cad/Develop 2/Import/grove-16x2-lcd-black-on-yellow-1.snapshot.3/Ecran.SLDPRT
71.0 x 24.2 x 9.00 mm

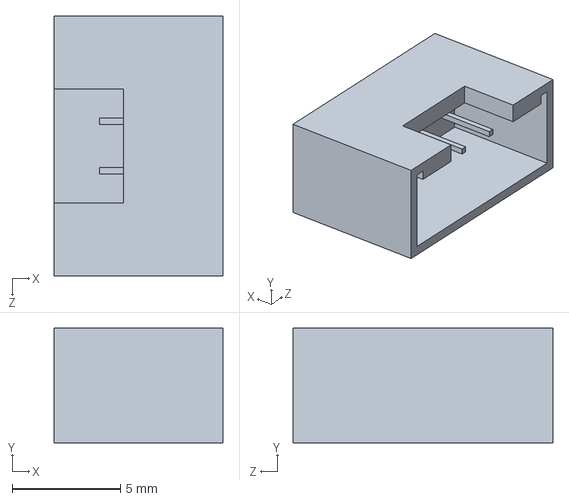
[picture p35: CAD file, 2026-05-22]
cad/Develop 2/Import/grove-imu-9-dof-v1-1.snapshot.1/Grove Connecteur.SLDPRT
7.80 x 5.30 x 12.0 mm

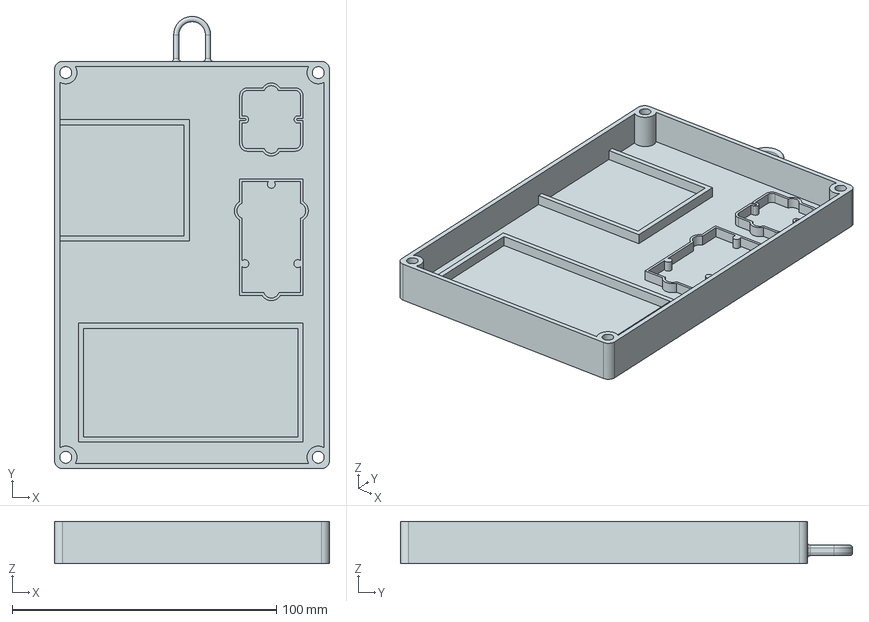
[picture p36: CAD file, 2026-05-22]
cad/Develop 2/SV-Wearable_Onderkant-001_1.stp
104.0 x 171.0 x 16.0 mm

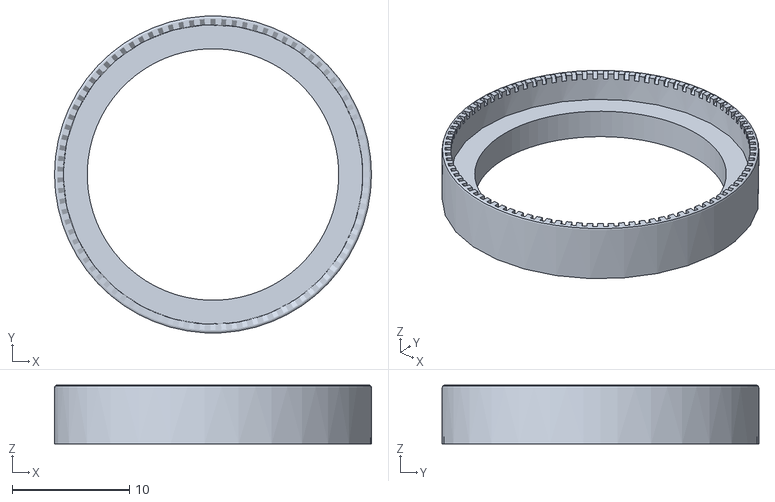
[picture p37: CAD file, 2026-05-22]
cad/Develop 3/Ring 2.stl
27.0 x 27.0 x 5.00

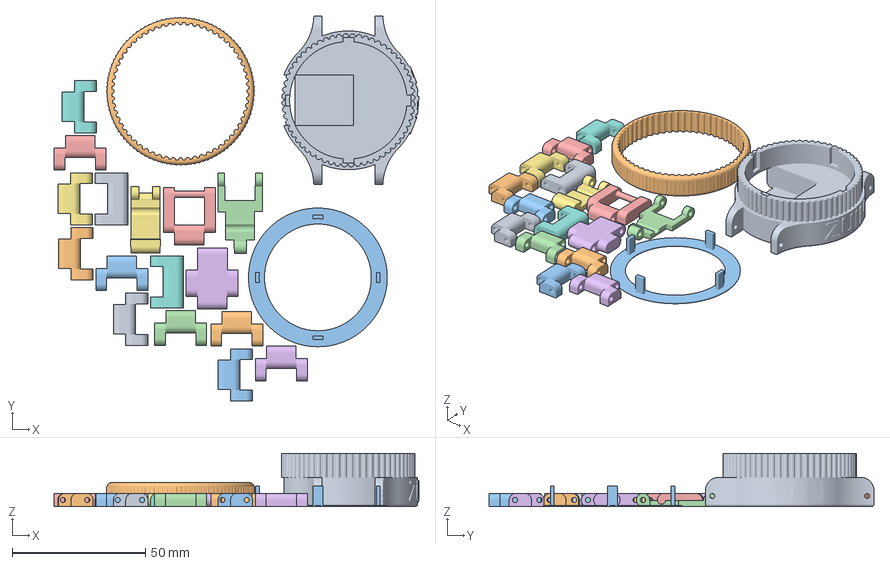
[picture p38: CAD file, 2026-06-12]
cad/Horloge/3mf files/Zuin_Horloge.3mf
136.8 x 144.3 x 20.0 mm
Onderkant
ring
Deksel
Case, Buckle, And Solid Wristband.stl_2
Case, Buckle, And Solid Wristband.stl_4
Case, Buckle, And Solid Wristband.stl_7
Case, Buckle, And Solid Wristband.stl_9
Case, Buckle, And Solid Wristband.stl_11
Case, Buckle, And Solid Wristband.stl_13
Case, Buckle, And Solid Wristband.stl_15
Case, Buckle, And Solid Wristband.stl_17
Case, Buckle, And Solid Wristband.stl_18
Case, Buckle, And Solid Wristband.stl_19
Case, Buckle, And Solid Wristband.stl_20
Case, Buckle, And Solid Wristband.stl_22
Case, Buckle, And Solid Wristband.stl_23
Case, Buckle, And Solid Wristband.stl_24
Case, Buckle, And Solid Wristband.stl_16
Case, Buckle, And Solid Wristband.stl_21

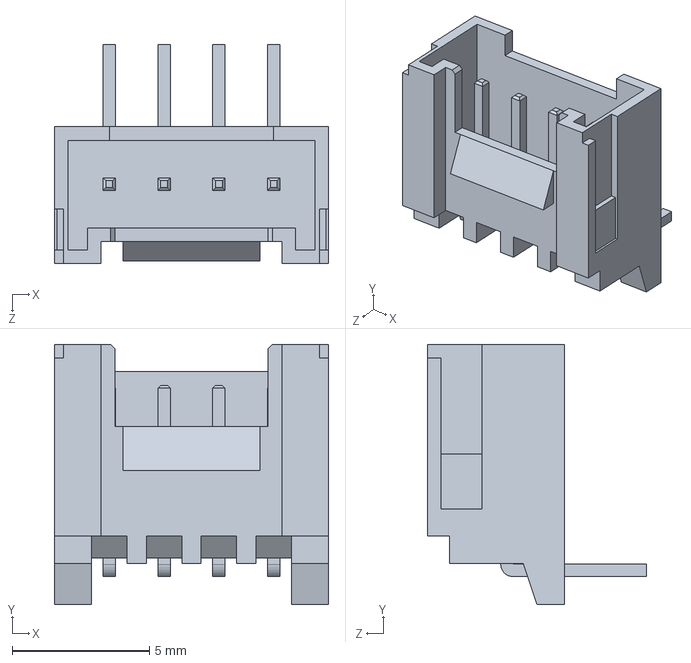
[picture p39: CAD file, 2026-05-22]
cad/Develop 2/Import/grove-16x2-lcd-black-on-yellow-1.snapshot.3/Connecteur Grove LCD.SLDPRT
10.0 x 9.50 x 8.00 mm

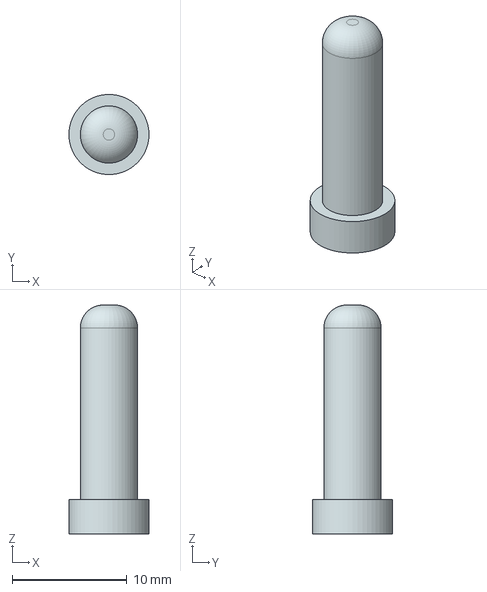
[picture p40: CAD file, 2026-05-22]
cad/Develop 2/SV-P-Knopje-001.stp
6.99 x 7.00 x 20.0 mm

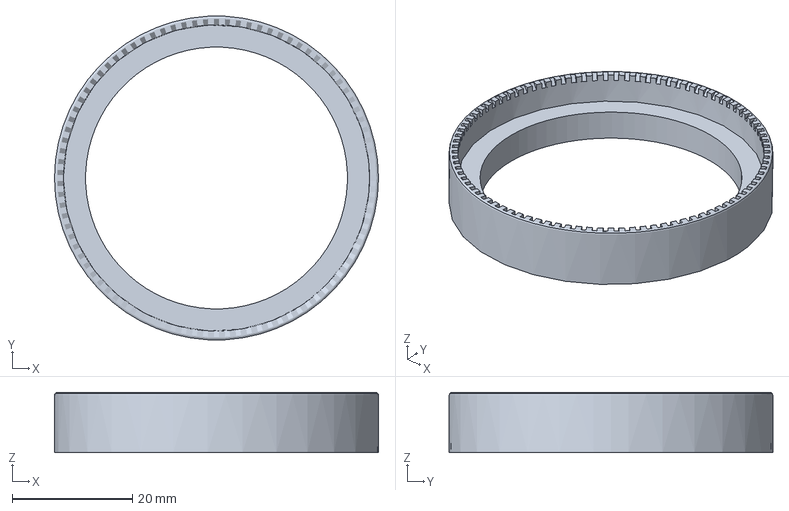
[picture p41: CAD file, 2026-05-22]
cad/Develop 3/Ring 2_1.3mf
54.0 x 53.9 x 10.0 mm

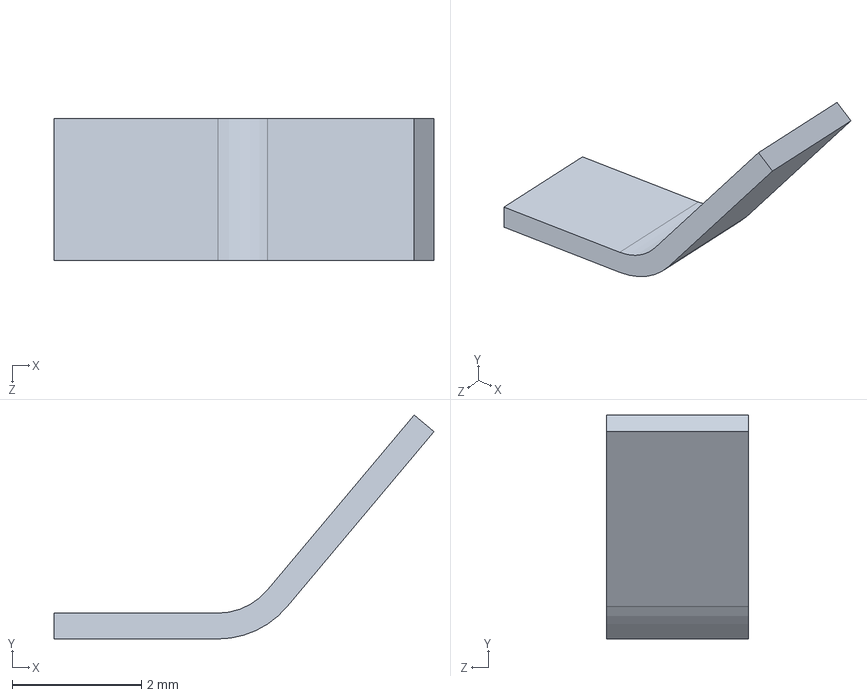
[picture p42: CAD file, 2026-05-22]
cad/Develop 2/Import/grove-16x2-lcd-black-on-yellow-1.snapshot.3/Patte.SLDPRT
5.88 x 3.46 x 2.20 mm

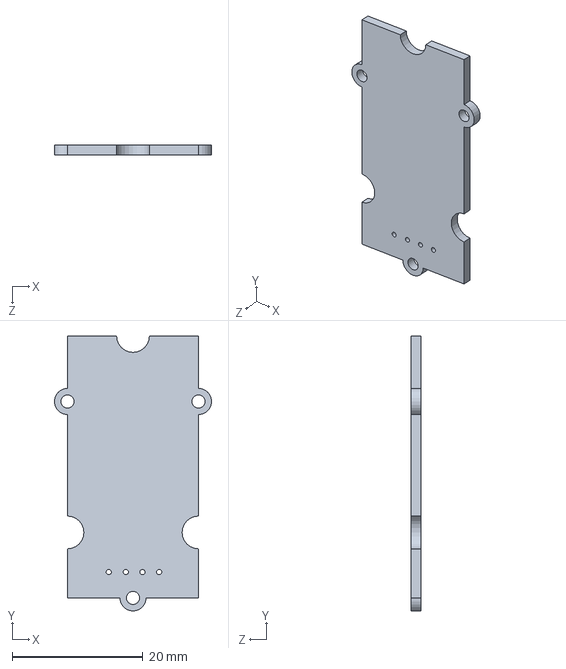
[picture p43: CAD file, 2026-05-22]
cad/Develop 2/Import/grove-imu-9-dof-v1-1.snapshot.1/Grove IMU Board.SLDPRT
24.0 x 42.0 x 1.50 mm

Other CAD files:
cad/Develop 2/SV-Hub_Bovenkant-001.stp
cad/Develop 3/base horloge.3mf
cad/Develop 2/Import/grove-16x2-lcd-black-on-yellow-1.snapshot.3/PCB.SLDPRT
cad/Develop 2/Import/grove-imu-9-dof-v1-1.snapshot.1/MPU9150.SLDPRT
cad/Develop 2/Import/Grove Button_step.prt
cad/Develop 2/Import/Grove Connector (sit).prt
cad/Develop 2/Import/PCB (small).prt
cad/Develop 2/Import/button (mounted).prt
cad/Develop 2/Import/button.prt
cad/Develop 2/Import/foot (buton).prt
cad/Develop 2/Import/grove-16x2-lcd-black-on-yellow-1.snapshot.3/Bloc alim.SLDPRT
cad/Develop 2/Import/grove-16x2-lcd-black-on-yellow-1.snapshot.3/Bloc alim_sldprt.prt
cad/Develop 2/Import/grove-16x2-lcd-black-on-yellow-1.snapshot.3/Connecteur Grove LCD_sldprt.prt
cad/Develop 2/Import/grove-16x2-lcd-black-on-yellow-1.snapshot.3/Ecran_sldprt.prt
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

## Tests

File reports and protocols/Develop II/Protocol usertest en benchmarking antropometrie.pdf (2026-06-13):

# Antropometrische gegevens & ergonomie protocol – develop 2

# Project informatie

Projectnaam: Zuin
Zuin is een slim product voor kinderen dat hen bewust maakt van verbruik in huis en hen stimuleert om de interactie aan te gaan met hun ouders om energiezuiniger te leven.

Interviewer:
- Sam Verkimpe (Sam.Verkimpe@UGent.be), Student Industrieel Ingenieur Industrieel Ontwerpen
- Maxim Depever (Maxim.Depever@UGent.be), Student Industrieel Ingenieur Industrieel Ontwerpen
- Jitse Van Laer (Jitse.VanLaer@Ugent.be), Student Industrieel Ingenieur Industrieel Ontwerpen

# Antropometrie

## Touchpoints:

- Ronde draaiknop
- Scherm
- Band rond pols
Methode: Deze 3 touchpoints worden onderzocht aan de hand van een antropometrische analyse.

## Range of motion

- Comfortabel kunnen wandelen met horloge aan
- Kunnen spelen met horloge aan
- Arm naar boven brengen om scherm te kunnen lezen

Methode: Tijdens een usertest die plaatsvindt in de bibliotheek van de krook worden voorbijgangers gevraagd of ze zouden willen deelnemen aan een test rond een kinderhorloge. De kinderen krijgen een aantal prototypes om uit te testen, deze mogen ze gedurende een korte periode aandoen, waarna er korte vragen gesteld worden omtrent de vormgeving en het gewicht van het horloge.

# Ergonomie

## Sensoriële ergonomie

Zien
| Tekst moet voldoende groot | Baseren op kinderboeken van juiste leeftijdscategorie
| Status in 1 oogopslag kunnen zien | User testen: Buzzer, led, haptic feedback (Testen Hub & Wearable)
| Scherm comfortabel voor kinderen

Horen
| Notificaties moeten opvallend zijn maar niet storen | User testen: Buzzer (Testen Hub & Wearable)

Voelen
| Notificaties moeten opvallend zijn maar niet storen | User testen: Haptic feedback (Testen Hub & Wearable)
| Materiaal moet comfortabel aanvoelen zodat kinderen het horloge willen dragen

Methode: Tijdens het verloop van het tweede semester worden een reeks met grote usertests afgelegd waar de gebruiker aan de hand van een hub en een wearable device leert omgaan met het gehele ZUÏN systeem. Tijdens deze tests worden deze sensoriele triggers getest en gevalideerd welke het beste resultaat geven om het kind te triggeren.

## Prototypes

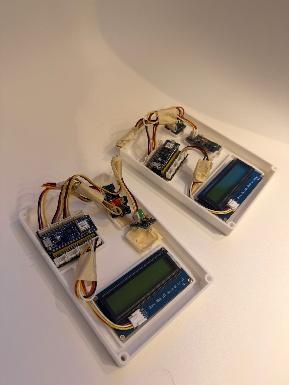
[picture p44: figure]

Figuur 1: Prototype Hub & Wearable

# Tests

## Usertest antropometrie

Deze test worden uitgevoerd in bibliotheek van de krook. Gezinnen worden aangesproken en gevraagd of ze graag zouden willen deelnemen aan een klein onderzoek. De kinderen krijgen dan de mogelijkheid om meerdere prototypes uit te testen en na afloop worden er kleine bijvragen gesteld. Ook worden de kinderen aan enkele proeven onderworpen om scenario’s na te bootsen zoals dat een kind de horloges in een realistisch scenario zou dragen.

## Prototypes

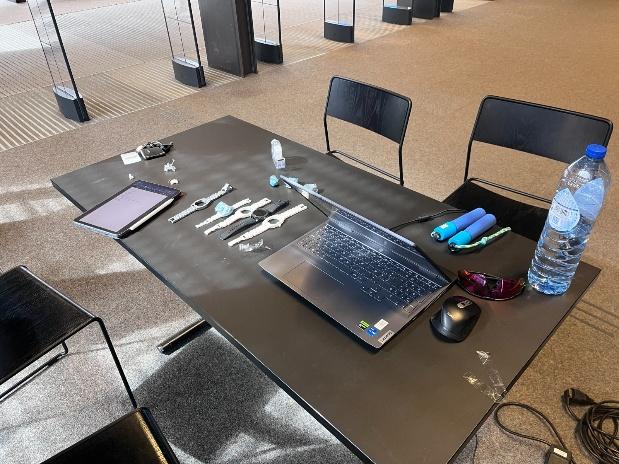
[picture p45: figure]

Figuur 2: Testen van de prototypes in de Krook

## Vragen

Bij aanvang van test:
- Bent u links of rechtshandig?
- Hoe oud bent u?
- Heb je eerder al een horloge gedragen en welk horloge was dit?
Na testen van prototypes:
- Welk van de 3 horloges vond je het leukste om te dragen tijdens onze kleine testen?
- Welk horloge vond je het zwaarst en welk het lichtst?
- Welk horloge had het beste gewicht volgens jou?
- Welk horloge had de perfecte grote voor jou?
Kleine proeven tijdens test van horloge:
- Springtouwen
- Kijken naar horloge
- Interageren met horloge

## Usertest sensoriele ergonomie

Deze Testen worden uitgevoerd parallel met deze van De hub en de wearable. (https://ugentbe-my.sharepoint.com/personal/sam_verkimpe_ugent_be/Documents/Academiejaar%202025-26/Project%20gebruiksgericht%20ontwerpen/Jaarproject/Semester%2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)

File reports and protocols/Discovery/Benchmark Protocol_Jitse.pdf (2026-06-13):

# Benchmark Protocol

## Project informatie

Projectnaam: Sustainability @ Home
In dit project wordt er opzoek gegaan naar een manier om thuis duurzaam te leven. Een simpel object zal op een eenvoudige manier aangeven welke keuzes gemaakt kunnen worden, zonder extra cognitieve of financiële belasting.

Onderzoeker: Jitse Van Laer (Jitse.VanLaer@Ugent.be) Student Industrieel Ingenieur Industrieel Ontwerpen

## Doelstelling en kadering

Doordat het leven steeds duurder en schaarser wordt, is het steeds urgenter om duurzame keuzes te maken. Anderzijds is het leven ook steeds drukker en ingewikkelder aan het worden, waardoor deze keuzes niet altijd vanzelfsprekend te maken zijn.

## Oriëntatie in ontwerpproces

Discovery-fase

## Methode

Deskresearch van benchmarks

## Materialen

Uit een eerder gevoerde enquête kwam een benchmark die al gebruikt wordt door de doelgroep. Verder werden er benchmarks bekomen uit artikels van het literatuuronderzoek. De laatste bron van benchmarks is ChatGPT, die ook enkele voorbeelden gaf.

## Stap voor stap beschrijving

1) Producten selecteren
2) Info over de producten zoeken
3) Positieve en negatieve zaken benoemen
4) Conclusie

## Data-analyse

Benchmark_Rapport.docx (https://ugentbe-my.sharepoint.com/:w:/g/personal/sam_verkimpe_ugent_be/IQD2sjlyIDcPSKbX_eMs5qYrAX9bR0QHjSUwxY6TmReKtXE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)

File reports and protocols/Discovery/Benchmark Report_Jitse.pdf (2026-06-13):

# Benchmark Report

## Project informatie

Projectnaam: Sustainability @ Home
In dit project wordt er opzoek gegaan naar een manier om thuis duurzaam te leven. Een simpel object zal op een eenvoudige manier aangeven welke keuzes gemaakt kunnen worden, zonder extra cognitieve of financiële belasting.

Onderzoeker: Jitse Van Laer (Jitse.VanLaer@Ugent.be) Student Industrieel Ingenieur Industrieel Ontwerpen

## Doelstelling en kadering

Doordat het leven steeds duurder en schaarser wordt, is het steeds urgenter om duurzame keuzes te maken. Anderzijds is het leven ook steeds drukker en ingewikkelder aan het worden, waardoor deze keuzes niet altijd vanzelfsprekend te maken zijn.

## Oriëntatie in ontwerpproces

Discovery-fase

## Methode

Deskresearch van benchmarks

## Onderzoeksvragen

- Wat is er al op de markt?
- Wat zijn de positieve en negatieve punten van wat er al bestaat?

## Waarom benchmarken?

Door te weten wat er al op de markt is, is er enerzijds duidelijk wat er niet meer ontworpen moet worden, maar anderzijds kan het ook vertellen waar er nog gebrek aan is. Er kan ook verder gewerkt worden op benchmarks en deze verbeteren of inspiratie opdoen uit deze al bestaande producten.

## Protocol

Benchmark Protocol.docx (https://ugentbe-my.sharepoint.com/:w:/g/personal/jitse_vanlaer_ugent_be/EWR1NKv_KntJjAASId9nqUgBSL25ral65LFWNIXYTThgWA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)

## Sample

Er worden 10 benchmarks onderzocht.

1) Energy management system (EMS)
- Beschrijving:
Het systeem regelt alle stuurbare componenten (zoals de thuisbatterij, laadpaal, warmtepomp, bufferboiler) volgens de meest efficiënte ecologische en economische algoritmen. Verder zal het systeem ook jouw hoofd elektrische aansluiting bewaken.
- Het wordt geïnstalleerd in je elektriciteitskast. Vanuit die module verzamelt het EMS in realtime gegevens over je energieproductie en stuurt dit door naar een software
- Moet worden geïntegreerd door een expert
- Een EMS optimaliseert je energieverbruik en minimaliseert zo je ecologische en economische impact. Het monitort en stuurt bovendien enkel je energieproductie en -verbruik.
- https://aetec.be/wat-is-een-energy-management-system-ems-en-wat-doet-het/
2) Domotica
- Beschrijving:
Een domoticasysteem bestaat uit slimme elektrische apparaten die via een lokaal netwerk kunnen samenwerken. De toepassingen van domotica in huis zijn talloos: van beveiliging tot zonwering en van verwarming tot verlichting. Het hoeft niet moeilijk te zijn: er zijn steeds meer betaalbare, toegankelijke producten te vinden die jouw alledaagse leven net een stukje makkelijker maken. Bijvoorbeeld de smart home producten van Somfy.
- Bedien je apparaten via je smartphone of koppel ze aan je smart home hub
- Een domotica systeem bestuurt vooral comfort technieken zoals licht, geluid, rolluiken, zonwering en dergelijke
- https://www.somfy.be/nl-be/keuzehulp/domotica/in-huis
3) Smappee
- Beschrijving:
Smappee Infinity biedt een complete digitale energiehub waarmee woningen of gebouwen hun energieverbruik, zelfopwekking en laad-/opslagprocessen slim kunnen afstemmen om kosten te drukken en efficiëntie te verhogen.
- Het systeem bestaat uit hardware-modules zoals stroomklemmen (CT’s of Rogowski-spoelen), een gateway (Genius) en een cloud-gebaseerd platform.

> Via de bijhorende app zie je exact welk toestel wanneer hoeveel energie verbruikt; dankzij dynamische load-balancing wordt opgewekte zonne-energie optimaal gebruikt en wordt onnodige teruglevering aan het net geminimaliseerd.
- https://www.smappee.com/nl/energiemanagement/
4) EnergyControl Monitor
- Beschrijving:
Volg je energieverbruik en de productie van je zonnepanelen in real time op je smartphone. En krijg een zonnemelding: hét moment om meer van je eigen gratis energie te verbruiken: slim!
- Via de Luminus Monitor-app heb je in real time toegang tot je gegevens vanuit je digitale meter: je verbruik, productie en injectie.
- https://www.luminus.be/nl/prive/energieoplossingen/energycontrol-monitor/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 (https://www.luminus.be/nl/prive/energieoplossingen/energycontrol-monitor/)
5) Bolt
- Beschrijving:
Bolt is het allereerste energieplatform dat het Belgische stroomnet echt duurzaam wil maken. Via Bolt kan je jouw energie rechtstreeks kopen van lokale, groene opwekkers. Zo weet jij exact waar je energie vandaan komt en waar je geld naartoe gaat.
- Energieplatform om groene energie te kunnen kopen van lokale opwekkers
- https://www.boltenergie.be/nl/
6) Adax Neo Compact Elektrische Kachel WiFi
- Beschrijving:
Slimme elektrische kachel: je kan hem reguleren (tijd, temperatuur, via wifi) om enkel te verwarmen wanneer nodig, waardoor je minder verspilt als hij continue
aanstaat.
- Fysiek product, te regelen met een app

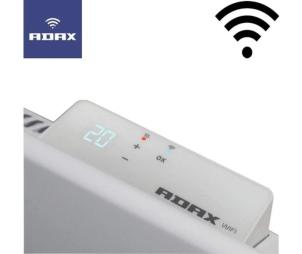
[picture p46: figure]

- https://dutchheating.nl/elektrische-kachels/elektrische-kachel-met-wifi-adax-neocompact-400w/ (https://dutchheating.nl/elektrische-kachels/elektrische-kachel-met-wifi-adax-neo-compact-400w/)

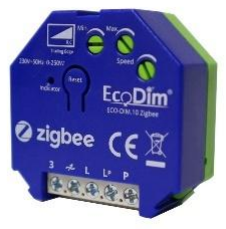
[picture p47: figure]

7) EcoDim LED Dimmer Module Zigbee
- Beschrijving:
Laat je verlichting dimmen of koppelen aan schema’s/sensoren; LED’s zijn al zuinig, dimmen maakt ze nog zuiniger; minder licht wanneer niet nodig → energiebesparing & comfort.
- Fysiek product om te installeren

- https://www.ecobright.be/zigbee-led-dimmer-module-250w-ecodim-10-zigbee.html (https://www.ecobright.be/zigbee-led-dimmer-module-250w-ecodim-10-zigbee.html)
8) ECOWITT Zonne-Weerstation GW1101

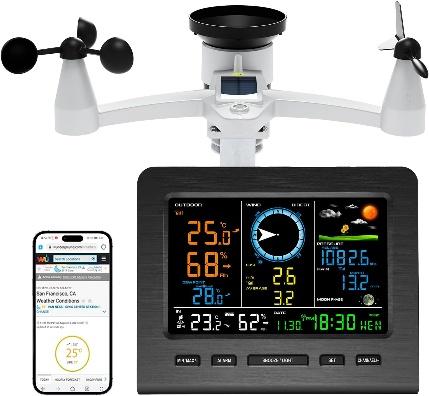
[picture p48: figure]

- Beschrijving:
Meet buitenklimaat (o.a. temperatuur, luchtvochtigheid, regen, zon) en werkt deels op zonne-energie; helpt gebruikers om te bepalen wanneer te ventileren of wanneer directe zon in huis zorgt voor opwarming → je kan gedragsaanpassingen doen (ramen sluiten/openen, gordijnen gebruiken).
- Fysiek product met app
- https://www.amazon.com.au/ECOWITT-Weather-Station-Powered-Outdoor/dp/B07R1Y72G4?th=1 (https://www.amazon.com.au/ECOWITT-Weather-Station-Powered-Outdoor/dp/B07R1Y72G4?th=1)
9) Smart Plug

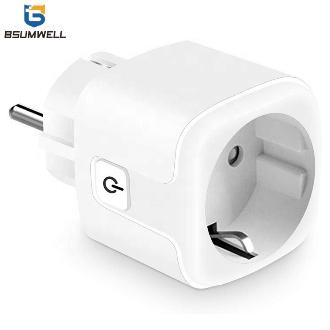
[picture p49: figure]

- Beschrijving:
Smart plugs komen in verschillende vormen en kleuren, uitgebracht door verschillende merken. Een smart plug is een slim stopcontact dat je tussen het toestel en het gewone stopcontact plaatst. Via een app, timer of spraakassistent kun je het aangesloten apparaat op afstand aan- of uitschakelen, en bij veel modellen kun je ook het energieverbruik meten. Zo helpt een smart plug om sluipverbruik te verminderen, automatische schema’s in te stellen en bewuster met energie om te gaan.
- Fysiek product, vaak met app
- Nadelen: werkt per stopcontact
- https://www.seniorweb.nl/artikel/alles-over-slimme-stekkers
10) Eneco Smart Meter App
- Beschrijving:
De app geeft in overzichtelijke grafieken weer hoeveel gas en elektriciteit je verbruikt, en wanneer. Het laat zien wat je verbuikt per categorie, waardoor je controle krijgt over je energiebudget.
- App
- https://eneco.be/nl/energieoplossingen/eneco-app/

### Verwerking

Deze benchmarks zijn in 3 grote categoriën te verdelen. Enerzijds zijn er de High-end integraties zoals EMS, Smappee en domotica. Dit zijn benchmarks die het automatiseren om duurzamer te leven. Echter vragen deze wel installatie, expertise en budget. De tweede grote categorie zijn apps en platforms zoals Eneco app, EnergyControl, Bolt. De laatste categorie valt onder fysieke producten. Een smart plug, dimmer, weerstation of elektrische kachel zijn concrete kleine interventies die het gedrag beïnvloeden of automatiseren op toestel-niveau.
Dit kan dus gecombineerd worden naar een fysiek product dat zich niet beperkt tot enkel toestel-niveau maar meer is dan enkel een app, zodat dit zeker gedragssturend is. Er is dus nog ruimte voor eenvoudige, centrale, visuele feedback die zonder grote investeringen meteen toepasbaar is in het dagelijkse huishouden.

### Bronnen

Adax. (z.j.). Adax Neo Compact – elektrische kachel met WiFi 400 W [Productpagina]. Geraadpleegd op 29 oktober 2025, van https://dutchheating.nl/elektrische-kachels/elektrische-kachel-met-wifi-adax-neo-compact-400w/ (https://dutchheating.nl/elektrische-kachels/elektrische-kachel-met-wifi-adax-neo-compact-400w/)

Aetec. (z.j.). Wat is een Energy Management System (EMS) en wat doet het? Geraadpleegd op 29 oktober 2025, van https://aetec.be/wat-is-een-energy-managementsystem-ems-en-wat-doet-het/ (https://aetec.be/wat-is-een-energy-management-system-ems-en-wat-doet-het/?utm_source=chatgpt.com)

Bolt Energie. (z.j.). Home. Geraadpleegd op 29 oktober 2025, van https://www.boltenergie.be/nl/

Ecobright. (z.j.). Zigbee led dimmer module 250 W | ECO-DIM.10 Zigbee. Geraadpleegd op
29 oktober 2025, van https://www.ecobright.be/zigbee-led-dimmer-module-250w-ecodim-10-zigbee.html (https://www.ecobright.be/zigbee-led-dimmer-module-250w-ecodim-10-zigbee.html?utm_source=chatgpt.com)

ECOWITT. (z.j.). Weather Station (model GW1101 / B07R1Y72G4) [Productpagina]. Geraadpleegd op 29 oktober 2025, van https://www.amazon.com.au/ECOWITT-Weather-Station-Powered-Outdoor/dp/B07R1Y72G4?th=1 (https://www.amazon.com.au/ECOWITT-Weather-Station-Powered-Outdoor/dp/B07R1Y72G4?th=1)

Eneco. (z.j.). Eneco Smart Meter app. Geraadpleegd op 29 oktober 2025, van https://www.eneco.be/nl/energieoplossingen/eneco-app

Luminus. (z.j.). EnergyControl Monitor. Geraadpleegd op 29 oktober 2025, van https://www.luminus.be/nl/prive/energieoplossingen/energycontrol-monitor/

SeniorWeb. (2025, 1 oktober). Alles over slimme stekkers. Geraadpleegd op 29 oktober 2025, van https://www.seniorweb.nl/artikel/alles-over-slimme-stekkers

Smappee. (z.j.). Energy management. Geraadpleegd op 29 oktober 2025, van https://www.smappee.com/nl/energiemanagement/

Somfy. (z.j.). Domotica in huis. Geraadpleegd op 29 oktober 2025, van https://www.somfy.be/nl-be/keuzehulp/domotica/in-huis

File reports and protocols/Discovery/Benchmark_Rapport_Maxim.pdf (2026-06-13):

# Benchmarkanalyse – report

Projectinformatie
Projectnaam: Sustainability at home
Onderzoekstype: Bechmarkanalyse
Onderzoeker: Depever Maxim (Student Industrieel Ontwerp aan UGent campus Kortrijk)

Samenvatting van protocol
Voor de verkenningsfase voor sustainablity at home is er onder anderen gekozen voor een benchmarkanalyse. Het doel hiervan is uit bestaande oplossingen van concurrenten informatie te halen over hun interpretatie van een energiemeter. Door deze toestellen met elkaar te vergelijken, kan er ingespeeld worden op de zwaktes en sterktes om zo toekomstige apparaten te verbeteren en te perfectioneren voor het juiste doelpubliek, wat in dit geval gezinnen zijn die willen besparen.

Motivatie voor methodekeuze
Door benchmarks uit te voeren wordt er een beter begrip over de toestellen verworven en kan er een beter idee gecreëerd worden omtrent er gecreëerd moet worden. Op deze manier kan er ingespeeld worden op de vlakken waar concurrenten nog niet naar gekeken hebben om zo iets nieuws en beters te maken.

Beschrijving van de sample (bronnen)
Er werden 10 toestellen met elkaar vergeleken. Wat deze toestellen gemeenschappelijk hebben is dat ze allemaal energiemeters zijn. Deze toestellen zijn dan in Tabel 1 gedetailleerd uitgeschreven om ze zo eenvoudig te kunnen vergelijken.
Nr. | Naam / Merk | Functie | Technologie | Doel | Prijs | Sterktes | Zwaktes
1 Niko | starterskit met Home Control | Informatie geven over elektriciteits-en gasverbruik | Solar modus, real-time informatie via app, | Geeft een overzicht van je energieverbruik om je bewust te maken en helpt actief mee om het te verminderen | €390 | Automatische opwekking van stekkers indien zonnepanelen veel energie leveren => Geeft zelf opgewekte energie voorrang | Informatie en feedback enkel toegankelijk met app
2 Sencys | verbruiksme ter | Nauwkeurige energiemeter | LCD scherm, compatibel et Franse stopcontacten (230 V – 50Hz) | Helpt met besparen van energie en is een hulpmiddel om verbruik op te volgen | €8,20 | Nauwkeurige metingen met een foutmarge van ± 2 %, kinderbeveiliging, scherm recht boven stopcontact | Kan slechts metingen uitvoeren over 1 stopcontact

3 Pitt & Co | Energiemete r | Meet verbruik en berekend direct de kosten | Meter van vermogen, spanning, berekent kosten | Energiekosten doen dalen | €26,9 5 | Kosten berekenen | Werkt slechts voor 1 stopcontact
4 Gologi | slimme stekker | Apparaten omvormen naar slimme toestellen | App remote control, voice control, countdownfunctie, device sharing | Apparaten op afstand besturen met een app of voice control | €15 | Stembediening, energiemonitoring , automatisch aan en uitschakelen van toestellen | Kan telkens maar 1 toestel besturen
5 | Smart Plug | Stekker add-on die verbruik trekt maar ook toestel kan uitschakelen | App remote control, voice control, countdownfunctie, device sharing | Apparaten op afstand bedienen | €22 | Werkt zelfstandig en heft geen extra benodigdheden | Kan telkens maar 1 toestel besturen
6 Homewizard | Energy Display | Scherm voor visualisatie van verbruik | Inzicht over stroom afname, inzicht over terugleveringen, inzichten over gas | Visualiseren van verbruik om mensen bewust te maken van het verbruik. | €60 | Eenvoudig scherm die je kan plaatsen waar je wil. Scherm customizable afhankelijk van gegevens die je wil | Zeer veel grafieken die voor mensen die het eenvoudig houden voor verwarring kan zorgen

7 Homewizard | p1 | Visualiseren van verbruik | Plug-in in P1 poort van meter, app met real-time updates en informatie | Visualiseren van verbruik om mensen bewust te maken van het verbruik. | €25 | Zeer gebruiksvriendelij k met makkelijke installatie, goedkoop | Zeer veel grafieken die voor mensen die het eenvoudig houden voor verwarring kan zorgen
8 Acti9 | iEM3000 series | energiemeter | Meet actief en reactief vermogen, pulsuitgang lezen energie, LED indicatie lamp | Informeren op verbruik energie en helpen besparen | €150 -€250 | Identificeert mogelijkheden om energie te besparen met hoge nauwkeurigheid | Niet gebruiksvriendelijk voor gewone huishouden. Eerder ontworpen voor bedrijven
9 PowerLogic | EM3000 series | Stroomteller/ energiemeter | LCD scherm, compatibel met Building Management Systeem | Meten van real-time verbruik | €200 -€300 | Veel variaties die afstemmen op behoeftes, bewaart gegevens en analyseert | Zeer ingewikkeld en toont enkel verbruik van stroom zonder waarschuwingen of feedback
10 | Voltmasters | Slimme energiemanag er voor bedrijven | Slimme sturing door machine learning, toestellen aansturen, inspelen op elektriciteitsprijzen | Energiekosten verminderen en extra inkomen genereren | Niet genoe md | Geen complexe rapporten | Enkel voor bedrijven

Tabel 1: Benchmarks

Ruwe data (beschrijvingen & observaties)
- Veel toestellen zijn gecreëerd door Schneider Electric wat hun hoofd van de markt maakt op dit vlak
- Veel toestellen zijn gemaakt voor grote bedrijven en zijn niet evident te gebruiken in kleine huishouden
- De toestellen geven vaak enkel real-time informatie op een klein LCD scherm, die ofwel aan de meterkast staat, ofwel boven het stopcontact hangt. Deze informatie is vaak beperkt
- Hoewel sommige toestellen met applicaties komen die veel informatie geven over het verbruik, is deze informatie vaak verwerkt in grafieken die allemaal op elkaar lijken waardoor er verwarring kan ontstaan wat elke grafiek telkens weergeeft.
- Vaak zijn deze toestellen niet kindvriendelijk waardoor ze niet gaan werken als motiverende factor om te besparen bij kinderen. In huishouden zijn het niet enkel de volwassenen die moeten besparen maar ook de kinderen anders kan er nog steeds een groot onnodig verbruik zijn.

Analyse
Nadien werden er 4 hoofdonderwerpen meer gedetailleerd aangekaart
a. Visuele weergave
b. toegankelijkheid
c. kwantiteit van metingen d.

Key Insights (Conclusies)

1. De huidige markt focust op data, niet op gedrag.
De meeste slimme producten informeren, maar motiveren niet. Gebruikers blijven passieve waarnemers.
2. Eenvoudige, visuele feedback ontbreekt.
De markt mist producten die intuïtief communiceren via kleur, vorm of beweging, zonder scherm of app.
3. Er is een kloof tussen high-end en low-end systemen.
Professionele domotica is te duur; goedkopere alternatieven missen diepgang.

4. Renovatiecontext biedt een ideaal instapmoment.
Tijdens renovatie staan bewoners open voor nieuwe technologieën, een slimme feedbackmodule kan geïntegreerd worden zonder extra moeite.
5. Comfort blijft doorslaggevend.
Een oplossing die comfort behoudt of verhoogt, heeft meer kans op langdurig gebruik.

Implicaties voor ontwerp
- Eenvoud en automatisering.
Een product dat automatisch verbruik detecteert en besparingsadviezen geeft, zonder ingewikkelde instellingen.
- Gebruik ‘ambient’ feedback i.p.v. cijfers.
Bijvoorbeeld: via kleurverandering, lichtintensiteit of subtiele vormaanpassingen. Dit maakt besparen voelbaar, niet abstract.
- Integreer meerdere bronnen (energie, ventilatie) in één interface.
Eén centraal punt dat overzicht biedt in plaats van losse apps.
- Zorg voor directe relevantie tijdens renovaties.
Een systeem dat relatief eenvoudig valt te installeren.

Bronnen

AquaSave. (z.d.). AquaSave smart shower timer. Geraadpleegd op 9 oktober 2025, van https://www.aquasave.com

DesignBoom. (2022, 14 mei). Energy Blossom: an ambient feedback concept for sustainable behavior. Geraadpleegd van https://www.designboom.com

Ecobee Inc. (2025). Ecobee Smart Thermostat Premium. Geraadpleegd op 9 oktober 2025, van https://www.ecobee.com

Eve Systems. (2025). Eve Energy – Smart Plug & Power Meter. Geraadpleegd op 9 oktober 2025, van https://www.evehome.com

Google. (2025). Google Nest Hub (2nd Gen). Geraadpleegd op 9 oktober 2025, van https://store.google.com

IKEA. (2025). Dirigera hub + Home Smart system. Geraadpleegd op 9 oktober 2025, van https://www.ikea.com

Netatmo. (2025). Smart Indoor Air Quality Monitor. Geraadpleegd op 9 oktober 2025, van https://www.netatmo.com

NIKO. (2025). NIKO Home Control – Domotica voor woningen. Geraadpleegd op 9 oktober 2025, van https://www.niko.eu

Sense Labs Inc. (2025). Sense Home Energy Monitor. Geraadpleegd op 9 oktober 2025, van https://sense.com

Tado°. (2025). Smart Thermostat – Intelligent heating control. Geraadpleegd op 9 oktober 2025, van https://www.tado.com

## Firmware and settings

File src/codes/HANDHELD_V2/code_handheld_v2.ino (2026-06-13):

#define USE_TFT_ESPI_LIBRARY
// Dit laadt de nodige libraries
#include <Arduino.h>
#include <lvgl.h>
#include <TFT_eSPI.h>
#include <I2C_BM8563.h>
#include <Wire.h>
#include "lv_xiao_round_screen.h"
#include "ui.h"
#include <BLEDevice.h>
#include <BLEUtils.h>
#include <BLEScan.h>
#include <BLEClient.h>

I2C_BM8563 rtc(I2C_BM8563_DEFAULT_ADDRESS, Wire);
lv_obj_t* images[3];

// De unieke UUID's van de BLE service en characteristic van de hub. Deze moeten exact overeenkomen met die van de hub.

static BLEUUID serviceUUID("95ff7bf8-aa6f-4671-82d9-22a8931c5387");
static BLEUUID charUUID("95ff7bf8-aa6f-4671-82d9-22a8931c5388");

// doConnect is een vlag die aangeeft dat er een verbinding gemaakt moet worden. foundDevice slaat het gevonden hub device op. Dit systeem is nodig omdat de ESP32 geen BLE verbinding mag maken vanuit de scan callback — dat moet vanuit de hoofdloop.

static BLEClient* pClient = nullptr;
static BLERemoteCharacteristic* pRemoteChar = nullptr;
static BLEScan* pBLEScan = nullptr;
static bool connected = false;
static bool signalActive = false;
static int activeFireIndex = -1;
static bool scanning = false;
static bool doConnect = false;
static BLEAdvertisedDevice* foundDevice = nullptr;

static uint32_t lastScanTime = 0;
static uint32_t lastClockTime = 0;
static uint32_t lastLvglTick = 0;

// -----------------------------------------------
// Detecteert een swipe gebaar op het touchscreen.
// -----------------------------------------------
void onSwipe(lv_event_t* e) {
  lv_dir_t dir = lv_indev_get_gesture_dir(lv_indev_get_act());
  lv_obj_t* currentScreen = lv_disp_get_scr_act(NULL);

  if (dir == LV_DIR_LEFT) {
    if (currentScreen == ui_Screen1) lv_disp_load_scr(ui_Screen2);
    else if (currentScreen == ui_Screen2) lv_disp_load_scr(ui_Screen3);
    else if (currentScreen == ui_Screen3) lv_disp_load_scr(ui_Screen4);
    else if (currentScreen == ui_Screen4) lv_disp_load_scr(ui_Screen1);
  } else if (dir == LV_DIR_RIGHT) {
    if (currentScreen == ui_Screen1) lv_disp_load_scr(ui_Screen4);
    else if (currentScreen == ui_Screen2) lv_disp_load_scr(ui_Screen1);
    else if (currentScreen == ui_Screen3) lv_disp_load_scr(ui_Screen2);
    else if (currentScreen == ui_Screen4) lv_disp_load_scr(ui_Screen3);
  }
}

// -----------------------------------------------
// Dit is de touchscreen driver voor LVGL. Het leest de aanraakcoördinaten van de CHSC6x touch controller en geeft ze door aan LVGL zodat het interface op aanraking kan reageren.
// -----------------------------------------------
void my_touchpad_read(lv_indev_drv_t *indev_driver, lv_indev_data_t *data) {
  lv_coord_t touchX = 0, touchY = 0;
  if (digitalRead(TOUCH_INT) == LOW) {
    chsc6x_get_xy(&touchX, &touchY);
    if (touchX > 0 && touchX < 240 && touchY > 0 && touchY < 240) {
      data->state = LV_INDEV_STATE_PR;
      data->point.x = touchX;
      data->point.y = touchY;
      return;
    }
  }
  data->state = LV_INDEV_STATE_REL;
}

// -----------------------------------------------
// Deze functie wordt automatisch aangeroepen wanneer de hub een BLE notificatie stuurt. Bij "SIGNAL" kiest het willekeurig een eiland, laadt dat scherm en toont het vlammetje. Bij "IDLE" verbergt het het vlammetje en gaat terug naar het hoofdscherm met de klok.
// -----------------------------------------------
void notifyCallback(BLERemoteCharacteristic* pChar, uint8_t* pData, size_t length, bool isNotify) {
  String value = "";
  for (int i = 0; i < length; i++) {
    value += (char)pData[i];
  }

  Serial.print("Ontvangen: ");
  Serial.println(value);

  if (value == "SIGNAL" && !signalActive) {
    signalActive = true;
    activeFireIndex = random(0, 3);

    if (activeFireIndex == 0) lv_disp_load_scr(ui_Screen2);
    else if (activeFireIndex == 1) lv_disp_load_scr(ui_Screen3);
    else lv_disp_load_scr(ui_Screen4);

    lv_obj_clear_flag(images[activeFireIndex], LV_OBJ_FLAG_HIDDEN);
    Serial.print("Vlammetje op eiland ");
    Serial.println(activeFireIndex);

  } else if (value == "IDLE" && signalActive) {
    signalActive = false;

    if (activeFireIndex >= 0) {
      lv_obj_add_flag(images[activeFireIndex], LV_OBJ_FLAG_HIDDEN);
      activeFireIndex = -1;
    }

    lv_disp_load_scr(ui_Screen1);
    Serial.println("Vlammetje gedoofd");
  }
}

// -----------------------------------------------
// Maakt de effectieve BLE verbinding met de hub, zoekt de juiste service en characteristic op en registreert notifyCallback zodat signalen automatisch ontvangen worden.
// -----------------------------------------------
bool connectToHub() {
  if (pClient == nullptr) {
    pClient = BLEDevice::createClient();
  }

  Serial.println("Verbinden met ZuinHub...");
  if (!pClient->connect(foundDevice)) {
    Serial.println("Connectie mislukt!");
    return false;
  }

  Serial.println("Verbonden!");

  BLERemoteService* pService = pClient->getService(serviceUUID);
  if (!pService) {
    Serial.println("Service niet gevonden!");
    pClient->disconnect();
    return false;
  }

  pRemoteChar = pService->getCharacteristic(charUUID);
  if (!pRemoteChar) {
    Serial.println("Characteristic niet gevonden!");
    pClient->disconnect();
    return false;
  }

  if (pRemoteChar->canNotify()) {
    pRemoteChar->registerForNotify(notifyCallback);
    Serial.println("Notify geregistreerd!");
  }

  connected = true;
  return true;
}

// -----------------------------------------------
// De scan callback die uitgevoerd wordt voor elk gevonden BLE device. Als de naam "ZuinHub" is, slaat het het device op en zet doConnect op true.
// -----------------------------------------------
class MyAdvertisedDeviceCallbacks : public BLEAdvertisedDeviceCallbacks {
  void onResult(BLEAdvertisedDevice advertisedDevice) {
    if (advertisedDevice.getName() == "ZuinHub") {
      Serial.println("ZuinHub gevonden!");
      pBLEScan->stop();
      scanning = false;
      foundDevice = new BLEAdvertisedDevice(advertisedDevice);
      doConnect = true;
    }
  }
};

// -----------------------------------------------
// Setup
// -----------------------------------------------
void setup() {
  Serial.begin(115200);
  Serial.println("Opstarten...");

  pinMode(D0, OUTPUT);
  digitalWrite(D0, HIGH);

  Wire.begin(5, 6);
  rtc.begin();

  // Initialiseert LVGL, de round display en het touchscreen.

  lv_init();
  lv_xiao_disp_init();
  delay(100);
  lv_xiao_touch_init();

  static lv_indev_drv_t indev_drv;
  lv_indev_drv_init(&indev_drv);
  indev_drv.type = LV_INDEV_TYPE_POINTER;
  indev_drv.read_cb = my_touchpad_read;
  lv_indev_drv_register(&indev_drv);

  //Laadt de SquareLine Studio interface en toont Screen1 (het klokscherm) als beginscherm.

  ui_init();
  lv_disp_load_scr(ui_Screen1);

  //Koppelt de drie vlammetje objecten uit de SquareLine UI aan een array en verbergt ze allemaal bij het opstarten.

  images[0] = ui_Fire2;
  images[1] = ui_Fire3;
  images[2] = ui_Fire4;

  // Alle vlammetjes verbergen bij start
  for (int i = 0; i < 3; i++) {
    lv_obj_add_flag(images[i], LV_OBJ_FLAG_HIDDEN);
  }

  // Swipe events toevoegen aan alle schermen
  lv_obj_add_event_cb(ui_Screen1, onSwipe, LV_EVENT_GESTURE, NULL);
  lv_obj_add_event_cb(ui_Screen2, onSwipe, LV_EVENT_GESTURE, NULL);
  lv_obj_add_event_cb(ui_Screen3, onSwipe, LV_EVENT_GESTURE, NULL);
  lv_obj_add_event_cb(ui_Screen4, onSwipe, LV_EVENT_GESTURE, NULL);

  I2C_BM8563_TimeTypeDef t;
  rtc.getTime(&t);
  char timeBuf[10];
  sprintf(timeBuf, "%02d:%02d:%02d", t.hours, t.minutes, t.seconds);
  lv_label_set_text(ui_ClockLabel, timeBuf);

  //Configureert de BLE scan — setInterval en setWindow zorgen dat de scan niet te veel CPU gebruikt zodat LVGL vlot blijft draaien.

  BLEDevice::init("ZuinHandheld");
  pBLEScan = BLEDevice::getScan();
  pBLEScan->setAdvertisedDeviceCallbacks(new MyAdvertisedDeviceCallbacks());
  pBLEScan->setActiveScan(true);
  pBLEScan->setInterval(100);
  pBLEScan->setWindow(50);

  Serial.println("Setup klaar!");
}

// -----------------------------------------------
// Dit is het hart van LVGL — lv_tick_inc vertelt LVGL hoeveel tijd er verstreken is en lv_timer_handler verwerkt alle animaties, events en hertekeningen. Dit moet zo snel mogelijk aangeroepen worden zonder delay().
// -----------------------------------------------
void loop() {
  uint32_t now = millis();

  lv_tick_inc(now - lastLvglTick);
  lastLvglTick = now;
  lv_timer_handler();

//Elke seconde wordt de tijd gelezen van de RTC klok en geüpdatet op het LCD label van Screen1.

  if (now - lastClockTime >= 1000) {
    lastClockTime = now;
    if (ui_ClockLabel != NULL) {
      I2C_BM8563_TimeTypeDef t;
      rtc.getTime(&t);
      char timeBuf[10];
      sprintf(timeBuf, "%02d:%02d:%02d", t.hours, t.minutes, t.seconds);
      lv_label_set_text(ui_ClockLabel, timeBuf);
      lv_obj_invalidate(ui_ClockLabel);
    }
  }

// Als de scan callback een hub gevonden heeft en doConnect op true gezet heeft, wordt hier de verbinding gemaakt vanuit de veilige context van de loop.

  if (doConnect) {
    doConnect = false;
    connectToHub();
  }

// Als er geen verbinding is herstart het scannen elke 5 seconden voor 3 seconden. Door intervallen te gebruiken in plaats van continu scannen blijft LVGL vlot draaien.

  if (!connected || (pClient && !pClient->isConnected())) {
    connected = false;
    if (!scanning && !doConnect && (now - lastScanTime >= 5000)) {
      lastScanTime = now;
      scanning = true;
      Serial.println("Scannen...");
      pBLEScan->start(3, false);
    }
  }
}

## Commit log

2025-11-12 Add Bill of Materials section to documentation
    Added a Bill of Materials section outlining required materials and resources for the prototype.
2025-11-18 Eerste deel van de github pagina geschreven
2026-01-03 Insert image for Tripel Diamond model
    Added image for the Tripel Diamond model in the README.
2026-01-18 BOM readme enzo aangepast
2026-01-18 Hyperlinks en bom afgeewerkt
2026-01-18 Bom mooier gemaakt
2026-01-18 Expand conclusions on market needs and user insights
    Added insights on market gaps for children's energy-saving devices and the need for real-time feedback.
2026-01-18 Update README with new prototypes and feedback details
    Added information about new prototypes and user feedback sessions.
2026-01-18 Revise README with expert insights and prototype updates
    Updated the README to include insights from expert consultations regarding the target age group and the importance of meaningful interactions in gamification.
2026-01-18 Update attachment counts and links in README
2026-01-19 Fix image filename case in README.md
2026-03-03 Update attachments section with new links and counts
2026-03-03 Create Develop_I.md
    Hier wordt alle informatie rond de Develop I fase geschreven
2026-03-08 Refine language in Kritische reflectie section
    Adjusted sentence structure for clarity and flow in the project reflection section.
2026-03-26 Iets proberen
2026-04-11 Hyperlinks in de README en design_requirements geupdate
2026-04-13 Add prototype images to Develop_II.md
    Added an image of prototypes to the documentation.
2026-05-10 Expand Develop III documentation with methodologies
    Added detailed sections on UX, Service Design, and CMF methodologies, including emotional design, user interviews, and material testing.
2026-05-10 Fix image source and update sample size note
    Corrected the image source in the flyer section and removed a line about sample size limitations.
2026-05-10 Update Develop_III.md with limitation note
    Added limitation note regarding sample size and qualitative results.
2026-05-22 Bom en cad bestanden toegevoegd
    [Bloc alim.SLDPRT, Bloc alim_sldprt.prt, Connecteur Grove LCD.SLDPRT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]
2026-05-22 Bom nog verder aangevuld
2026-05-25 Bom aangevuld
2026-06-11 Cad files horloge toegevoegd
    [Deksel.prt, ESP+scherm.prt, Horloge_assembly.prt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]
2026-06-12 Bom en PRD finaal aangepast
2026-06-13 Source code
    [Deksel.prt, ESP+scherm.prt, Horloge_assembly.prt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]
2026-06-13 Alle oude protocollen en rapporten verwijderd en de meest recente versies toegevoegd
2026-06-13 Noot inzake het gebruik van AI
